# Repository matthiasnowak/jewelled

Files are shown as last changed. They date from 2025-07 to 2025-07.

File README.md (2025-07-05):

# JewelLED / LuxAura Earring

Jewelled Hardware

These stylish earrings have 18 small LEDs on them, which can light up in any pattern. A microphone allows for the potential to sync the patterns up to music. The whole earring is powered off a regular coin cell battery, and can even be used with lithium rechargeable coin cells! It runs around 10-12h at moderate animation load and brightness of a LIR2032 rechargeable Lithium battery

A seperate charging and programming board allows to interface the earrings with your PC, gives you simple access to the programming pin of the earrings and can be used to charge them up if used with lithium rechargeable coin cells.

## Hardware Overview:

### LuxAura 01:

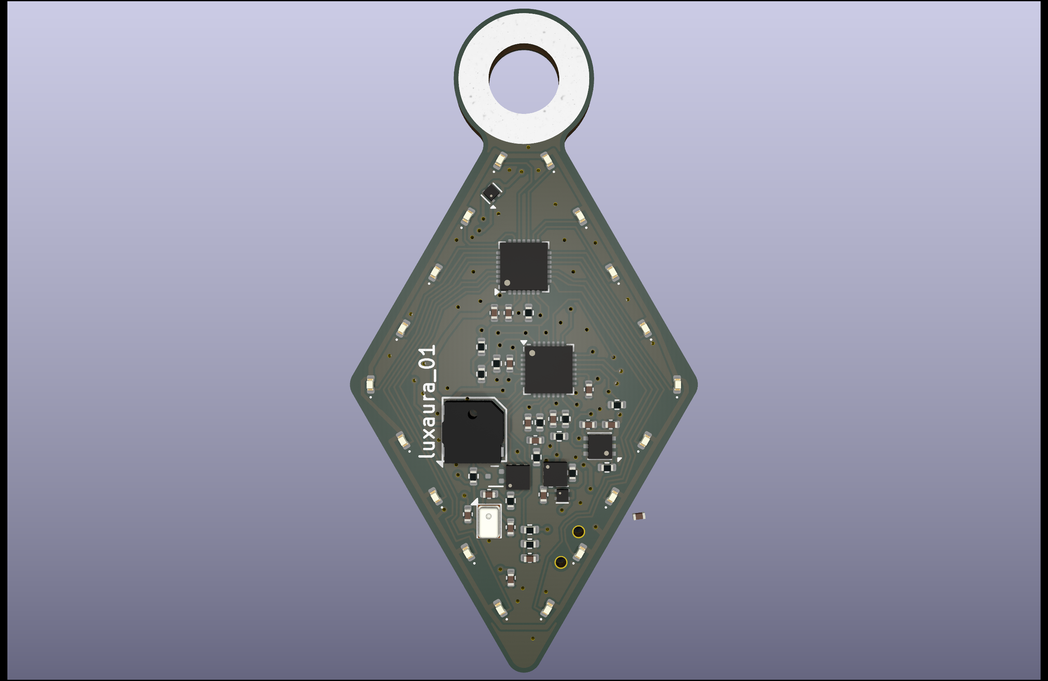
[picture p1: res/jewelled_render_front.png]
LuxAura 01 PCB Front


- WCH CH32V203G6U6 microcontroller
- 18 LEDs 0603, single color
- CR2032 battery holder
- optional LIR2032 charging and protection circuit
- Operating at 2.7V, allowing for low battery voltage operation
- 2 buttons and a power switch
- buzzer for audio user feedback
- microphone, which can be used for music detection

### LuxCharge:

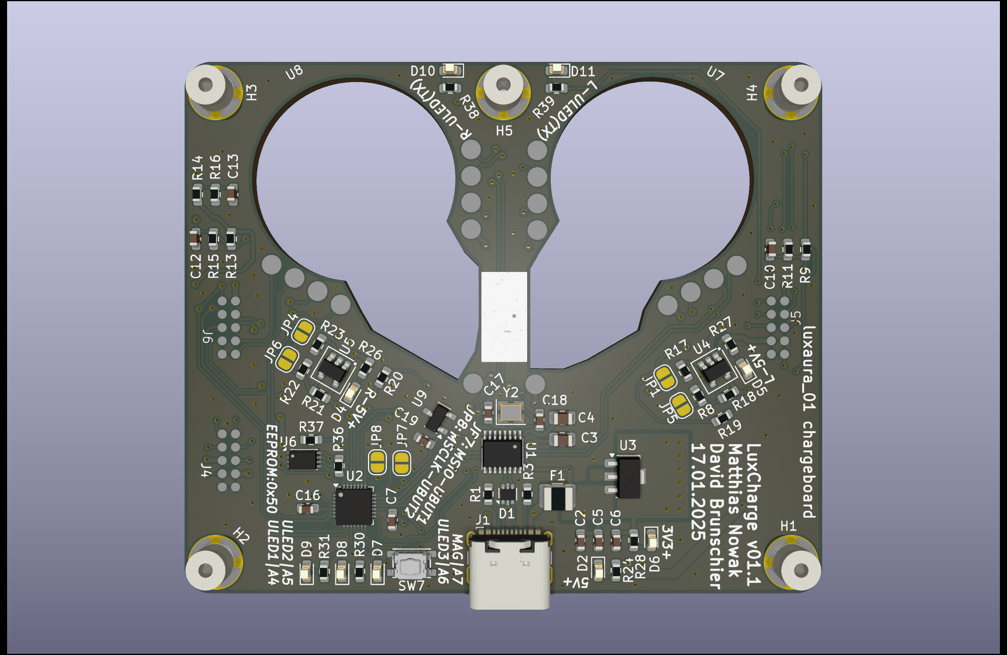
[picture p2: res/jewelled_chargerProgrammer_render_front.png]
LuxAura LuxCharge PCB Front


- TBD

## Software

Software is currently WIP. The charging board can activate/deactivate 5V charging voltage to the earrings and can rudimentely detect their presence.
The earring software can show basic animations and cycle between them. Test code for microphone sampling is running, but currently beat detection doesnt work.

## Ressources and other notes

- Images, schematics and PCB plots can be found in the "res" folder.
- Development is published here, issues are used for internal issue and project tracking. Feel free to contribute
- The PCBs can be ordered through Turnkey PCBA providers like JLCPCB.

## License

The attached LICENSE.md file contains information about the license.

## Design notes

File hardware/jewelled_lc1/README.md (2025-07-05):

# LuxAura 01 Earring Hardware

## Hardware Overview

- WIP

## Notes

- WIP
- Please note the correct jumper settings to allow either CR2032 or LIR2032 use (bridging the charging circuit)

## Images

LuxAura 01 PCB Render Front
LuxAura 01 PCB Render Back
LuxAura 01 PCB
LuxAura 01 Schematic

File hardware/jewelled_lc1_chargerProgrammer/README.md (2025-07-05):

# LuxAura LuxCharger Hardware

## Hardware Overview

- WIP

## Notes

- WIP
- Please note the correct jumper settings to allow communications or setting pullup/down resistors

## Images

LuxAura LuxCharge PCB Render Front
LuxAura LuxCharge PCB Render Back
LuxAura LuxCharge PCB
LuxAura LuxCharge Schematic

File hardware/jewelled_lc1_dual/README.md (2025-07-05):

# LuxAura 01 Dual Earring Hardware

## Notes

This is a panel meant for production of the Earrings, allowing for 2 Earrings per panel.

## Images

LuxAura 01 Dual PCB Render Front
LuxAura 01 Dual PCB Render Back
LuxAura 01 Dual PCB
LuxAura 01 Dual Schematic

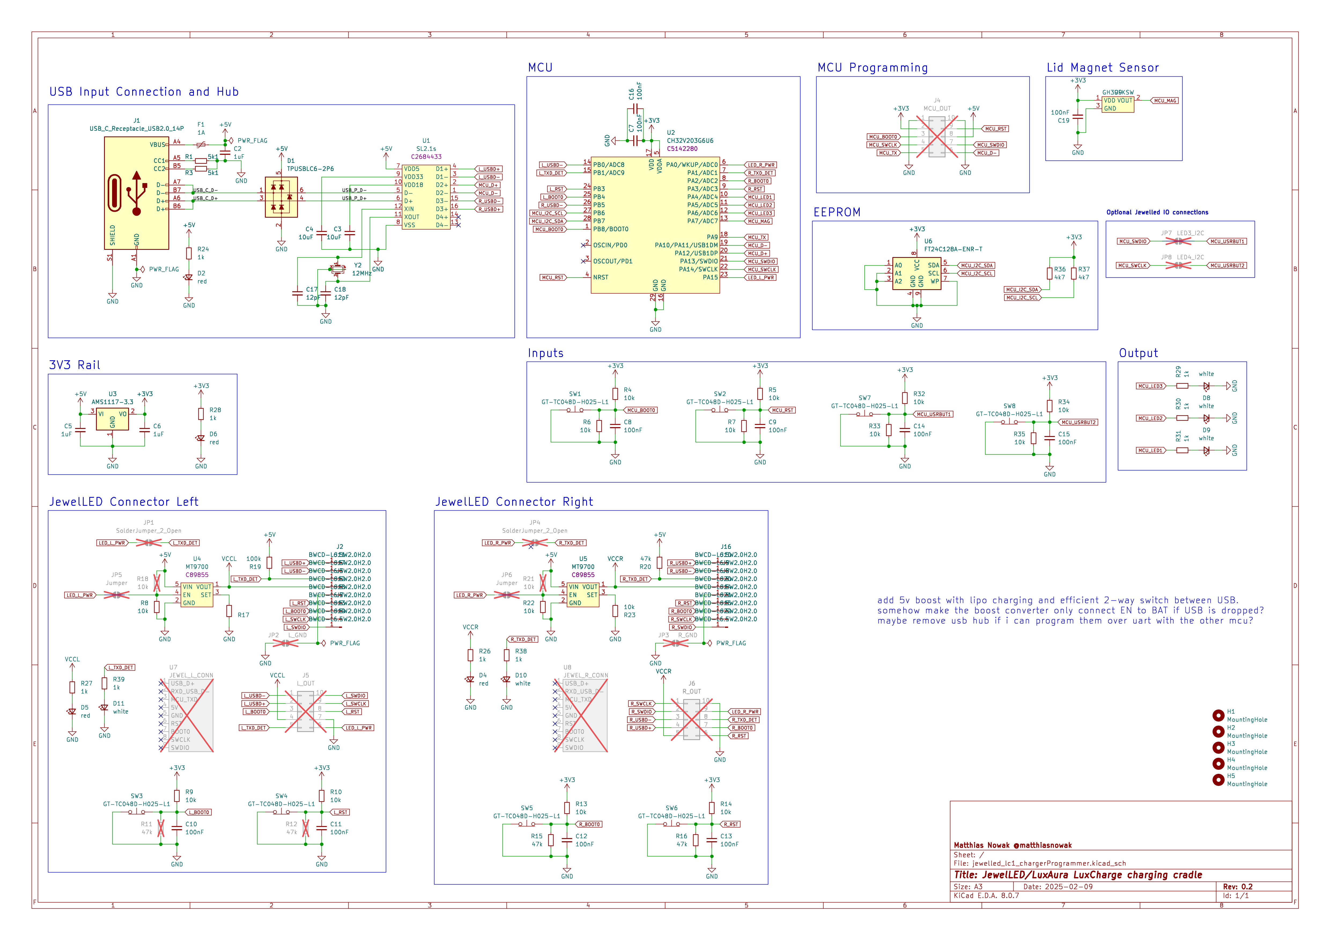
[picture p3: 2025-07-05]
res/jewelled_chargerProgrammer_schematic.png

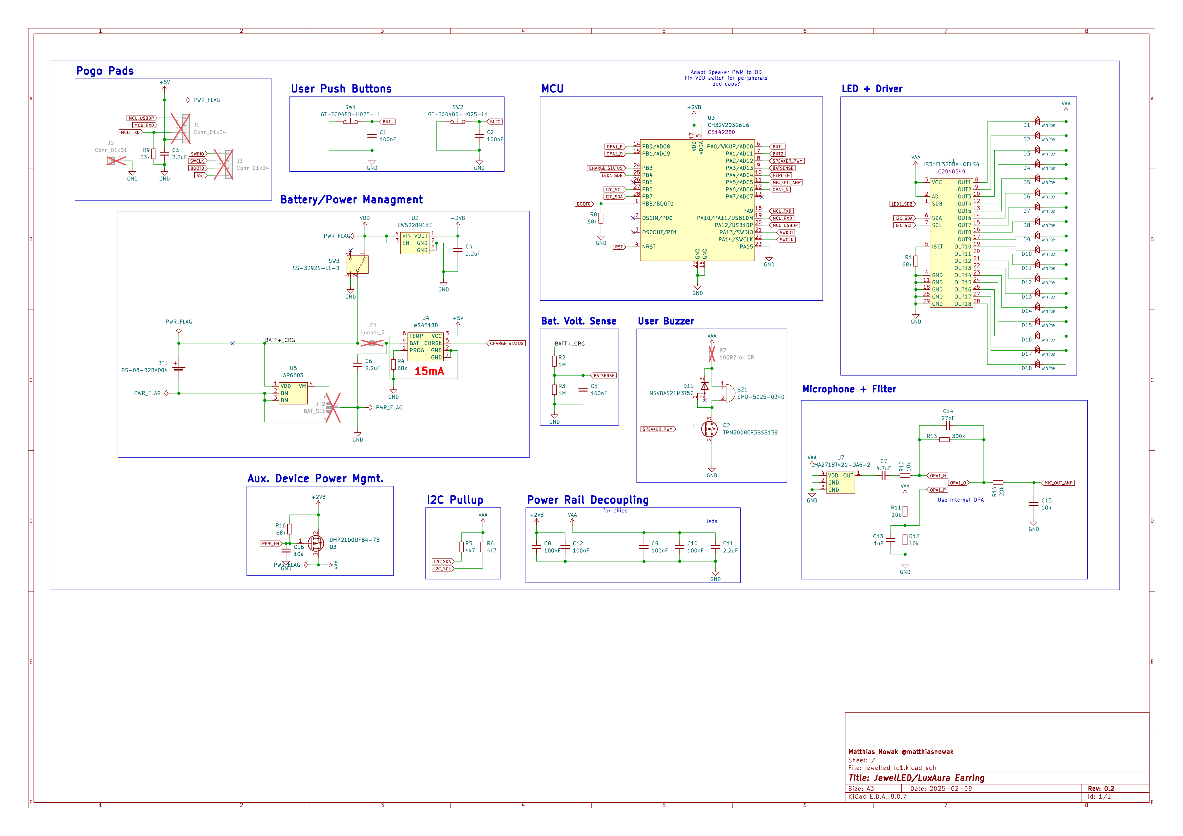
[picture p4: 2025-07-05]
res/jewelled_schematic.png

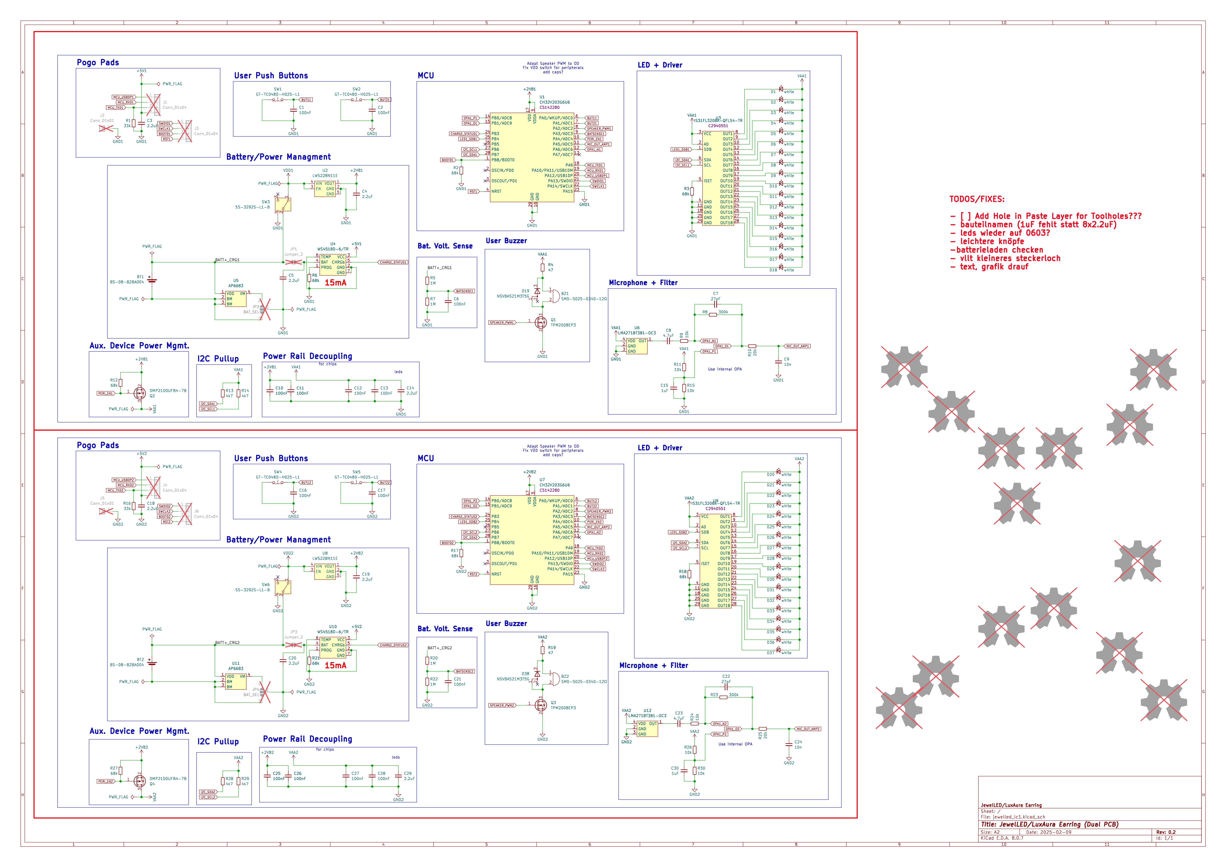
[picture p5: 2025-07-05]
res/jewelled_dual_schematic.png

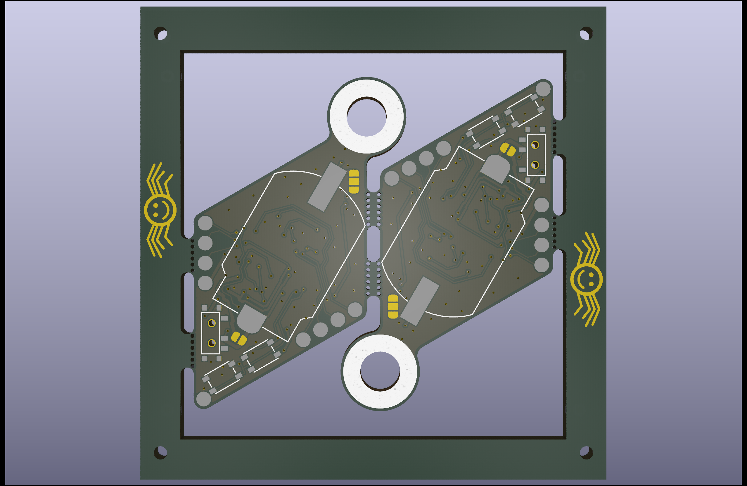
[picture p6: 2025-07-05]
res/jewelled_dual_render_back.png

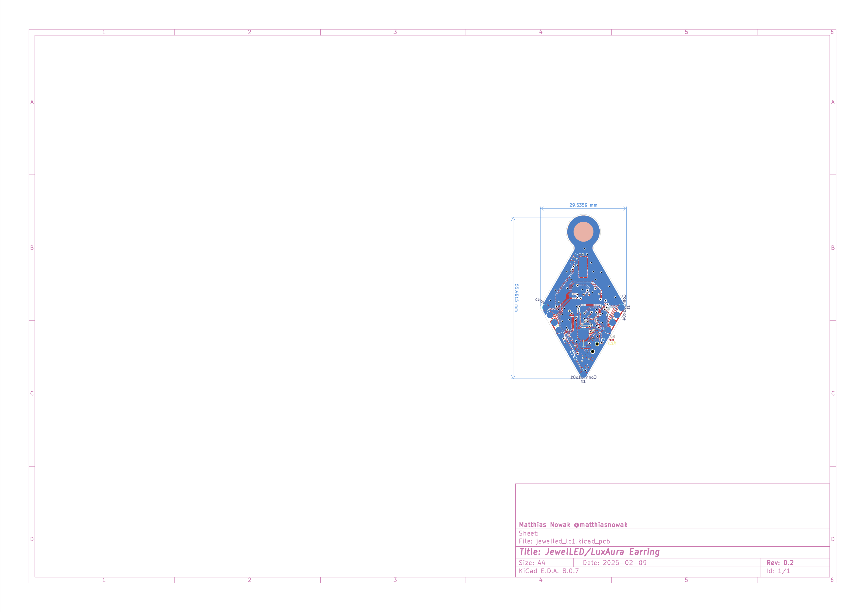
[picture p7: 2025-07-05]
res/jewelled_pcb_combined.png

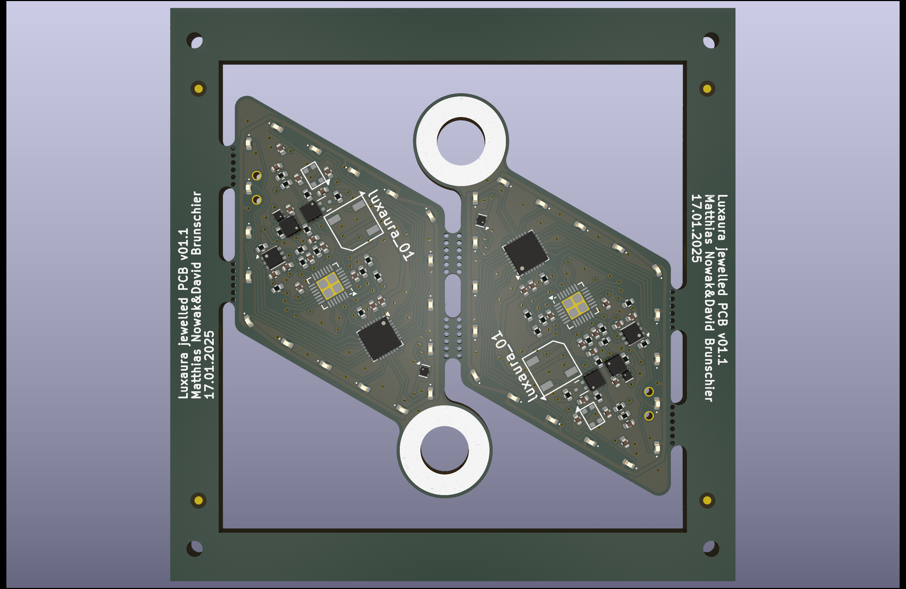
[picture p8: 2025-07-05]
res/jewelled_dual_render_front.png

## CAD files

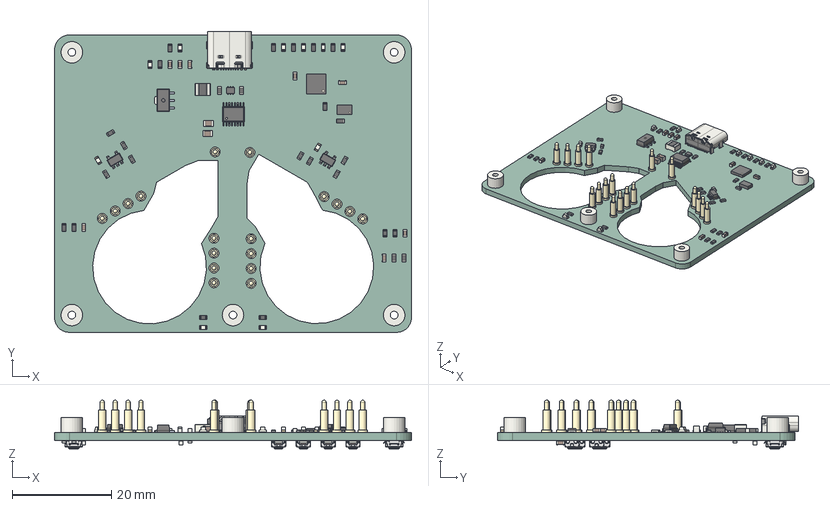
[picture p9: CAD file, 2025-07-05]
hardware/jewelled_lc1_chargerProgrammer/jewelled_lc1_chargerProgrammer.step
72.0 x 60.7 x 9.83 mm
SOT_23_5 x 2
R_0603_1608Metric x 33
C_0603_1608Metric x 14
LED_0603_1608Metric x 10
Fuse_1210_3225Metric
C_0805_2012Metric x 2
Mounting_Wuerth_WA_SMSI_M2_H3mm_9774030243 x 5
QFN-28-1EP_4x4mm_Pitch0.4mm
pogopin_fp v1 x 2
CQ assembly
SOT_666
SSOP_16_39x49mm_P0635mm
DFN-8-1EP_3x2mm_P0.5mm_EP1.7x1.6mm
USB_C_Receptacle_16P_TopMnt_Horizontal_GCT_USB4105-xx-A
jewelled_lc1_chargerProgrammer_PCB

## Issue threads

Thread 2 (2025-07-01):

Problems: Decide on pullup/downs for detection of the jewelleds in the charging cradle

matthiasnowak, 2025-07-01:
detection of jewelleds in the charging cradle still seems bit weird, especially in scenarios where the cradle is unpowered but the jewelled is still on. Probably is just a thing of calculating the correct pullup/down on the io and reset lines

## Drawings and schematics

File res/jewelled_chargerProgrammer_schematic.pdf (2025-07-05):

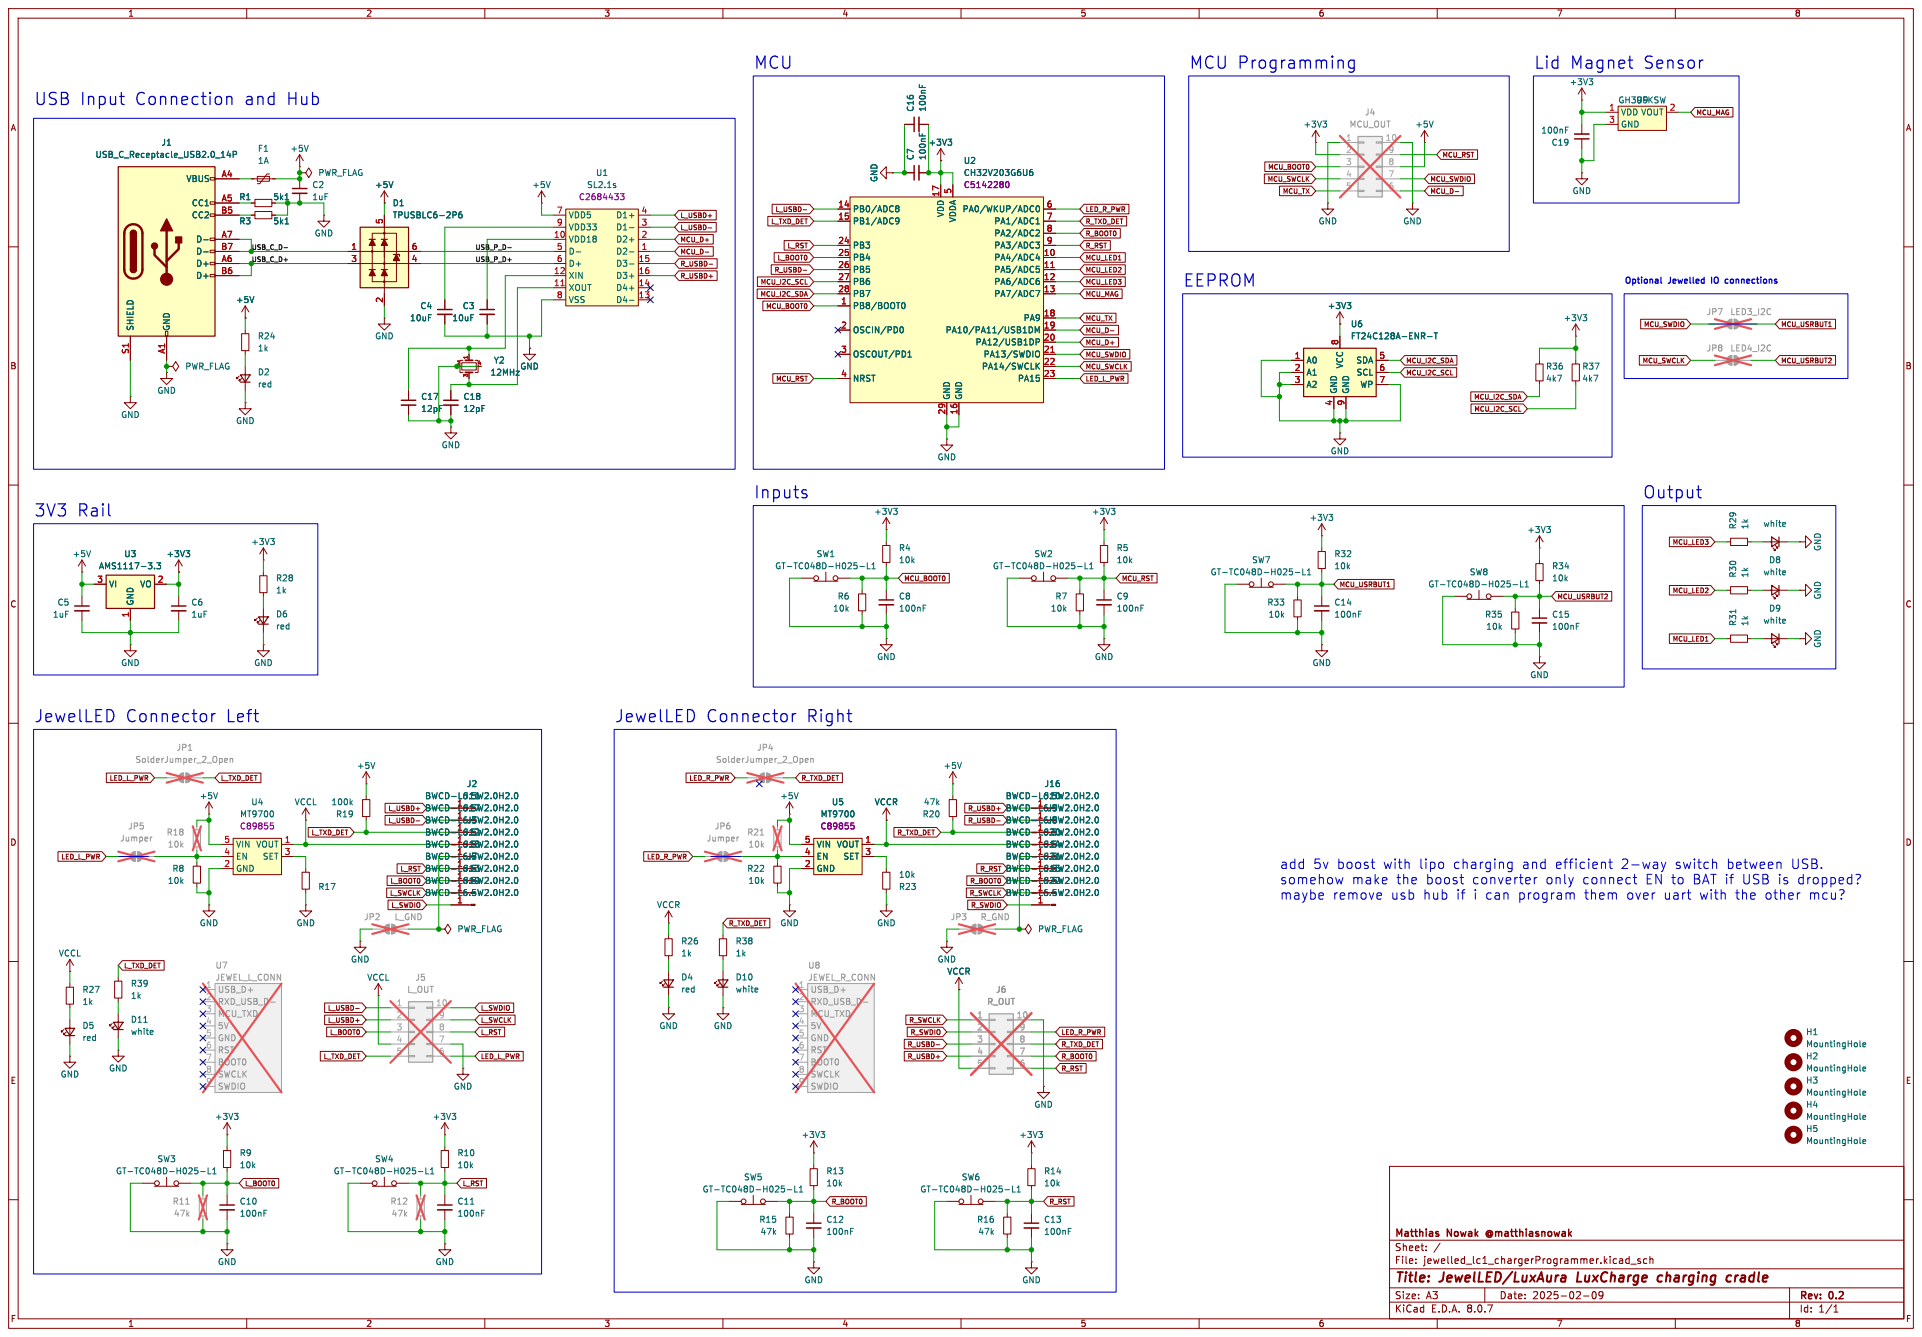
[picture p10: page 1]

USB Input Connection and Hub

Optional Jewelled IO connections Output

4 SDA 5 SCL 6 WP 7 VCC

somehow make the boost converter only connect EN to BAT if USB is dropped?
maybe remove usb hub if i can program them over uart with the other mcu?

H2 MountingHole H5 MountingHole H3 MountingHole H4 MountingHole H1 MountingHole

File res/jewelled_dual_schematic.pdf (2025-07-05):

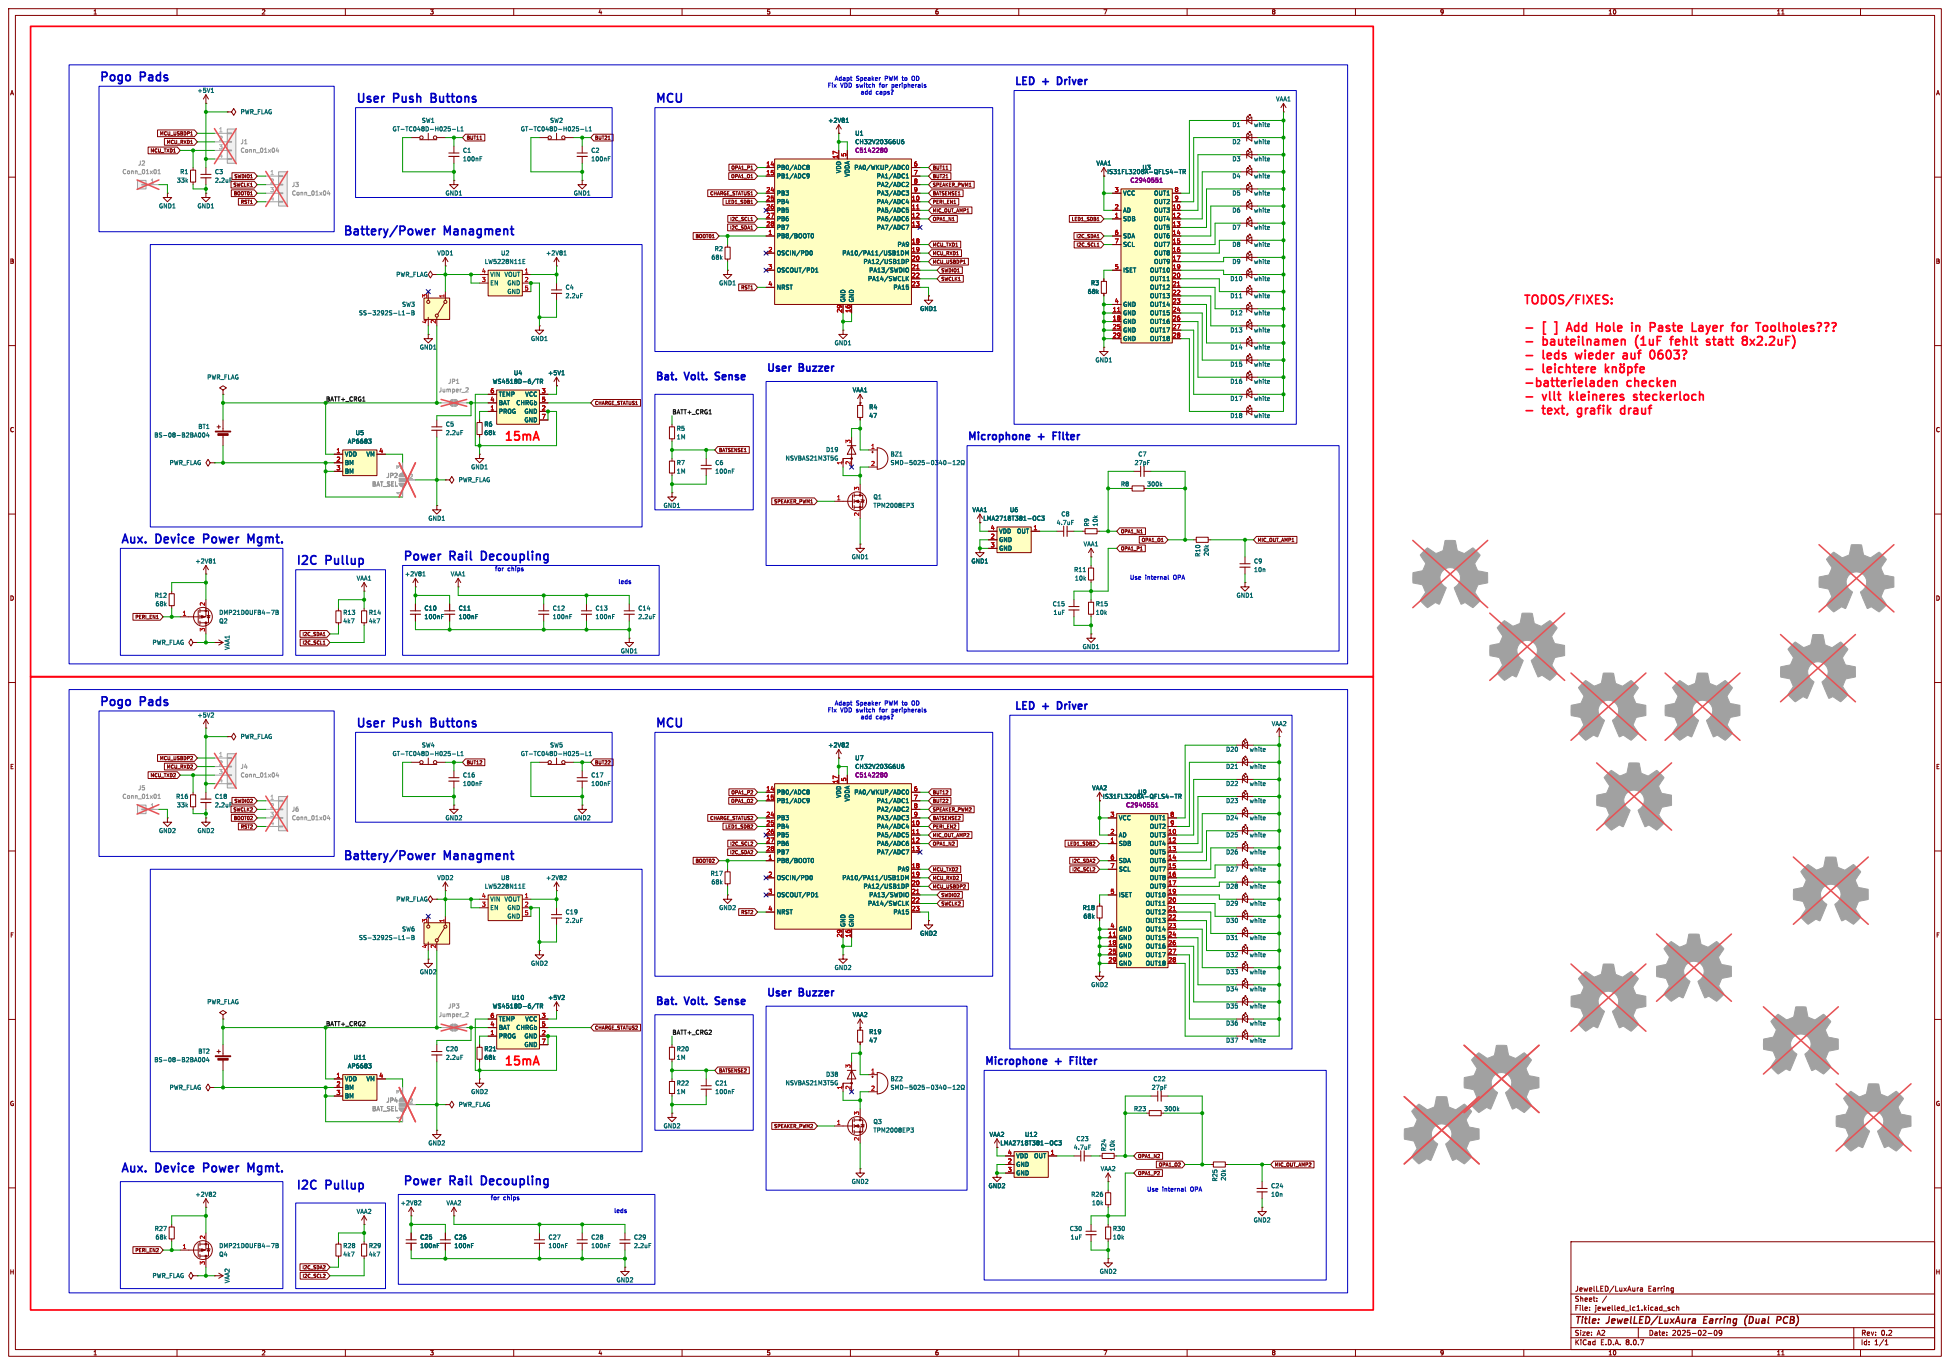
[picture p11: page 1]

Adapt Speaker PWM to OD
Fix VDD switch for peripherals add caps?

- [ ] Add Hole in Paste Layer for Toolholes???
- leds wieder auf 0603?
- leichtere þÿknöpfe
- vllt kleineres steckerloch
- text, grafik drauf

3 U5 AP6683 VDD 1 BM 2 BM 3 VM 4 C11

Aux. Device Power Mgmt.

LMA2718T381-OC3 PWR_FLAG

LMA2718T381-OC3 OUT 1 GND 2 GND 3 VDD 4

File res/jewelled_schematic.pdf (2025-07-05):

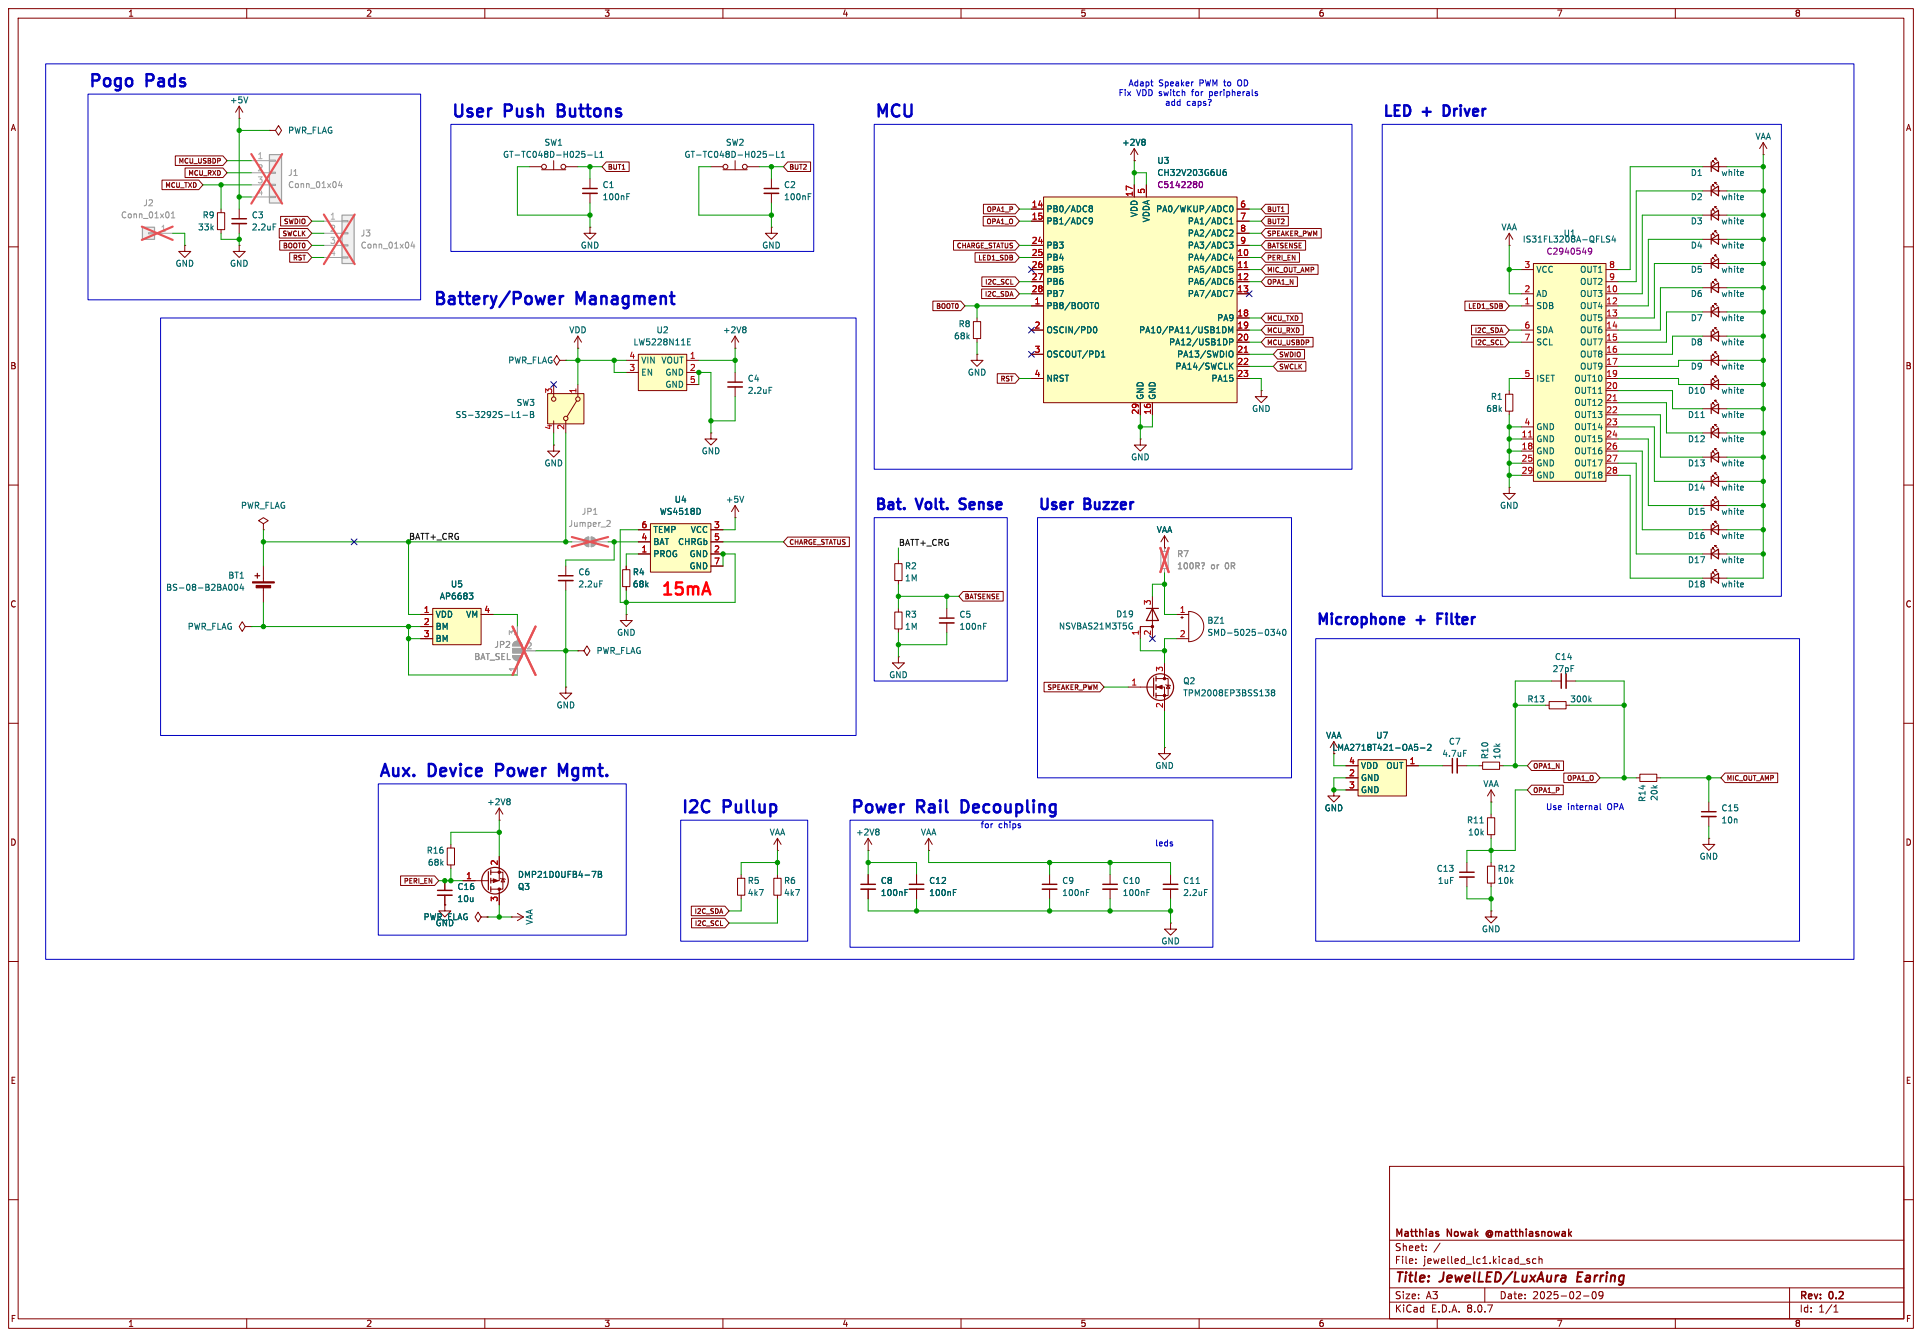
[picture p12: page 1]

Adapt Speaker PWM to OD
Fix VDD switch for peripherals add caps?

3 R4 U5 68k AP6683 VDD 1 BM 2 BM 3 VM 4 U4 WS4518D

LMA2718T421-OA5-2 OUT 1 GND 2 GND 3 VDD 4 VAA GND

Aux. Device Power Mgmt.

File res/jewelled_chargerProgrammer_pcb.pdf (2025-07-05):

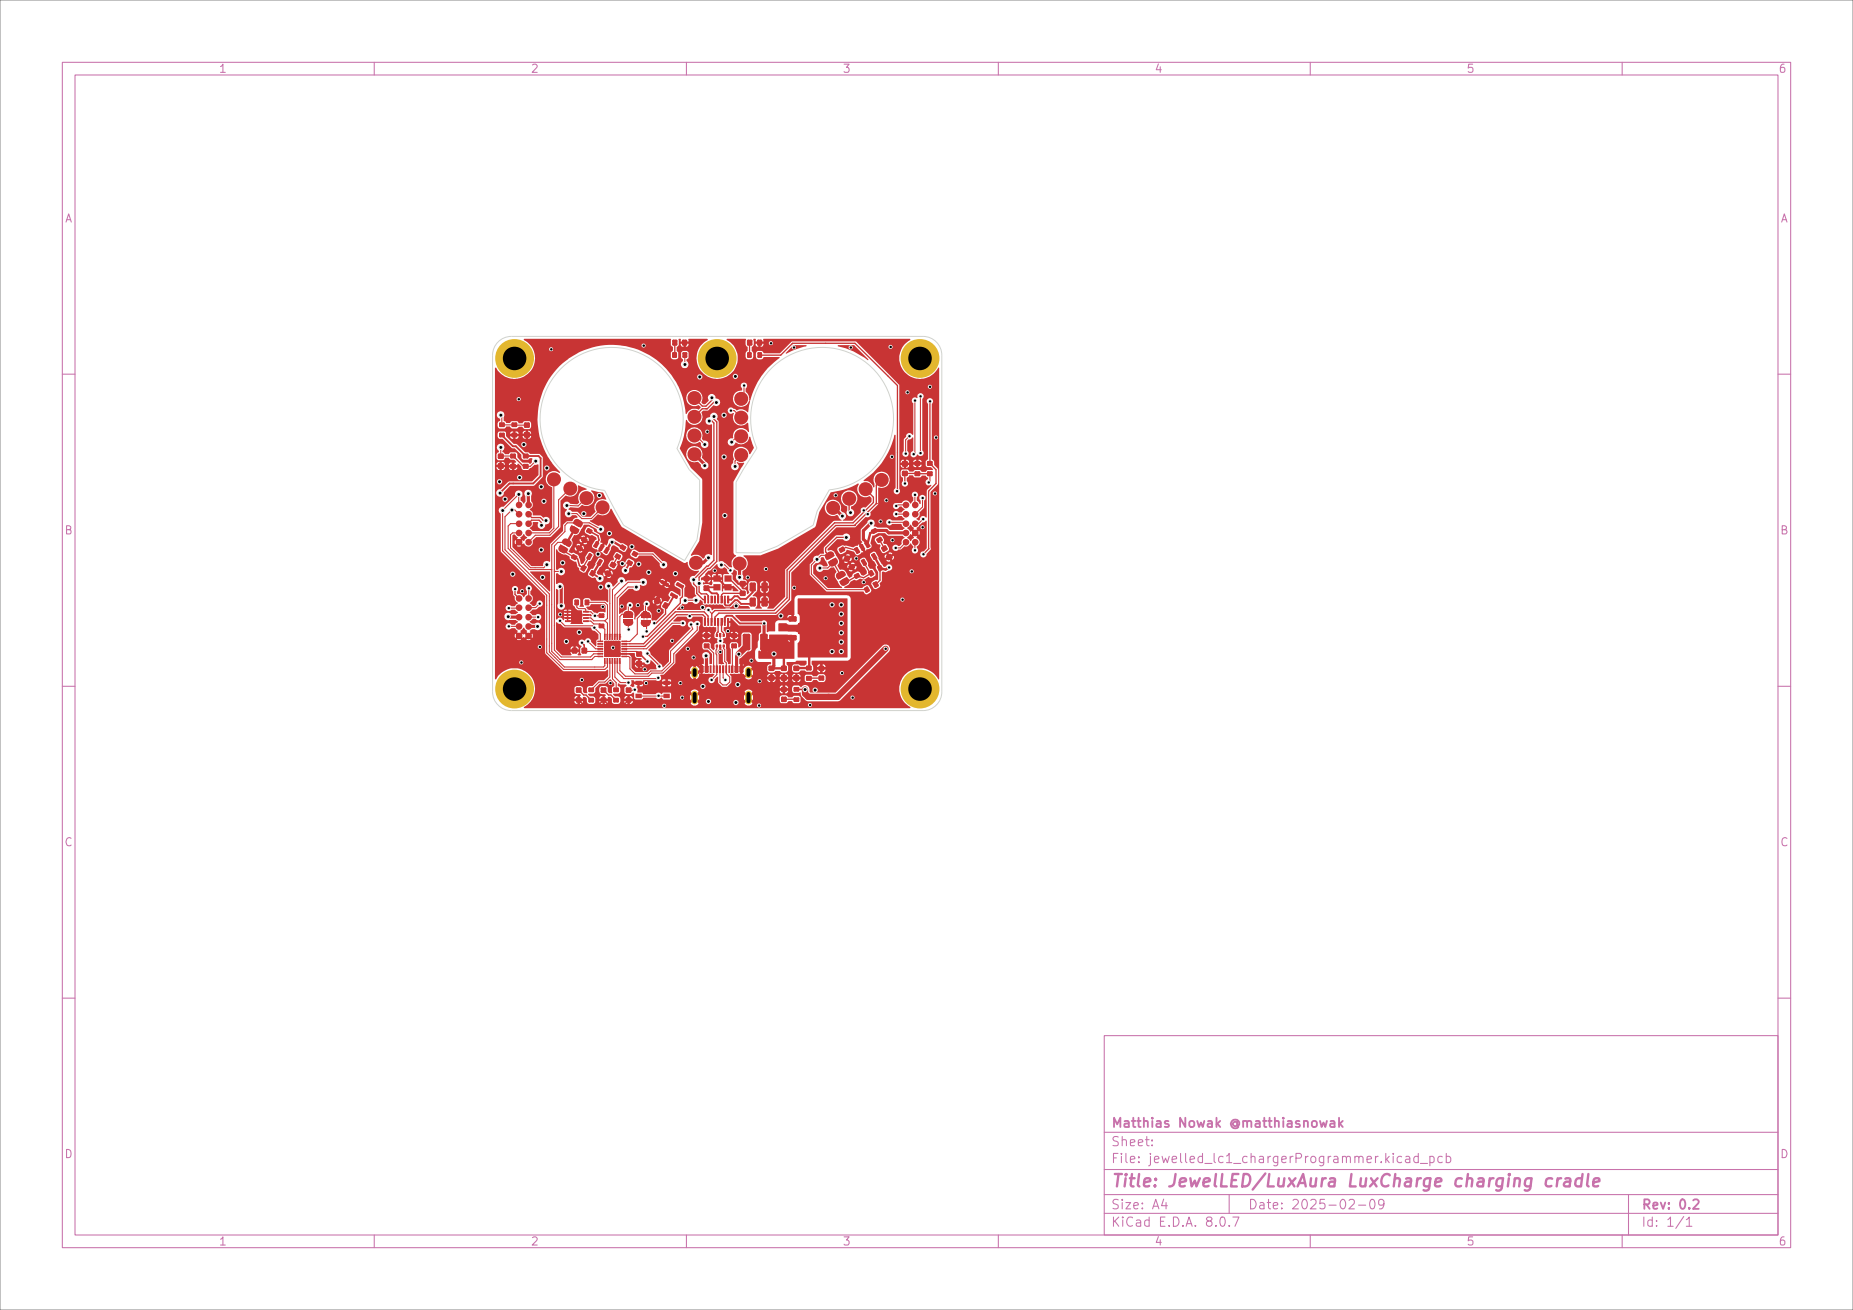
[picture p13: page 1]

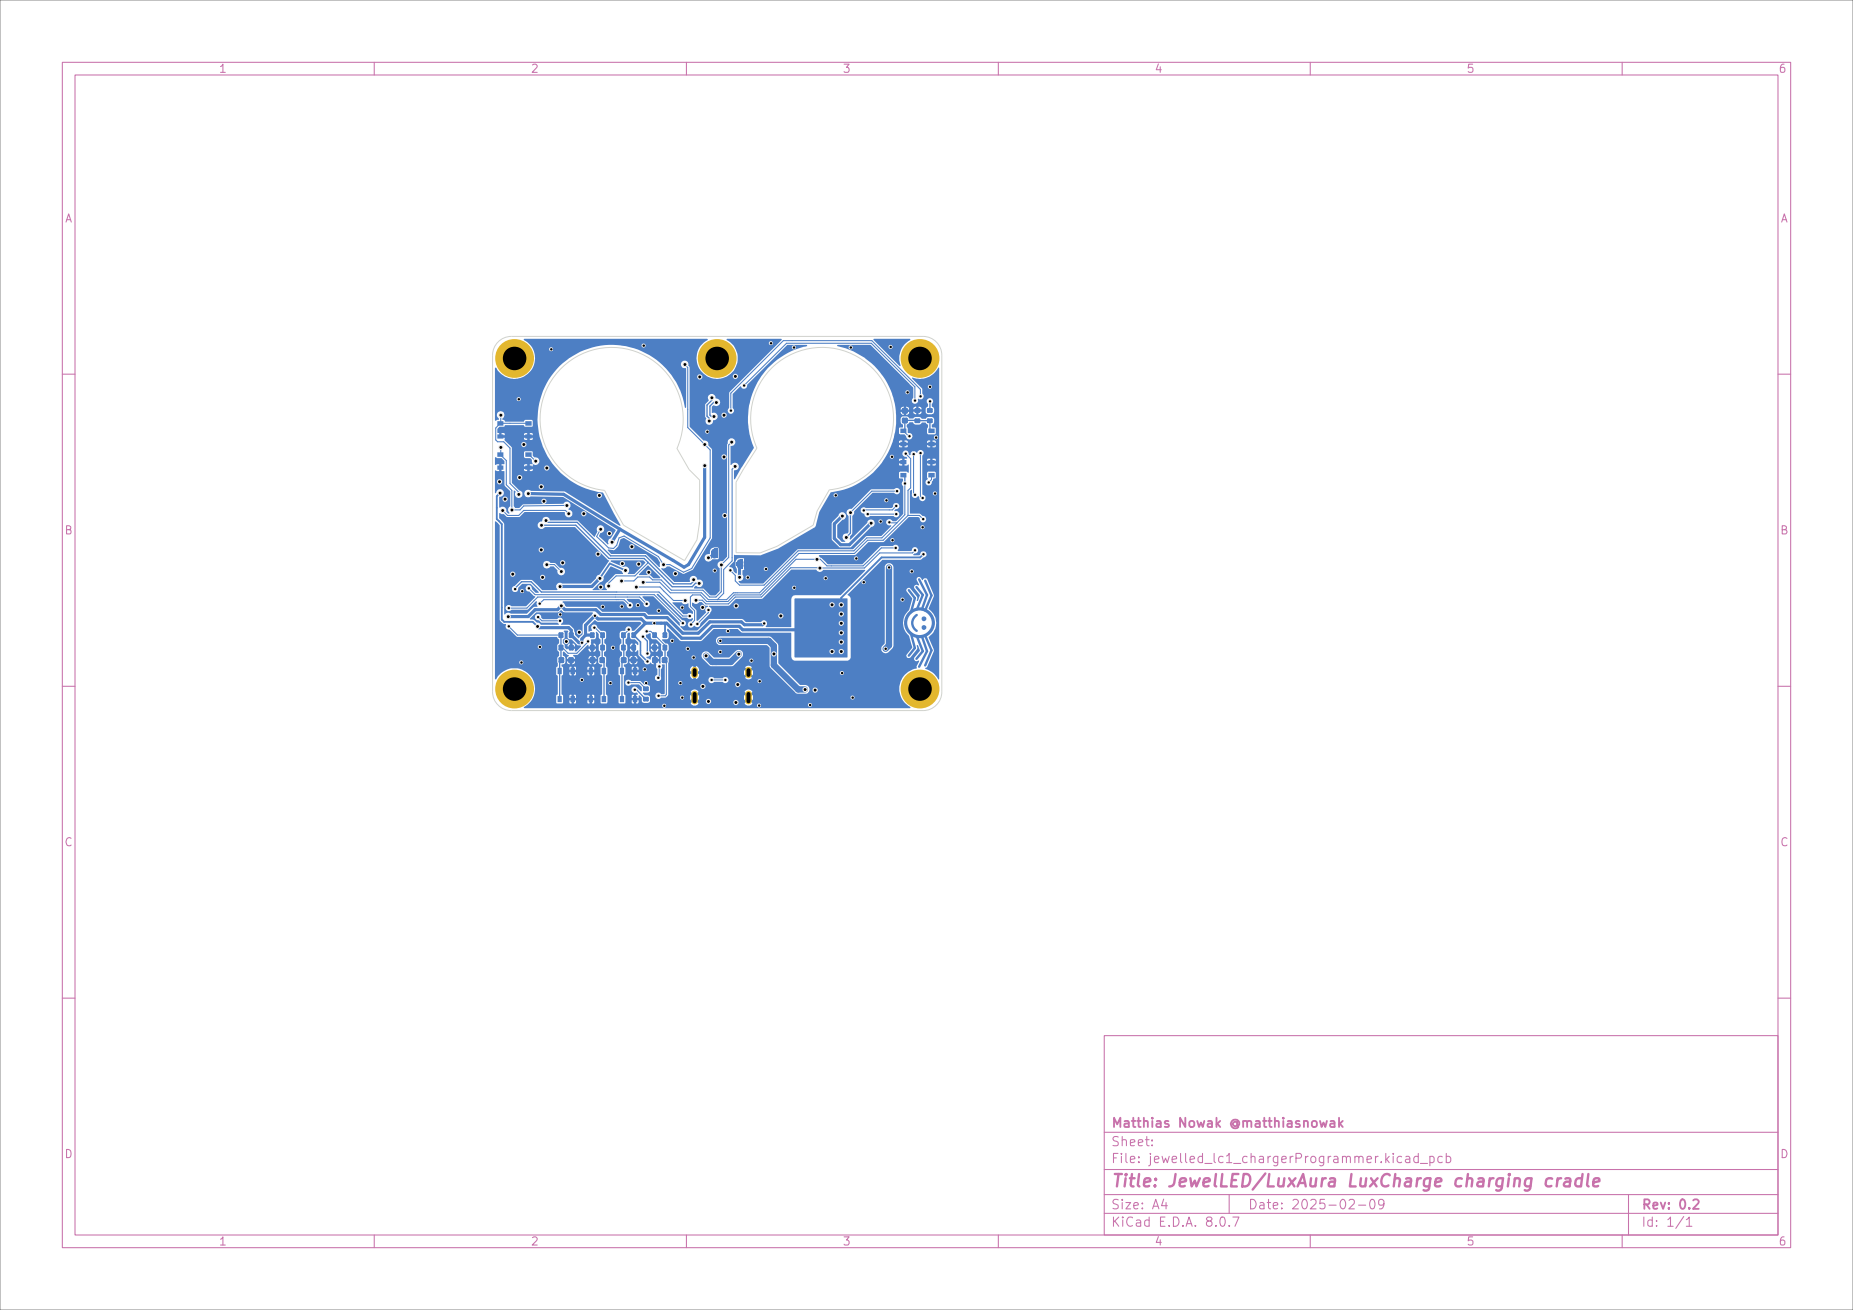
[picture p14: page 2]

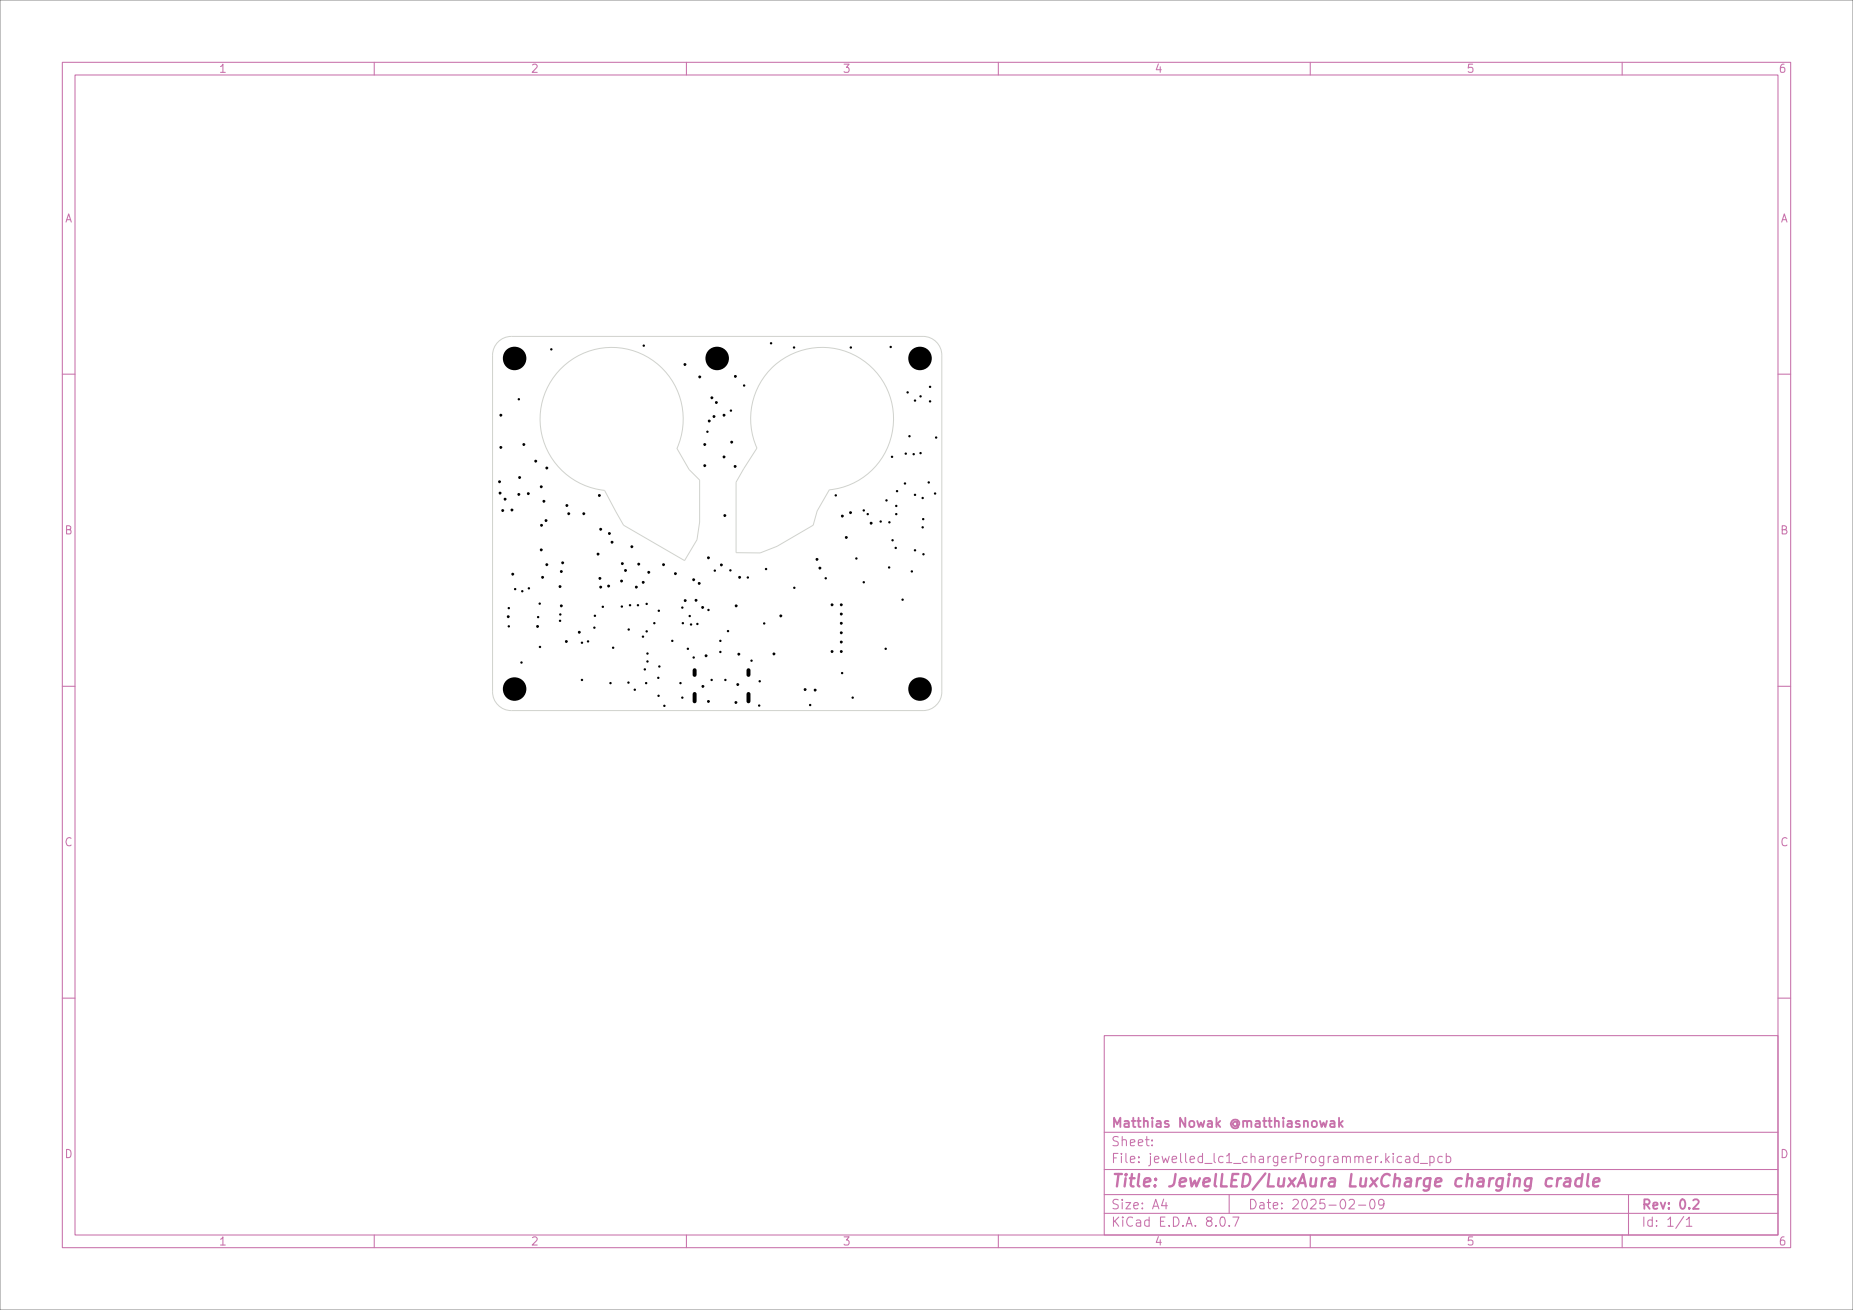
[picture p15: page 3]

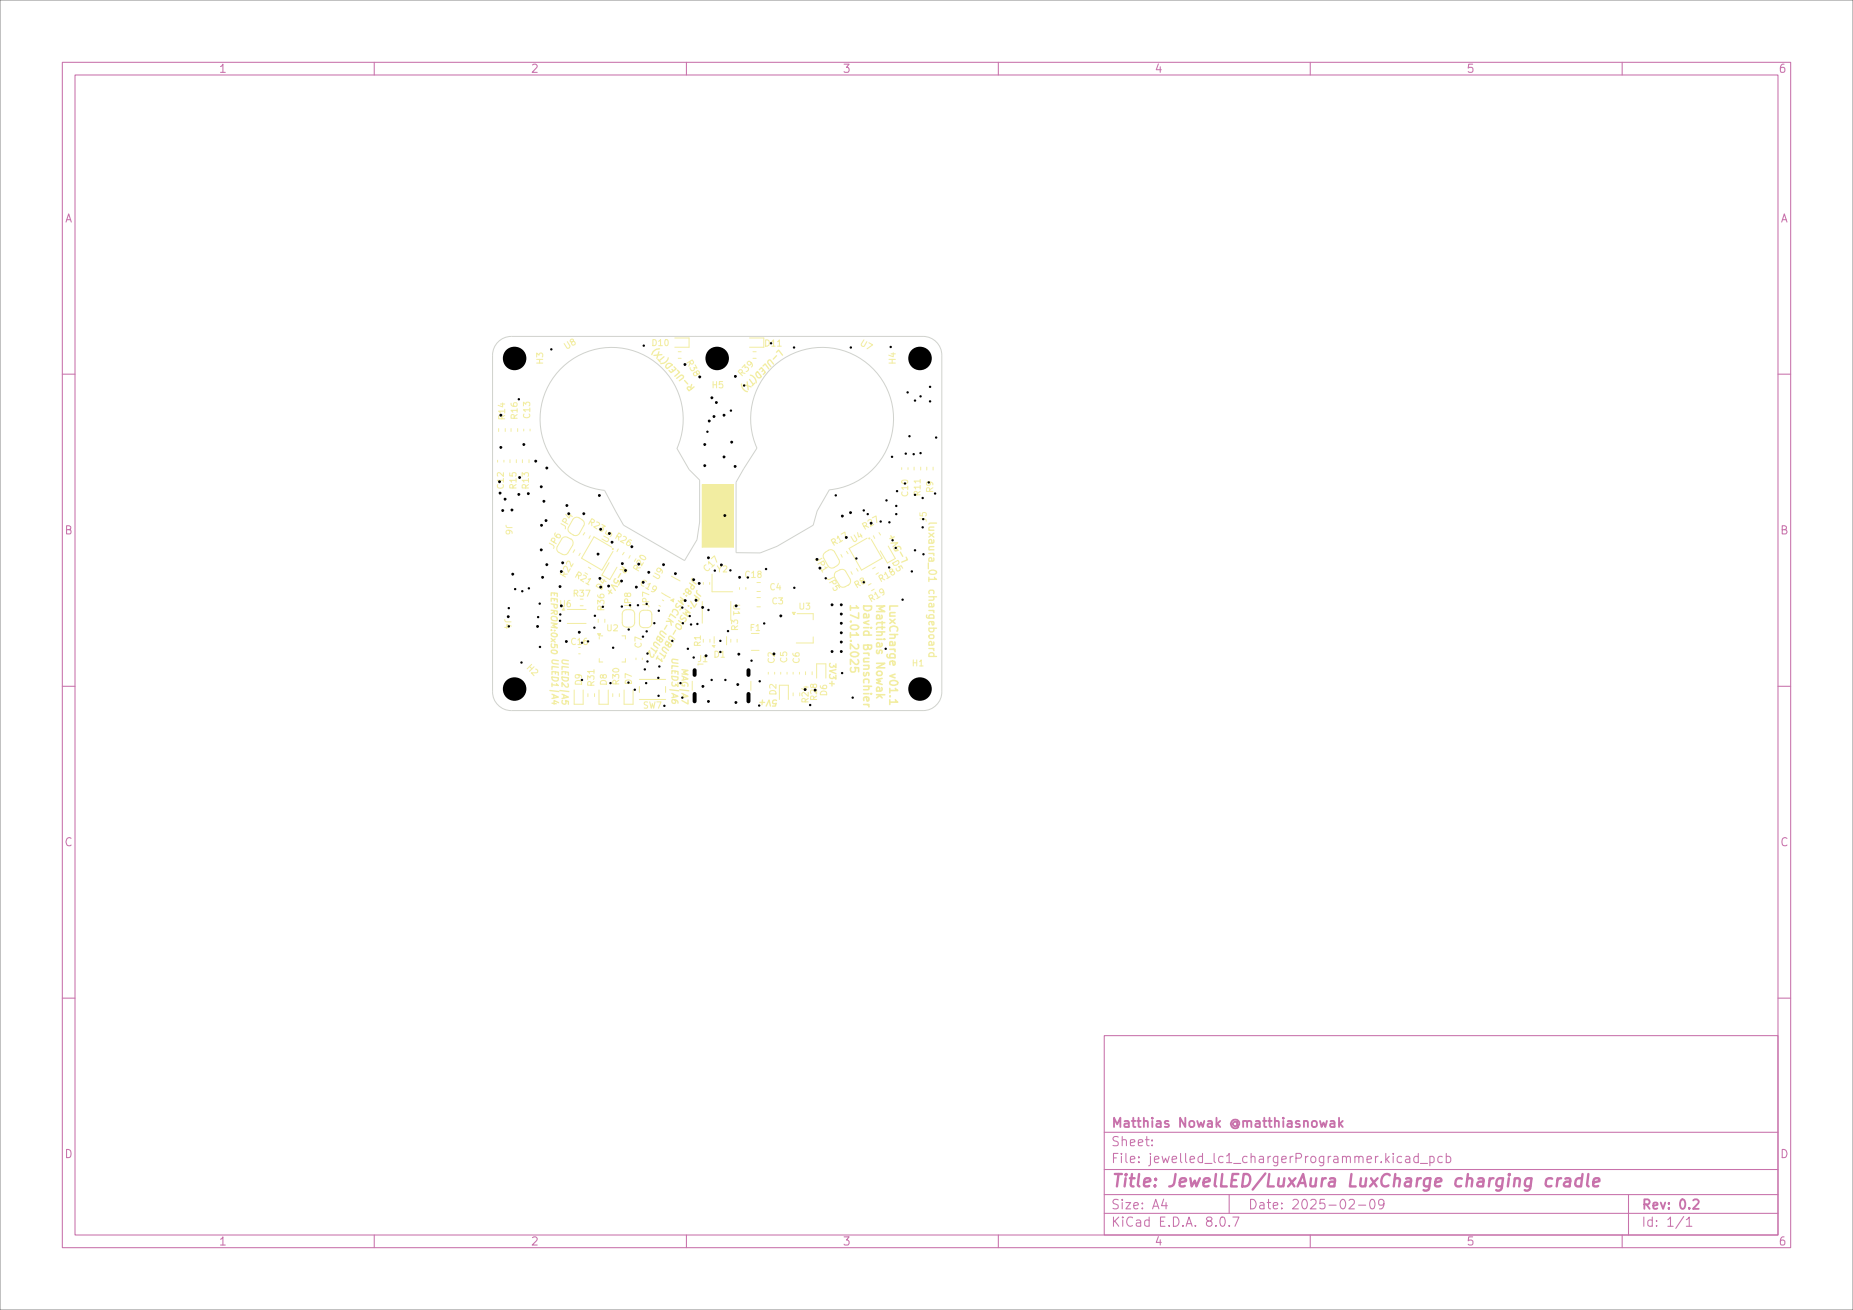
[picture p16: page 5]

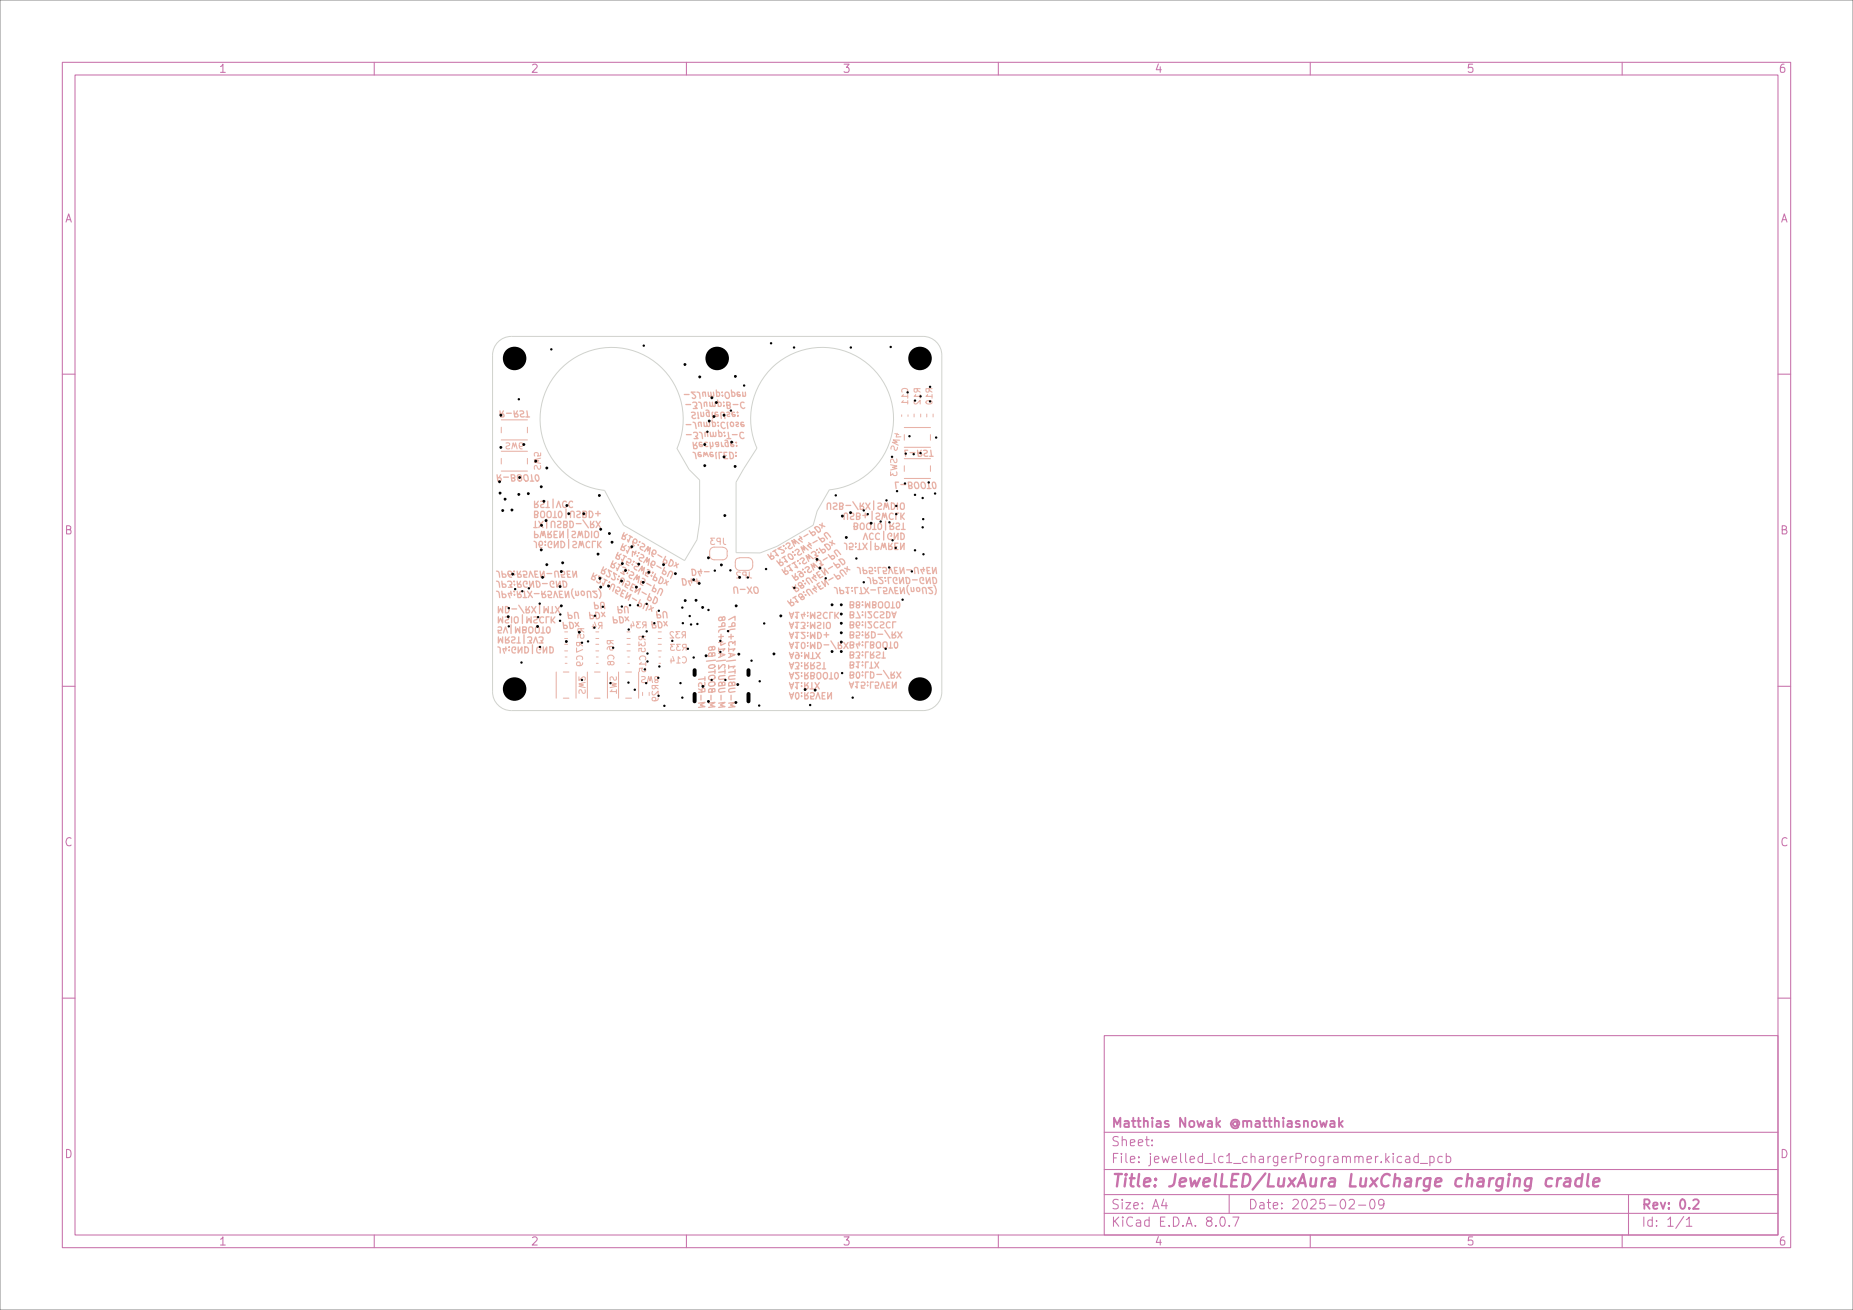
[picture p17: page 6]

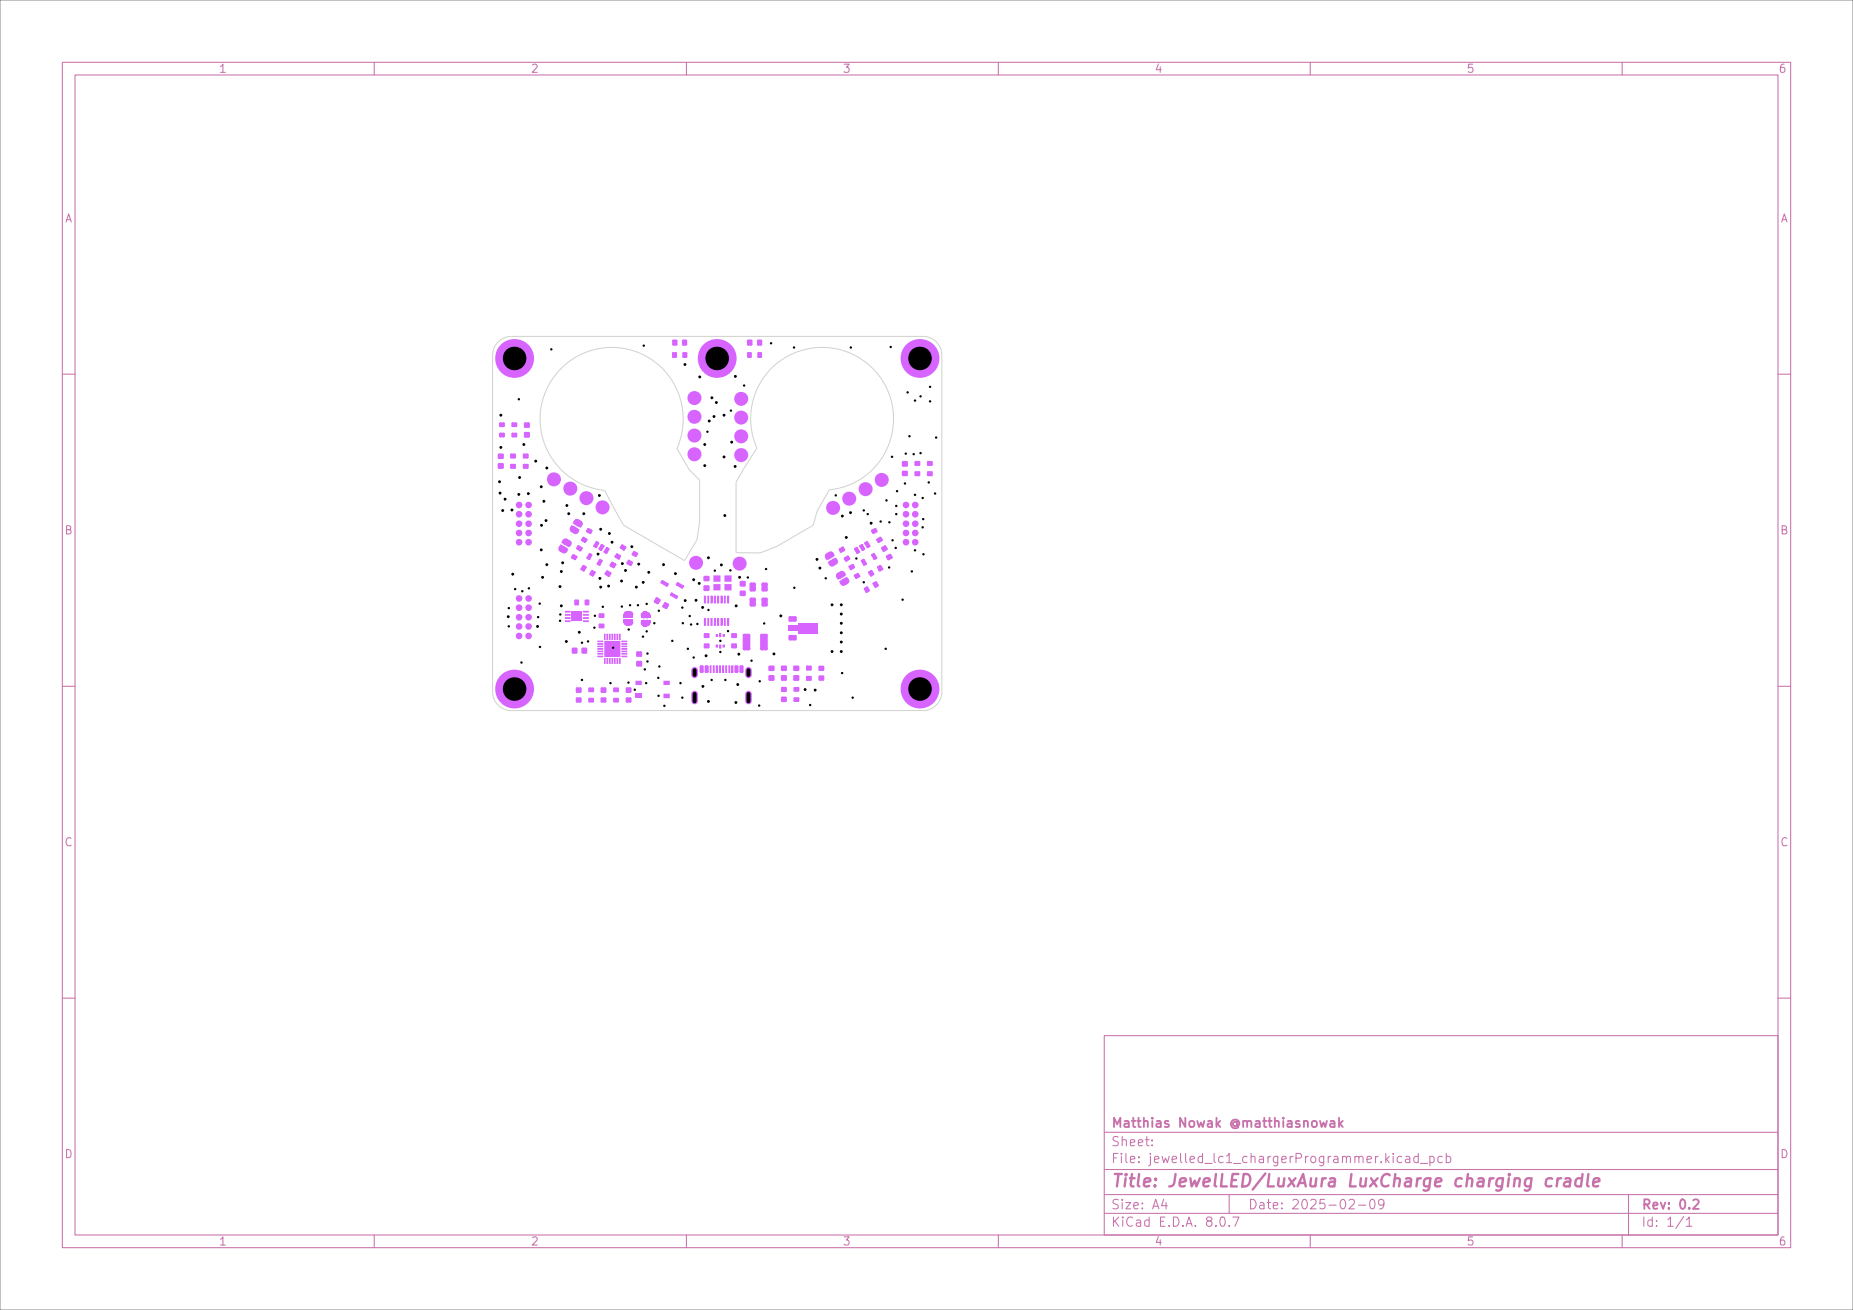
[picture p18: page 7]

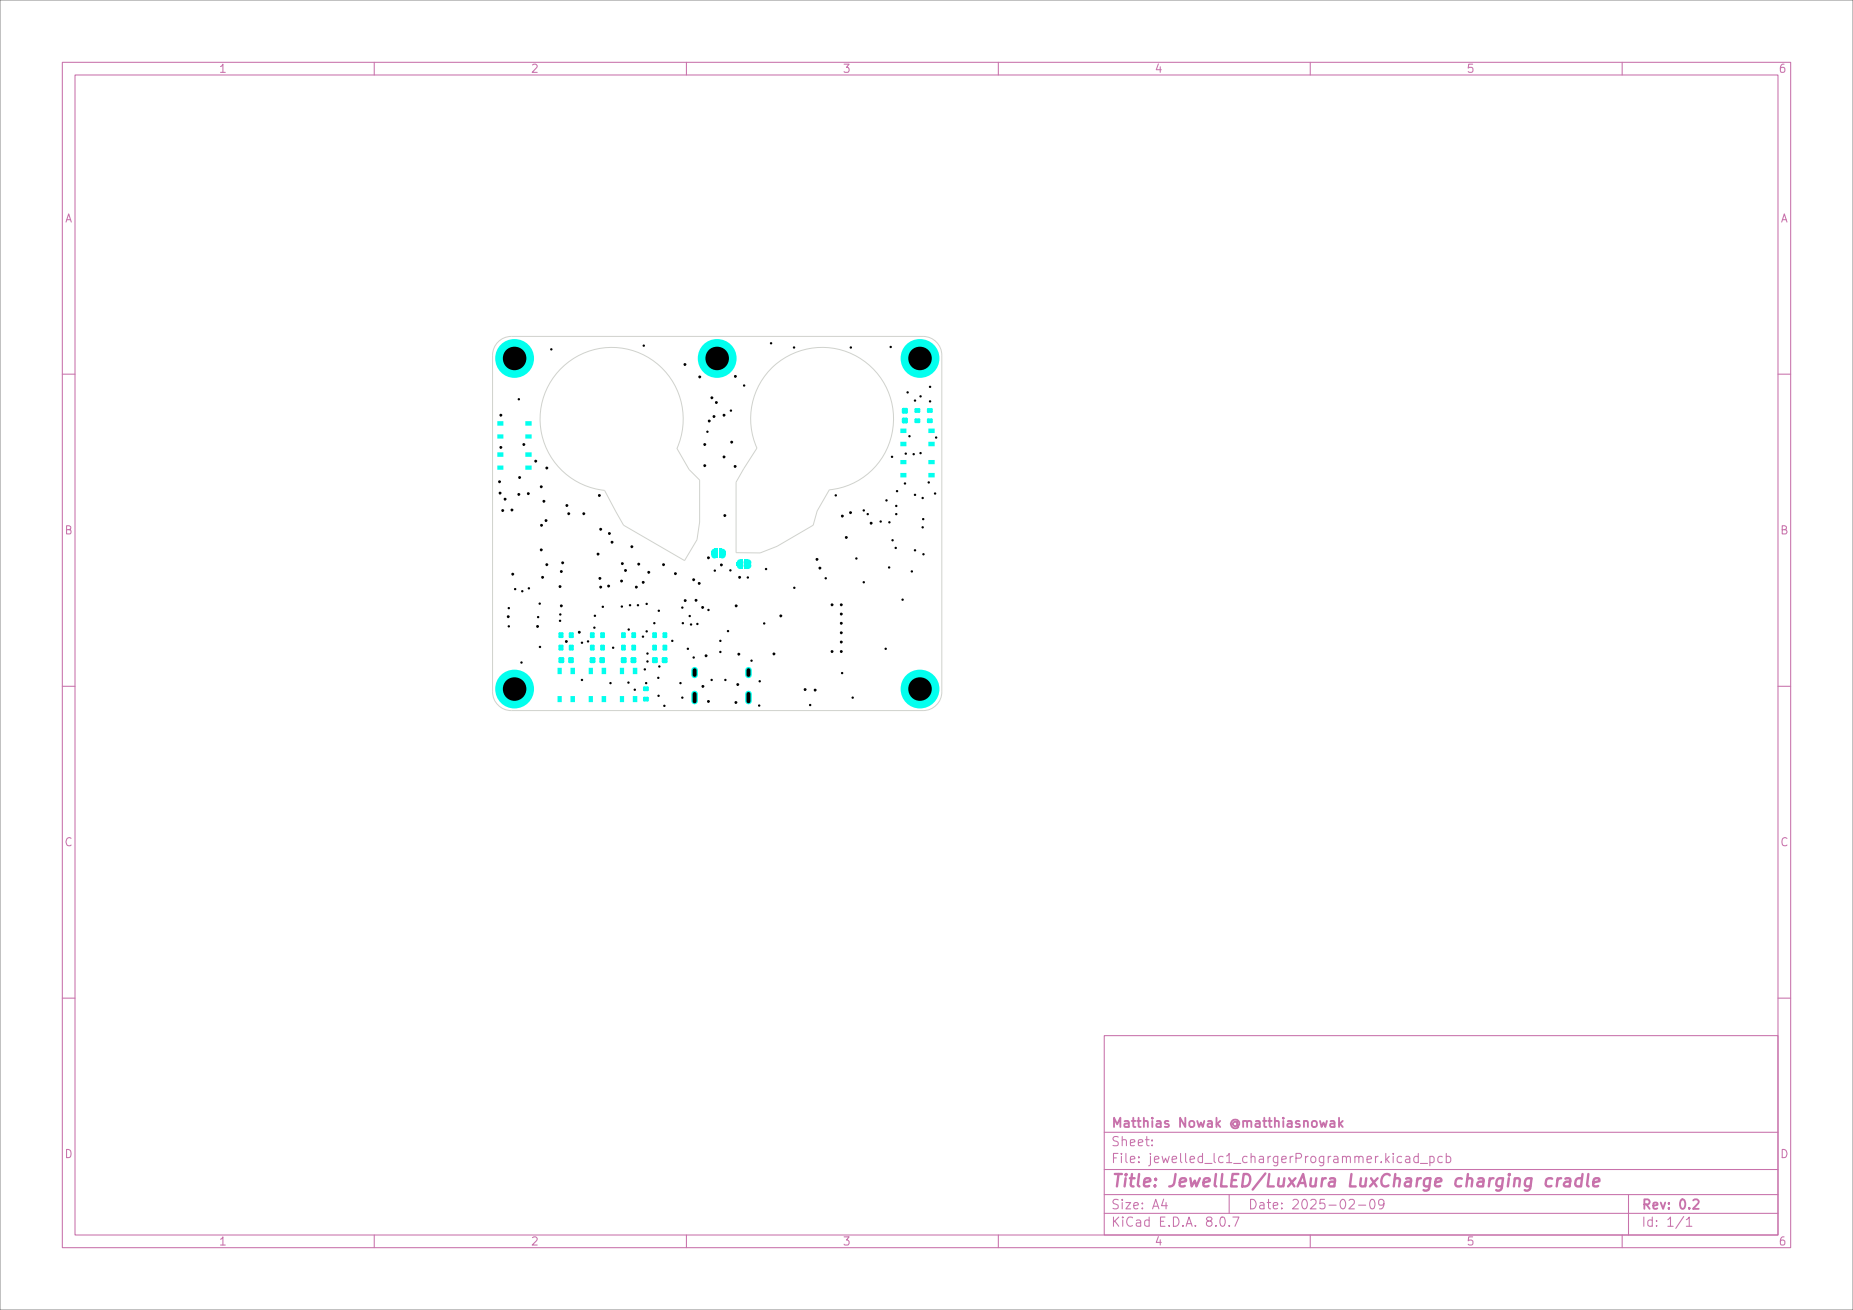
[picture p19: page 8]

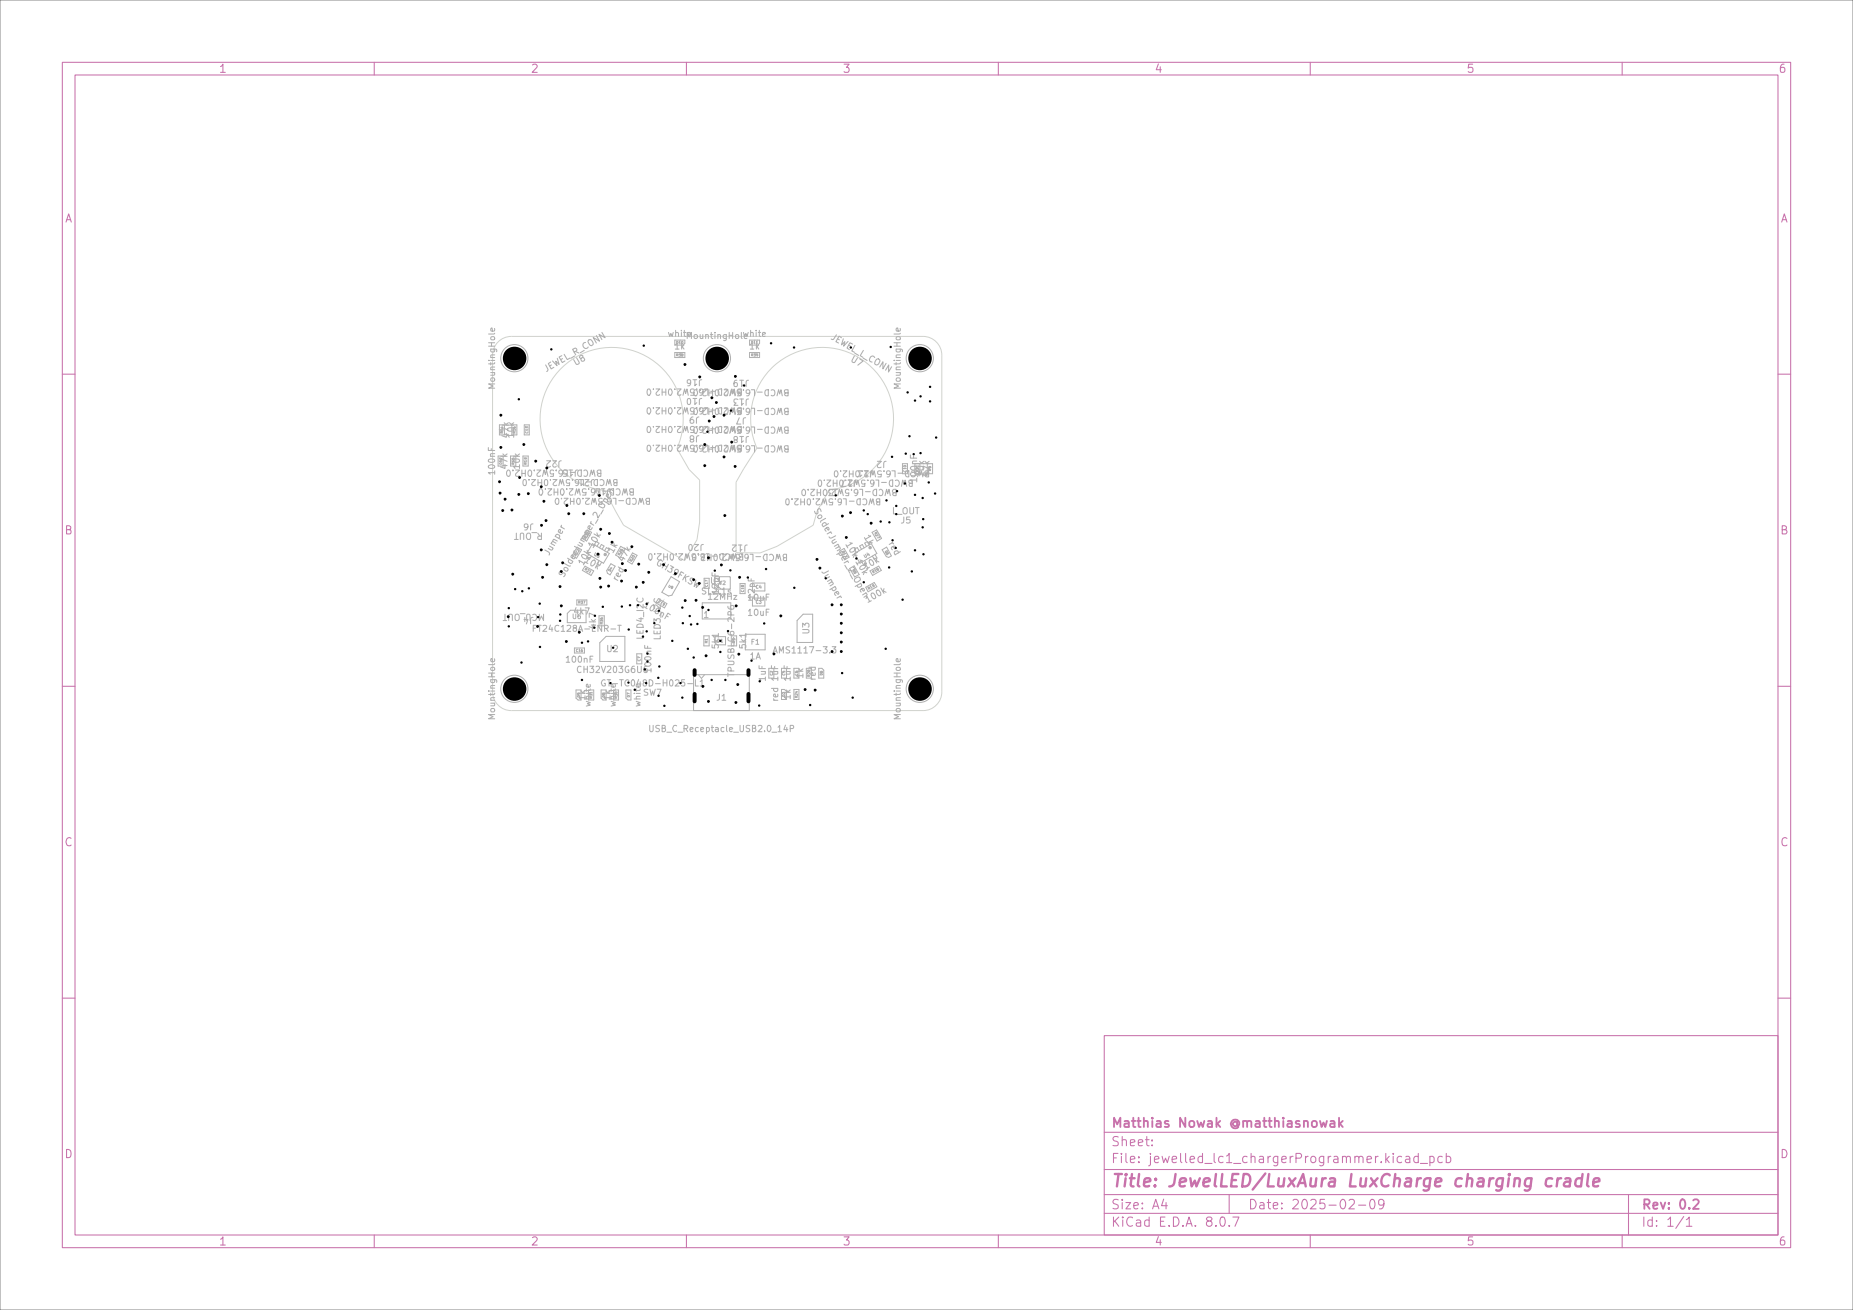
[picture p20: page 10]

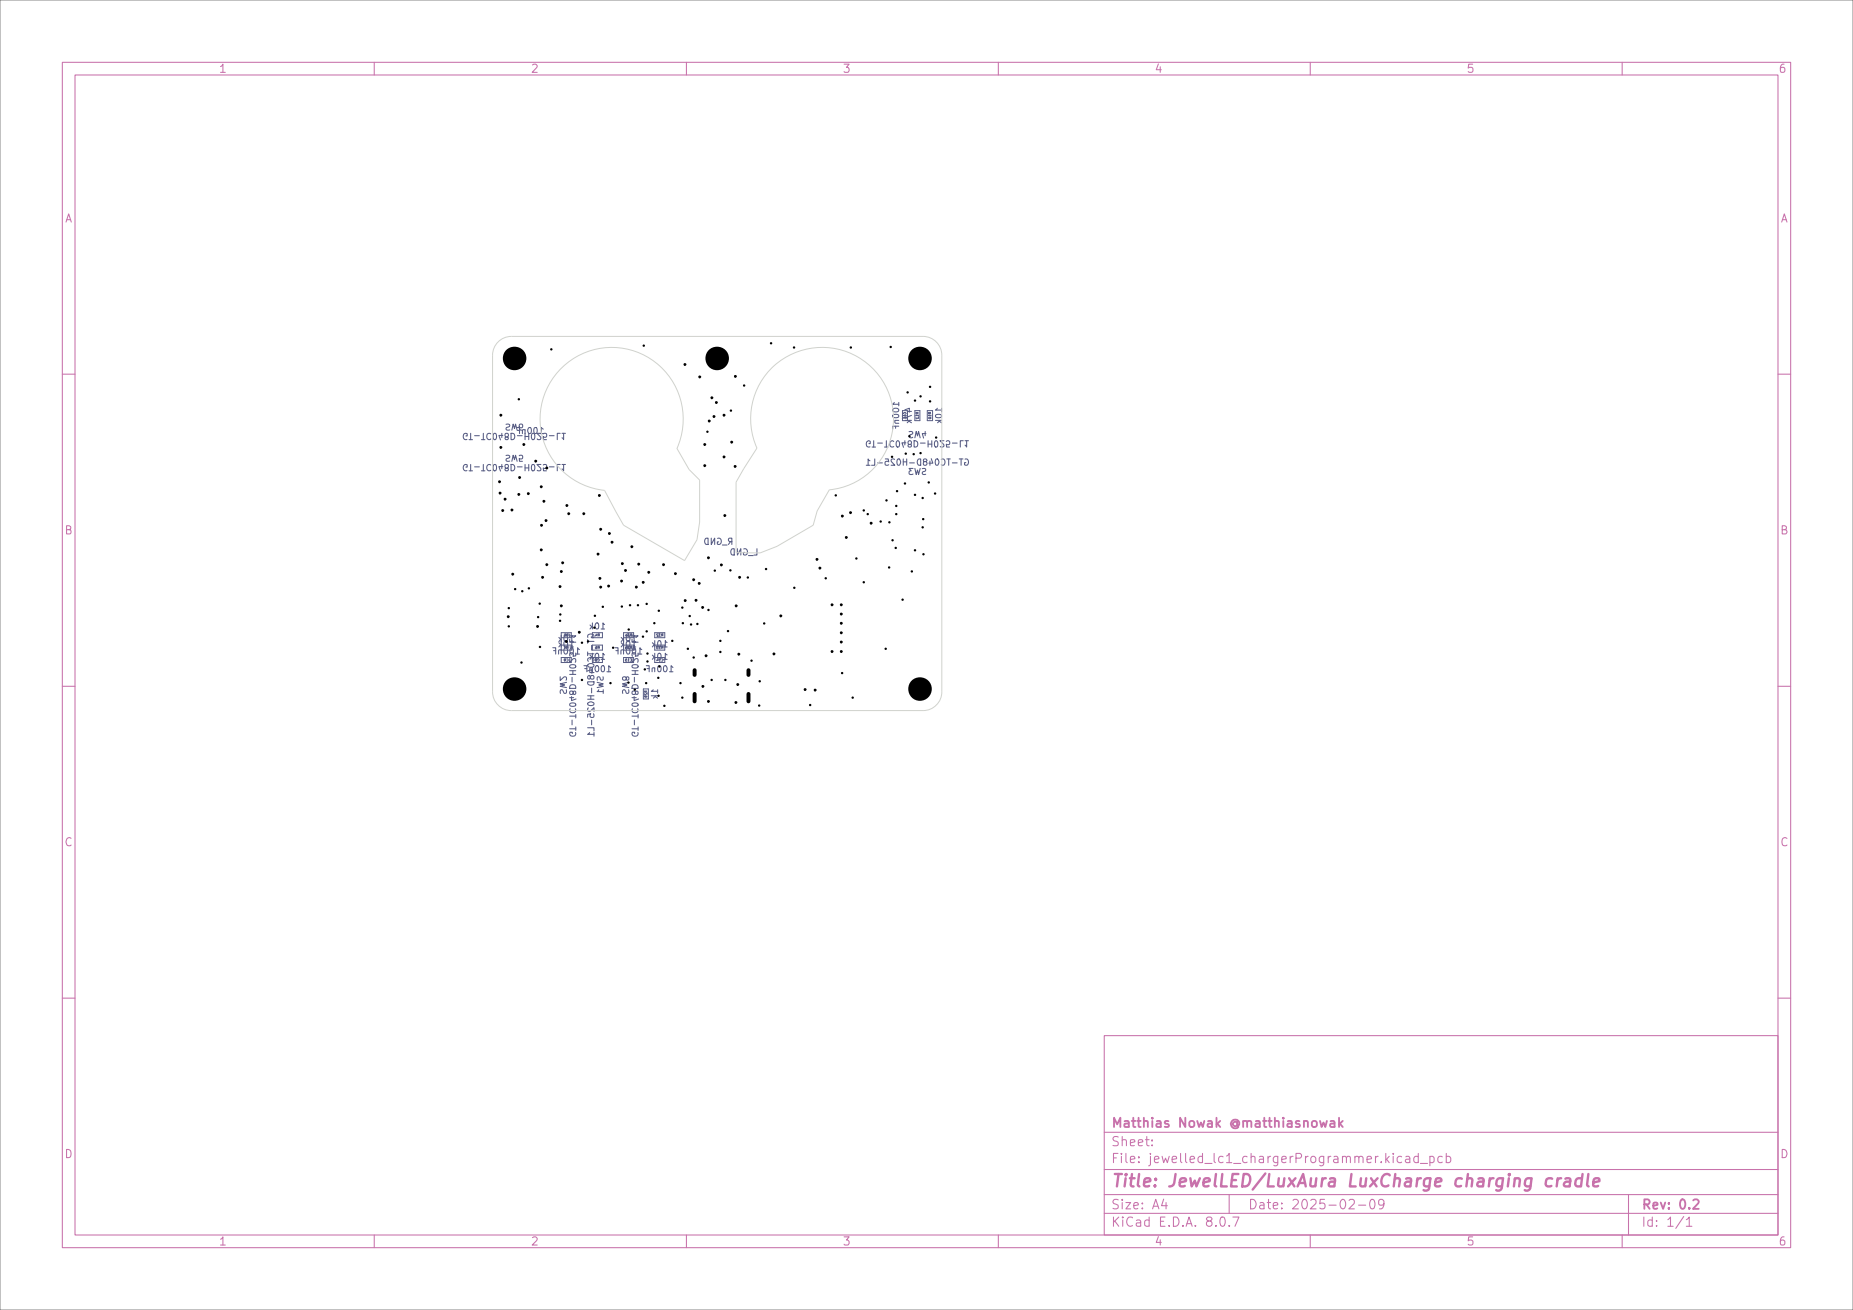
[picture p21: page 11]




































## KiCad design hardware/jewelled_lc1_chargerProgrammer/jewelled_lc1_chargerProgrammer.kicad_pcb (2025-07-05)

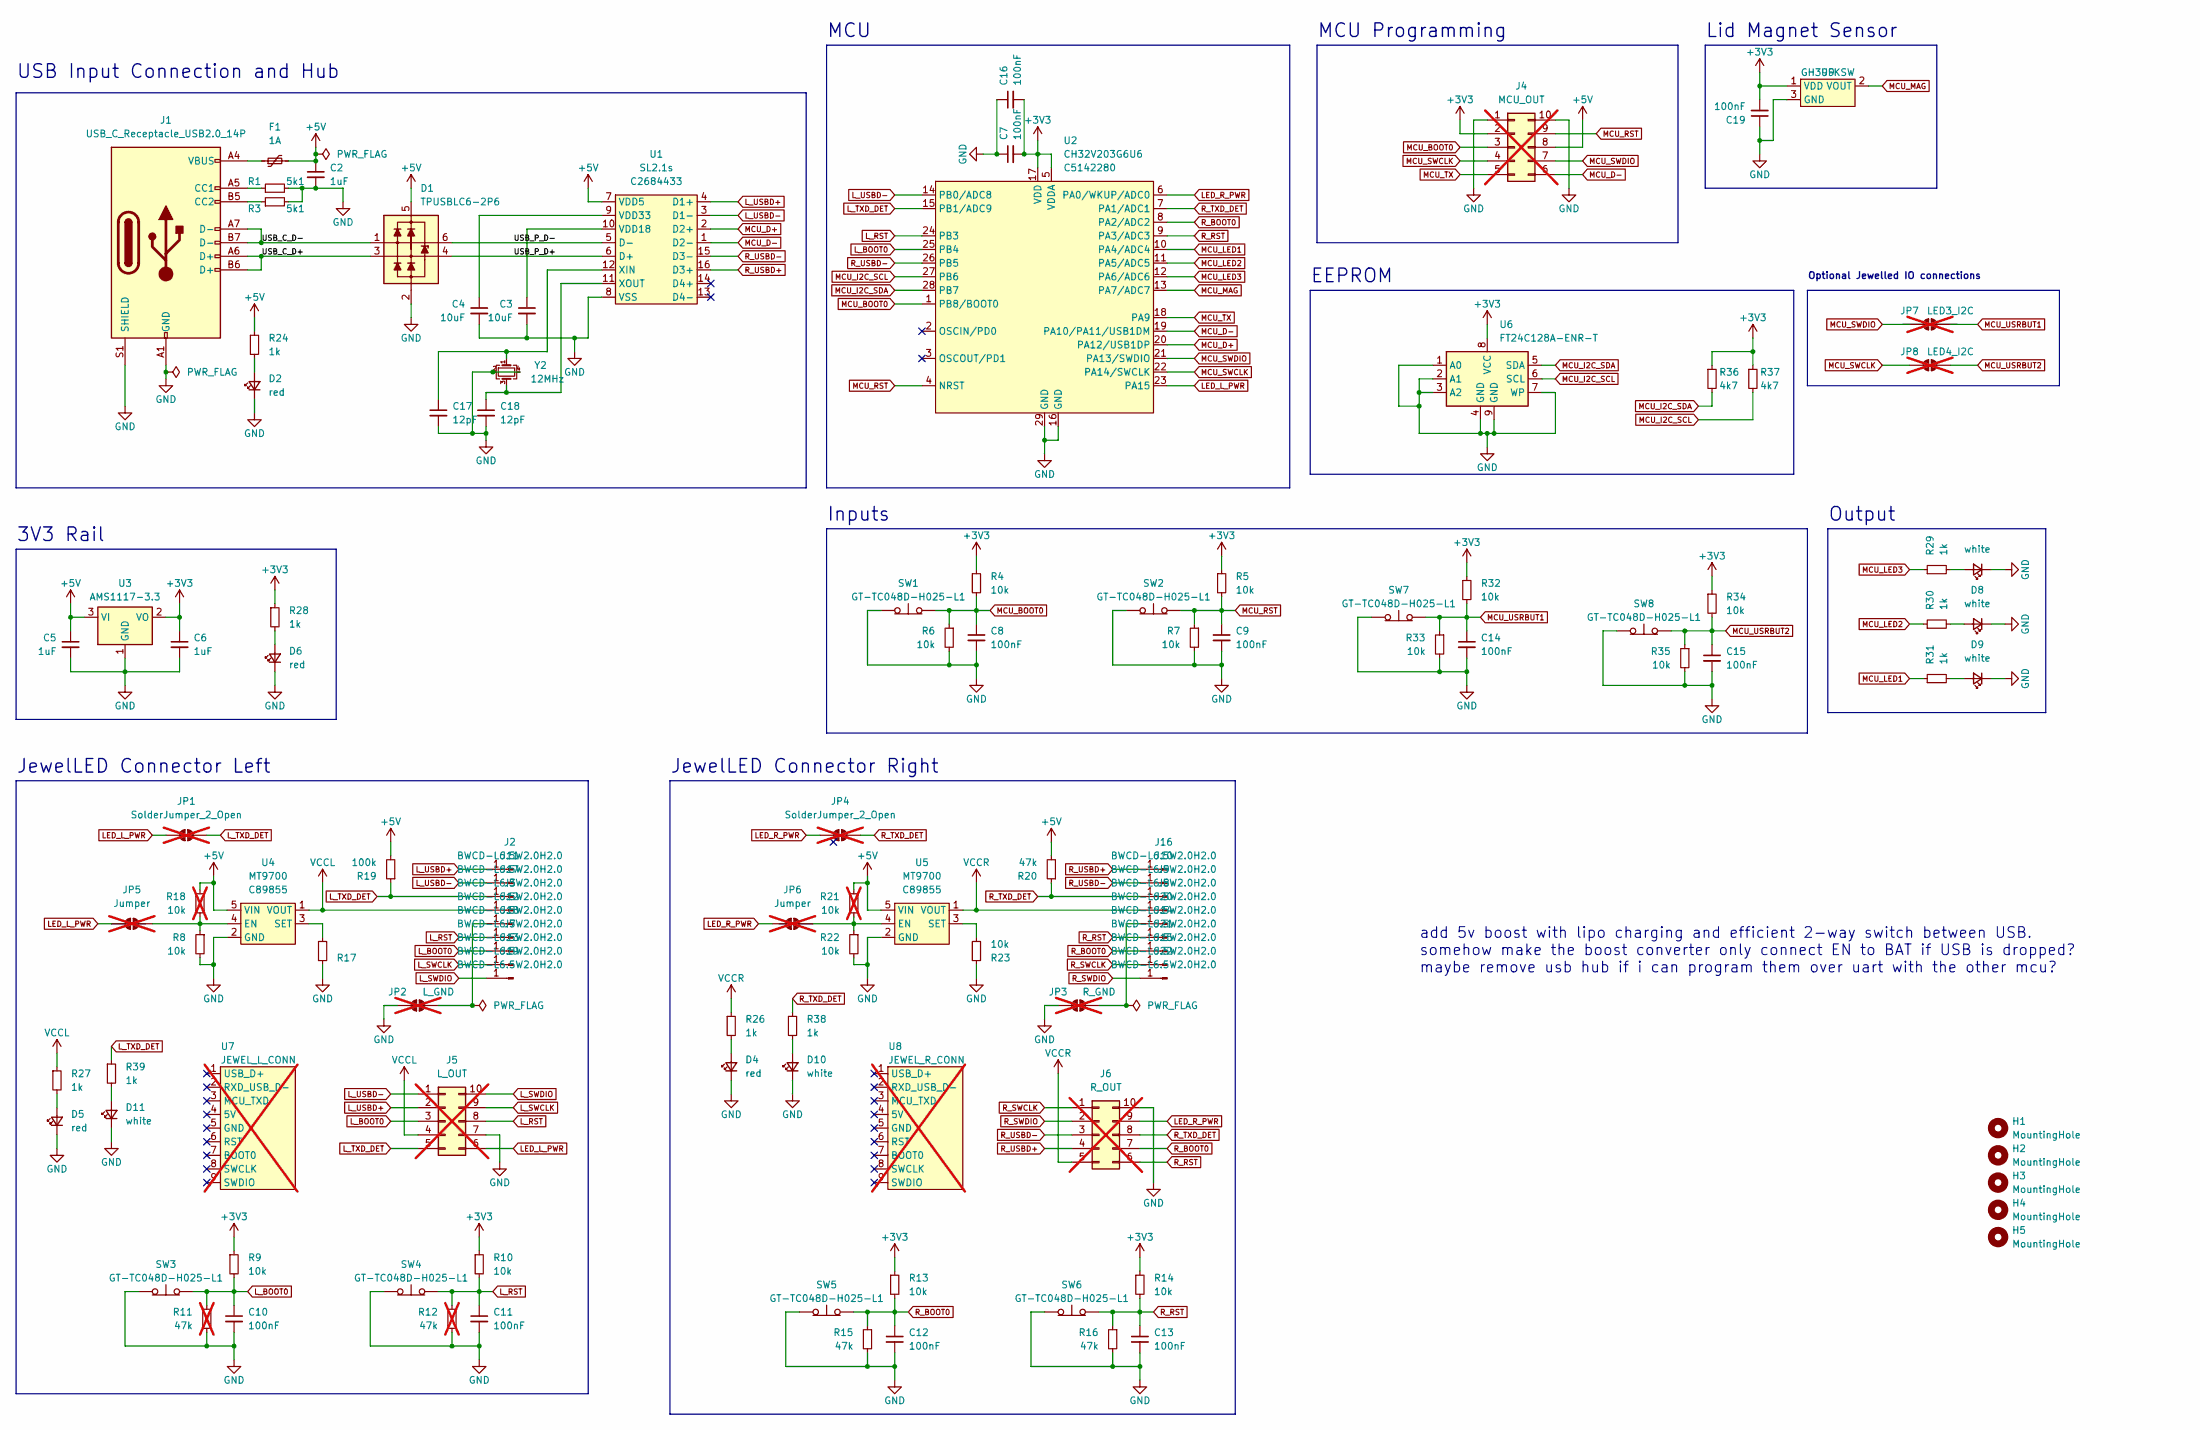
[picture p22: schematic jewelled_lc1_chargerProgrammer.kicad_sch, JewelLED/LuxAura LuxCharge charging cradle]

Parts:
C2, C5, C6: 1uF; C_0603_1608Metric; MPN C15849; LCSC C15849
C3, C4: 10uF; C_0805_2012Metric; MPN C19702; LCSC C19702
C7, C8, C9, C10, C11, C12, C13, C14, C15, C16, C19: 100nF; C_0603_1608Metric; MPN C14663; LCSC C14663
C17, C18: 12pF; C_0603_1608Metric; MPN C38523; LCSC C38523
D1: TPUSBLC6-2P6; SOT-666; MPN C2682291; LCSC C2682291
D2, D4, D5, D6: red; LED_0603_1608Metric; MPN C2286; LCSC C2286
D7, D8, D9, D10, D11: white; LED_0603_1608Metric; MPN C2290; LCSC C2290
F1: 1A; Fuse_1210_3225Metric; MPN C692151; LCSC C692151
H1, H2, H3, H4, H5: MountingHole; Mounting_Sinhoo-M2_H2mm_SMTSO2020MTJ; MPN C2916384; LCSC C2916384
J1: USB_C_Receptacle_USB2.0_14P; USB_C_Receptacle_GT-USB-7010B; MPN C2988369; LCSC C2988369
J2, J3, J7, J8, J9, J10, J11, J12, J13, J14, J15, J16, J17, J18, J19, J20, J21, J22: BWCD-L6.5W2.0H2.0; jewelled_2mm_pogopad; MPN C2826552; LCSC C2826552
J4: MCU_OUT; pogoheader_2x05_1.5mm; MPN x; not fitted
J5: L_OUT; pogoheader_2x05_1.5mm; MPN x; not fitted
J6: R_OUT; pogoheader_2x05_1.5mm; MPN x; not fitted
JP1, JP4: SolderJumper_2_Open; SolderJumper-2_P1.3mm_Open_RoundedPad1.0x1.5mm; MPN x; not fitted
JP2: L_GND; SolderJumper-2_P1.3mm_Open_RoundedPad1.0x1.5mm; MPN x; not fitted
JP3: R_GND; SolderJumper-2_P1.3mm_Open_RoundedPad1.0x1.5mm; MPN x; not fitted
JP5, JP6: Jumper; SolderJumper-2_P1.3mm_Open_RoundedPad1.0x1.5mm; MPN x; not fitted
JP7: LED3_I2C; SolderJumper-2_P1.3mm_Open_RoundedPad1.0x1.5mm; MPN x; not fitted
JP8: LED4_I2C; SolderJumper-2_P1.3mm_Open_RoundedPad1.0x1.5mm; MPN x; not fitted
R1, R3: 5k1; R_0603_1608Metric; MPN C23186; LCSC C23186
R4, R5, R6, R7, R8, R9, R10, R13, R14, R17, R22, R23, R32, R33, R34, R35: 10k; R_0603_1608Metric; MPN C25804; LCSC C25804
R11, R12: 47k; R_0603_1608Metric; MPN C25819; LCSC C25819; not fitted
R15, R16, R20: 47k; R_0603_1608Metric; MPN C25819; LCSC C25819
R18, R21: 10k; R_0603_1608Metric; MPN C25804; LCSC C25804; not fitted
R19: 100k; R_0603_1608Metric; MPN C25803; LCSC C25803
R24, R26, R27, R28, R29, R30, R31, R38, R39: 1k; R_0603_1608Metric; MPN C21190; LCSC C21190
R36, R37: 4k7; R_0603_1608Metric; MPN C23162; LCSC C23162
SW1, SW2, SW3, SW4, SW5, SW6, SW7, SW8: GT-TC048D-H025-L1; MPN C843674; LCSC C843674
U1: SL2.1s; SSOP16_SL2.1S; MPN C2684433; LCSC C2684433
U2: CH32V203G6U6; QFN-28-1EP_4x4mm_P0.4mm_EP2.6x2.6mm; MPN C5142280; LCSC C5142280
U3: AMS1117-3.3; SOT-89-3; MPN C18723569; LCSC C18723569
U4, U5: MT9700; SOT-23-5; MPN C89855; LCSC C89855
U6: FT24C128A-ENR-T; DFN-8-1EP_3x2mm_P0.5mm_EP1.7x1.6mm; MPN C232872; LCSC C232872
U7: JEWEL_L_CONN; jewelled_lc1_v1_conn; MPN C2826552; LCSC C2826552; not fitted
U8: JEWEL_R_CONN; jewelled_lc1_v1_conn; MPN C2826552; LCSC C2826552; not fitted
U9: GH39FKSW; SOT-23-3; MPN C266230; LCSC C266230
Y2: 12MHz; Crystal_SMD_2520-4Pin_2.5x2.0mm; MPN C5122639; LCSC C5122639

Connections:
+3V3: C6.1, C7.2, C16.2, C19.2, J4.2, R4.1, R5.1, R9.1, R10.1, R13.1, R14.1, R28.1, R32.1, R34.1, R36.1, R37.1, U2.5 (VDDA), U2.17 (VDD), U3.2 (VO), U6.8 (VCC), U9.1 (VDD)
+5V: C2.1, C5.1, D1.5 (VP), F1.2, J4.8, R18.1, R19.2, R20.2, R21.1, R24.1, U1.7 (VDD5), U3.3 (VI), U4.5 (VIN), U5.5 (VIN)
/USB_C_D+: D1.3 (L2), J1.A6 (D+), J1.B6 (D+)
/USB_C_D-: D1.1 (L1), J1.A7 (D-), J1.B7 (D-)
/USB_P_D+: D1.4 (L2), U1.6 (D+)
/USB_P_D-: D1.6 (L1), U1.5 (D-)
GND: C2.2, C3.2, C4.2, C5.2, C6.2, C7.1, C8.2, C9.2, C10.2, C11.2, C12.2, C13.2, C14.2, C15.2, C16.1, C17.2, C18.2, C19.1, D1.2 (VN), D2.1 (K), D4.1 (K), D5.1 (K), D6.1 (K), D7.1 (K), D8.1 (K), D9.1 (K), D10.1 (K), D11.1 (K), J1.A1 (GND), J1.A12 (GND), J1.B1 (GND), J1.B12 (GND), J1.S1 (SHIELD), J4.1, J4.10, J5.7, J6.10, JP2.2 (B), JP3.2 (B), R1.2, R3.2, R6.2, R7.2, R8.2, R11.2, R12.2, R15.2, R16.2, R17.1, R22.2, R23.1, R33.2, R35.2, SW1.1 (A), SW2.1 (A), SW3.1 (A), SW4.1 (A), SW5.1 (A), SW6.1 (A), SW7.1 (A), SW8.1 (A), U1.8 (VSS), U2.16 (GND), U2.29 (GND), U3.1 (GND), U4.2 (GND), U5.2 (GND), U6.1 (A0), U6.2 (A1), U6.3 (A2), U6.4 (GND), U6.7 (WP), U6.9 (GND), U9.3 (GND), Y2.2, Y2.4
LED_L_PWR: J5.6, JP1.1 (A), JP5.1 (A), U2.23 (PA15)
LED_R_PWR: J6.9, JP4.1 (A), JP6.1 (A), U2.6 (PA0/WKUP/ADC0)
L_BOOT0: C10.1, J5.3, J7.1, R9.2, R11.1, SW3.2 (B), U2.25 (PB4)
L_RST: C11.1, J5.8, J18.1, R10.2, R12.1, SW4.2 (B), U2.24 (PB3)
L_SWCLK: J5.9, J13.1
L_SWDIO: J5.10, J19.1
L_TXD_DET: J5.5, J17.1, JP1.2 (B), R19.1, R39.1, U2.15 (PB1/ADC9)
L_USBD+: J2.1, J5.2, U1.4 (D1+)
L_USBD-: J5.1, J11.1, U1.3 (D1-), U2.14 (PB0/ADC8)
MCU_BOOT0: C8.1, J4.3, R4.2, R6.1, SW1.2 (B), U2.1 (PB8/BOOT0)
MCU_D+: U1.2 (D2+), U2.20 (PA12/USB1DP)
MCU_D-: J4.6, U1.1 (D2-), U2.19 (PA10/PA11/USB1DM)
MCU_I2C_SCL: R37.2, U2.27 (PB6), U6.6 (SCL)
MCU_I2C_SDA: R36.2, U2.28 (PB7), U6.5 (SDA)
MCU_LED1: R31.1, U2.10 (PA4/ADC4)
MCU_LED2: R30.1, U2.11 (PA5/ADC5)
MCU_LED3: R29.1, U2.12 (PA6/ADC6)
MCU_MAG: U2.13 (PA7/ADC7), U9.2 (VOUT)
MCU_RST: C9.1, J4.9, R5.2, R7.1, SW2.2 (B), U2.4 (NRST)
MCU_SWCLK: J4.4, JP8.2 (B), U2.22 (PA14/SWCLK)
MCU_SWDIO: J4.7, JP7.2 (B), U2.21 (PA13/SWDIO)
MCU_TX: J4.5, U2.18 (PA9)
MCU_USRBUT1: C14.1, JP7.1 (A), R32.2, R33.1, SW7.2 (B)
MCU_USRBUT2: C15.1, JP8.1 (A), R34.2, R35.1, SW8.2 (B)
unnamed: D2.2 (A), R24.2
unnamed: D4.2 (A), R26.2
unnamed: D5.2 (A), R27.2
unnamed: D6.2 (A), R28.2
unnamed: D7.2 (A), R29.2
unnamed: D8.2 (A), R30.2
unnamed: D9.2 (A), R31.2
unnamed: D10.2 (A), R38.2
unnamed: D11.2 (A), R39.2
unnamed: F1.1, J1.A4 (VBUS), J1.A9 (VBUS), J1.B4 (VBUS), J1.B9 (VBUS)
unnamed: J1.A5 (CC1), R1.1
unnamed: J1.B5 (CC2), R3.1
unnamed: J12.1, JP2.1 (A)
unnamed: J20.1, JP3.1 (A)
unnamed: JP5.2 (B), R8.1, R18.2, U4.4 (EN)
unnamed: JP6.2 (B), R21.2, R22.1, U5.4 (EN)
unnamed: C3.1, U1.10 (VDD18)
unnamed: C4.1, U1.9 (VDD33)
unnamed: C17.1, U1.12 (XIN), Y2.1
unnamed: C18.1, U1.11 (XOUT), Y2.3
unnamed: R17.2, U4.3 (SET)
unnamed: R23.2, U5.3 (SET)
R_BOOT0: C12.1, J6.7, J21.1, R13.2, R15.1, SW5.2 (B), U2.8 (PA2/ADC2)
R_RST: C13.1, J6.6, J14.1, R14.2, R16.1, SW6.2 (B), U2.9 (PA3/ADC3)
R_SWCLK: J6.1, J15.1
R_SWDIO: J6.2, J22.1
R_TXD_DET: J6.8, J9.1, JP4.2 (B), R20.1, R38.1, U2.7 (PA1/ADC1)
R_USBD+: J6.4, J16.1, U1.16 (D3+)
R_USBD-: J6.3, J10.1, U1.15 (D3-), U2.26 (PB5)
VCCL: J3.1, J5.4, R27.1, U4.1 (VOUT)
VCCR: J6.5, J8.1, R26.1, U5.1 (VOUT)

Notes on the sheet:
3V3 Rail
JewelLED Connector Left
JewelLED Connector Right
EEPROM
Optional Jewelled IO connections
Inputs
USB Input Connection and Hub
MCU
MCU Programming
add 5v boost with lipo charging and efficient 2-way switch between USB. somehow make the boost converter only connect EN to BAT if USB is dropped? maybe remove usb hub if i can program them over uart with the other mcu?
Lid Magnet Sensor
Output

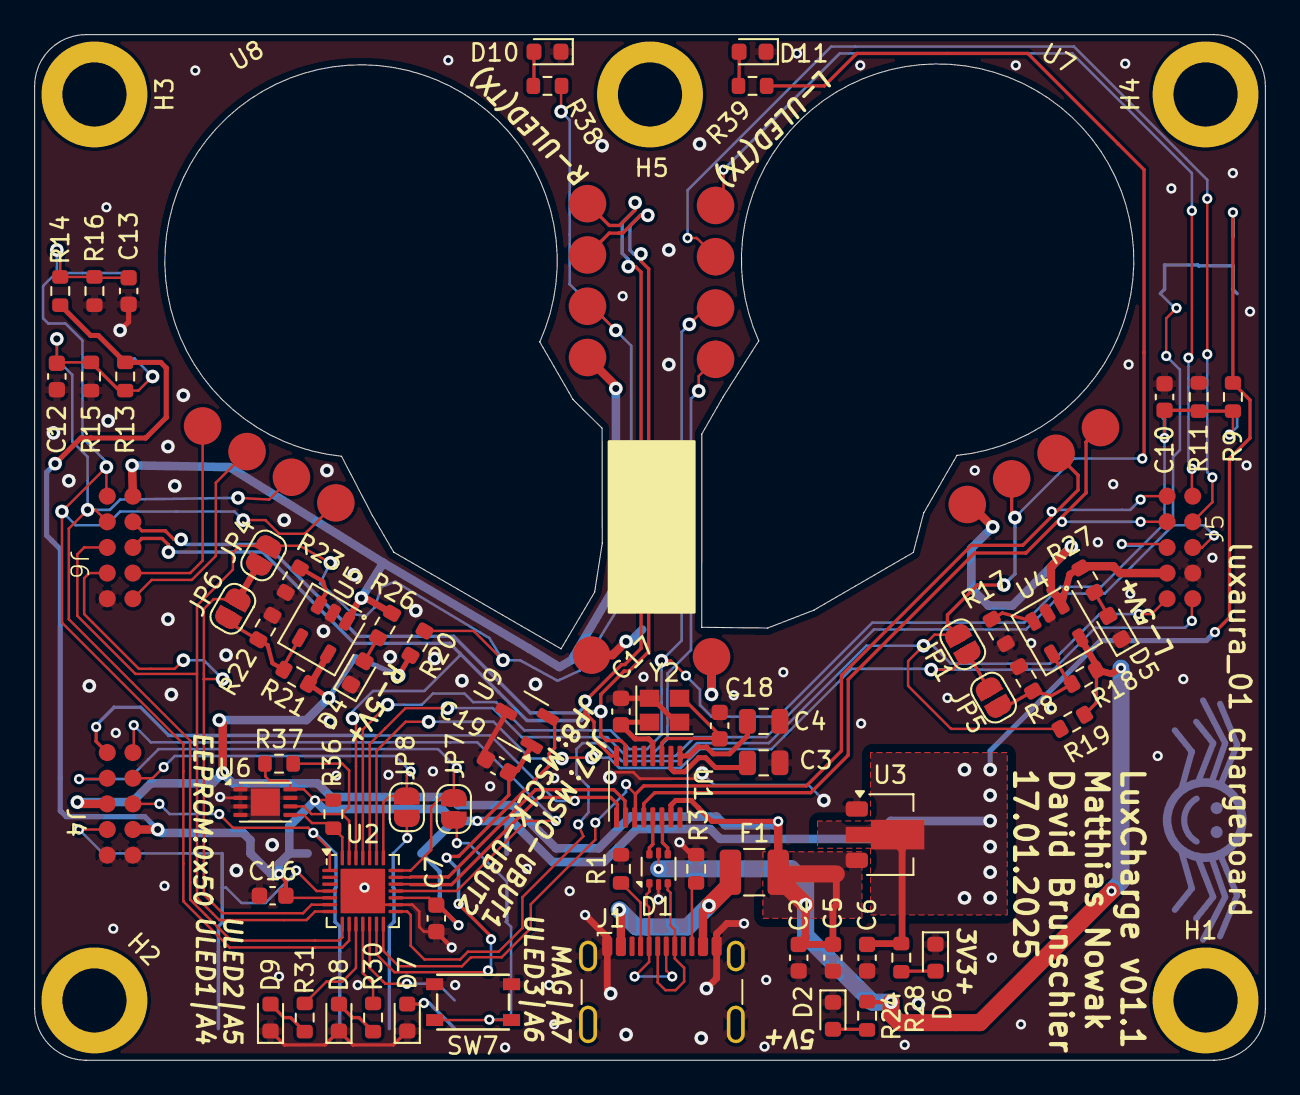
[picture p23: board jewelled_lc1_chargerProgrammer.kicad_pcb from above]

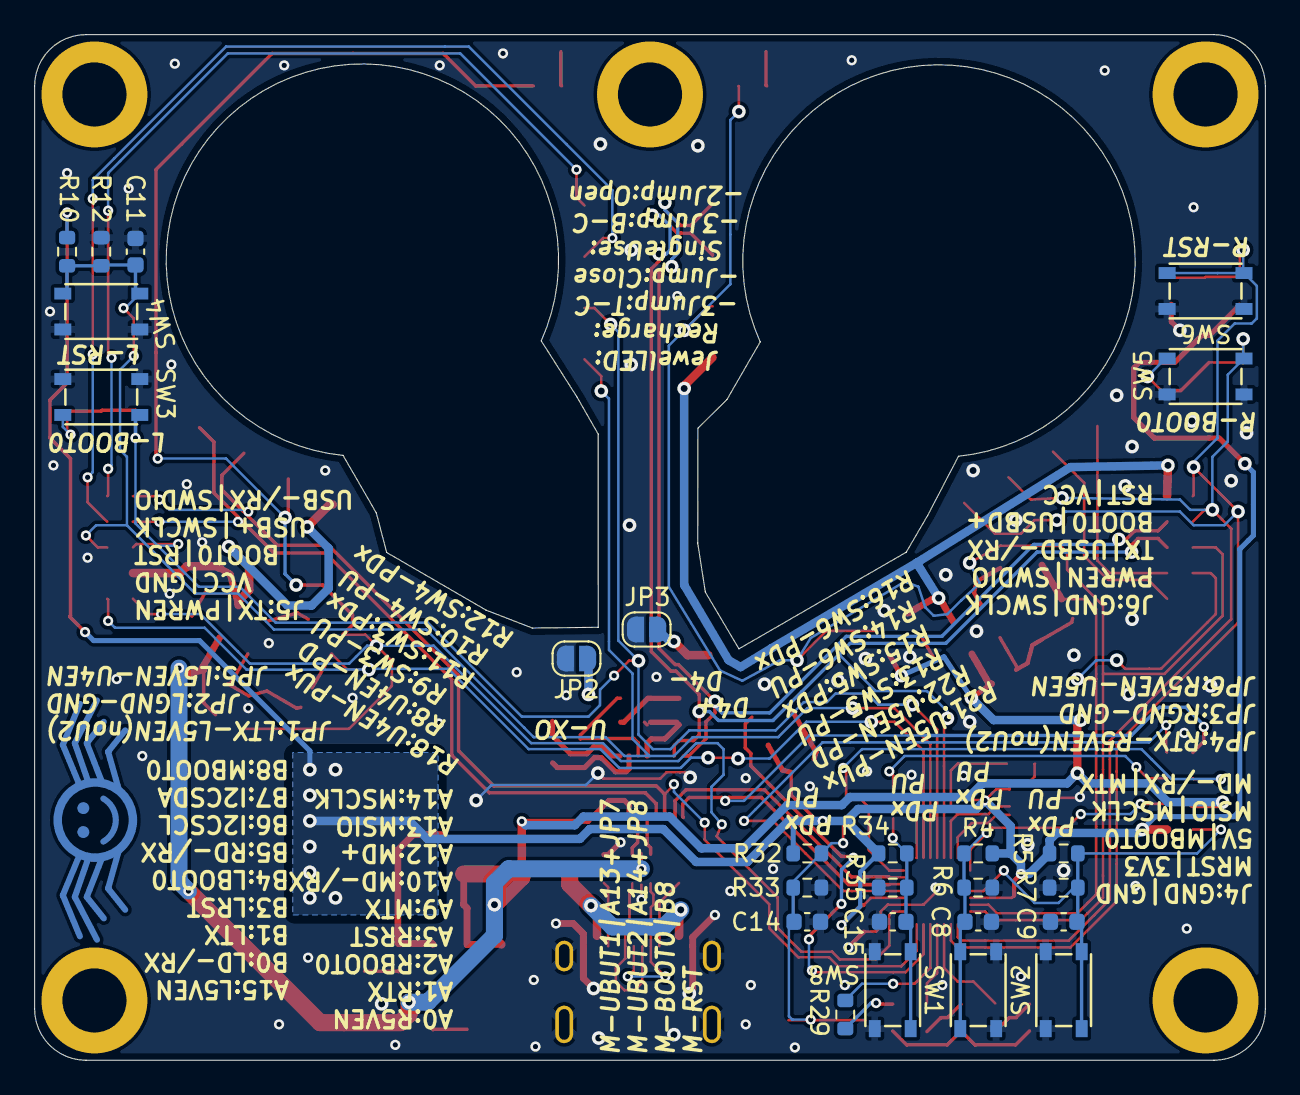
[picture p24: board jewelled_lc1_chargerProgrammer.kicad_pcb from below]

Board: 2 copper layers, 72.0 x 60.0 mm, 119 parts (25 on the bottom side), 62 nets.

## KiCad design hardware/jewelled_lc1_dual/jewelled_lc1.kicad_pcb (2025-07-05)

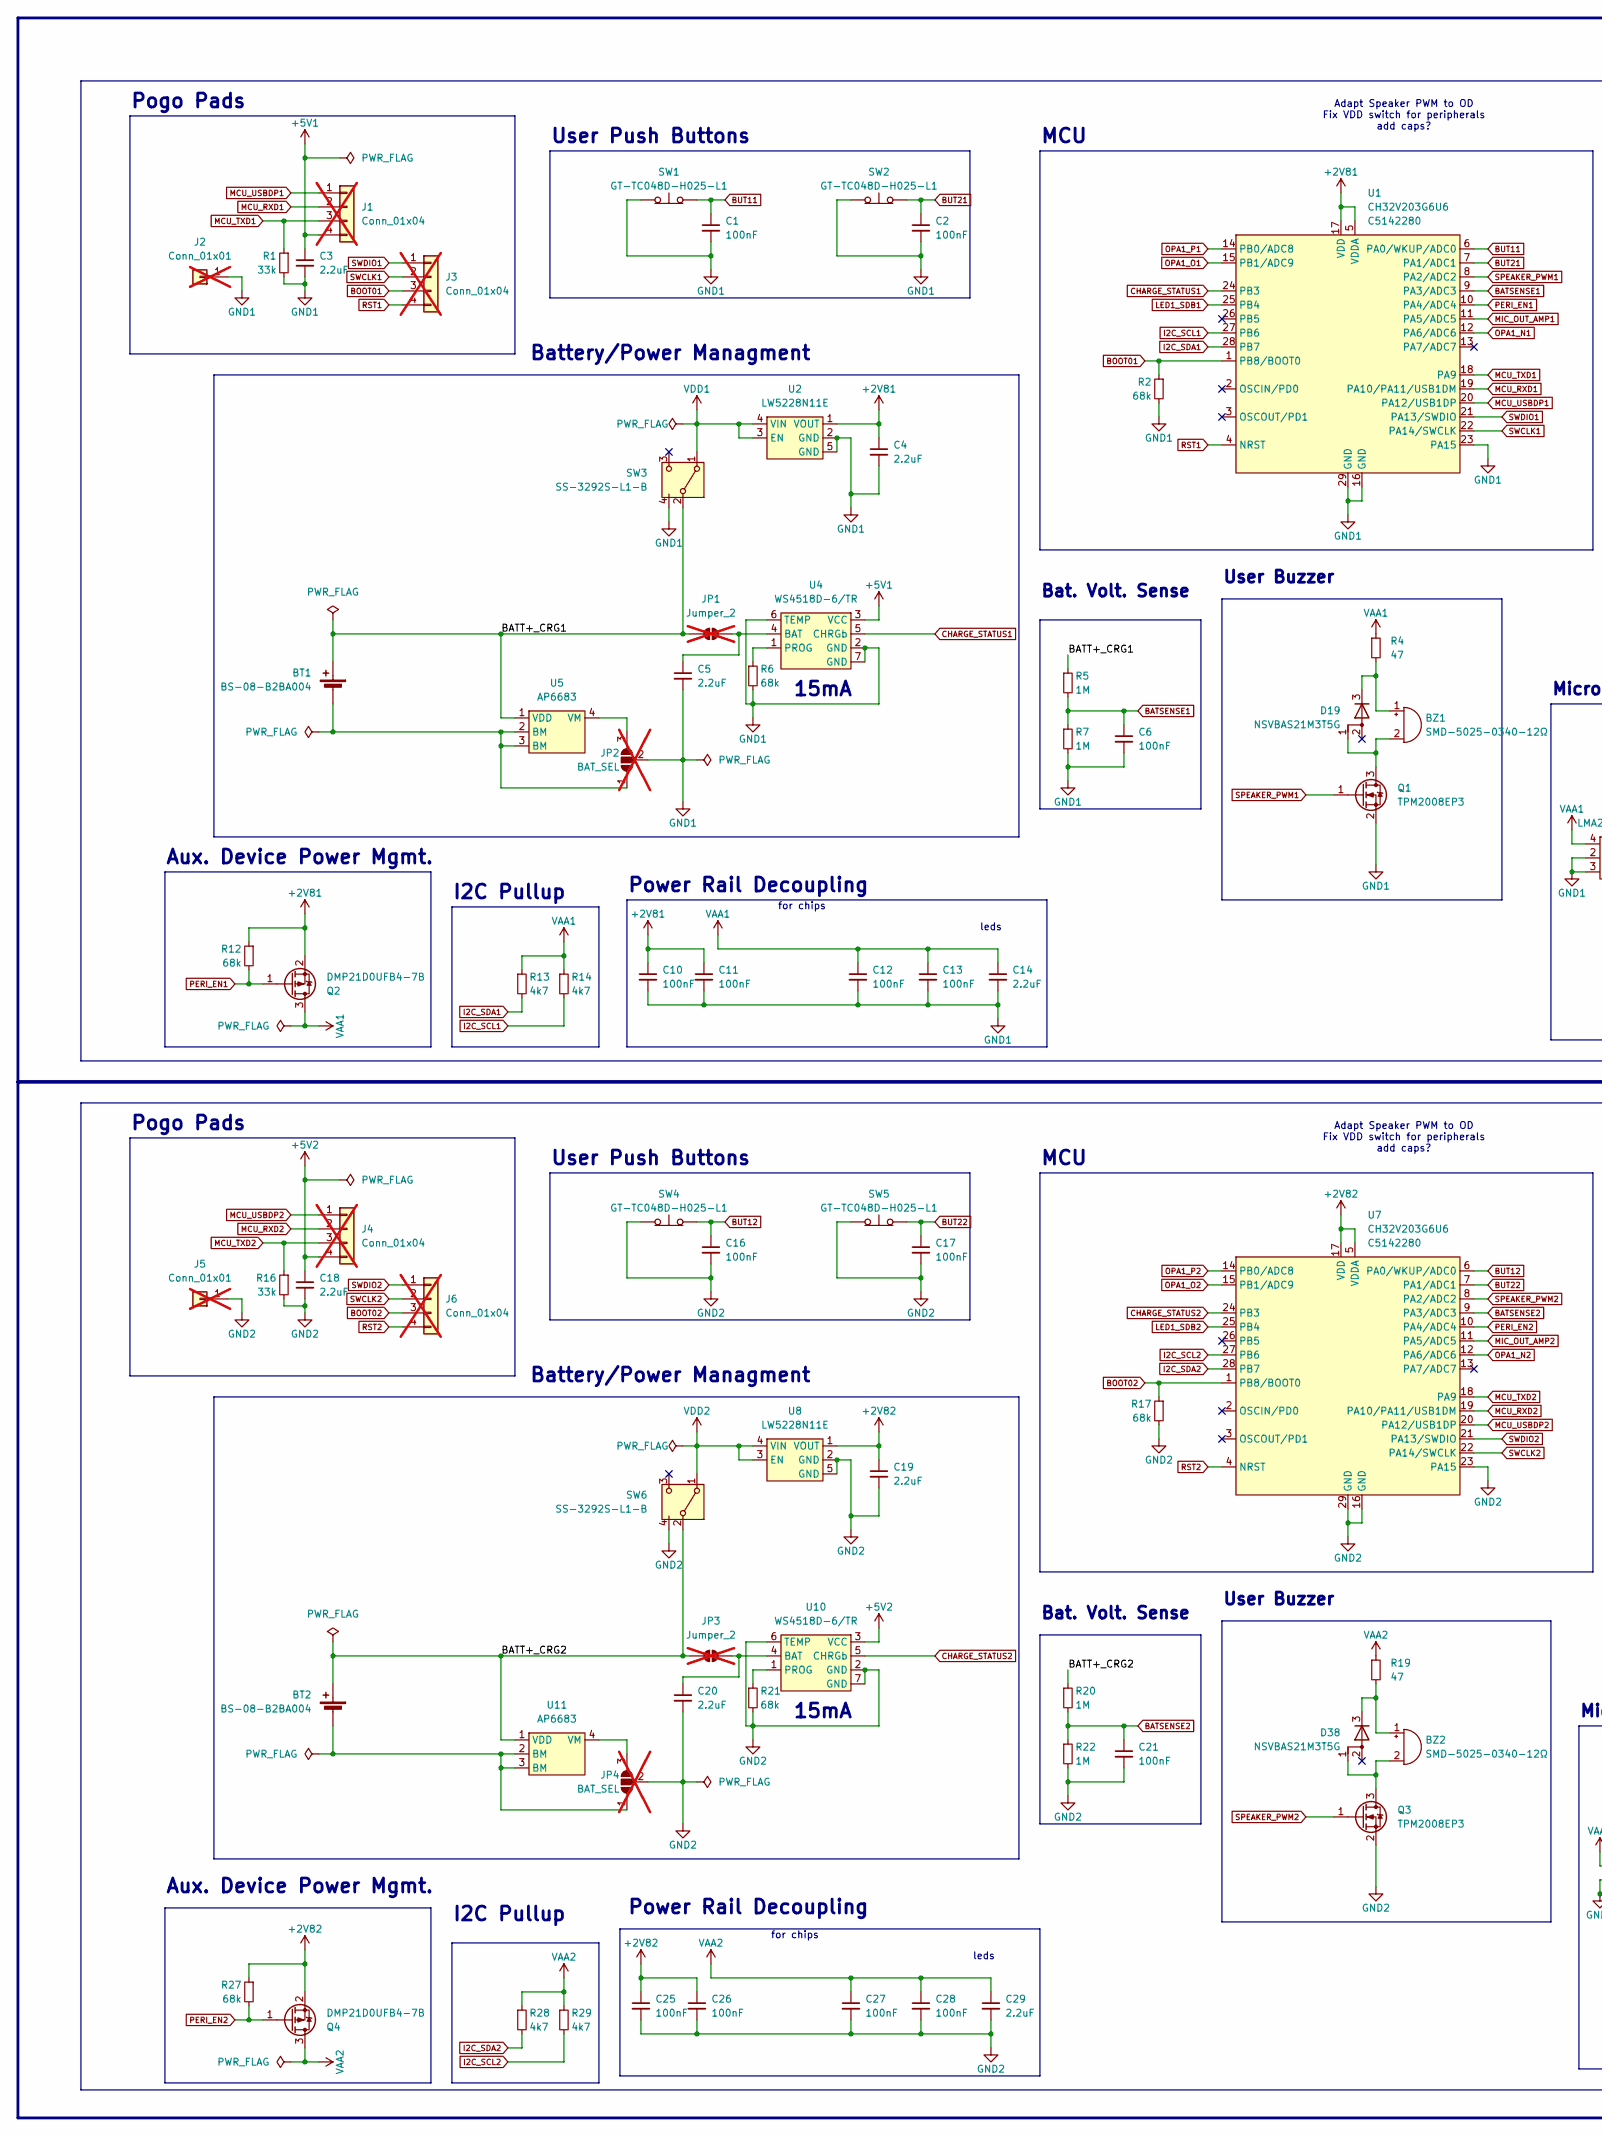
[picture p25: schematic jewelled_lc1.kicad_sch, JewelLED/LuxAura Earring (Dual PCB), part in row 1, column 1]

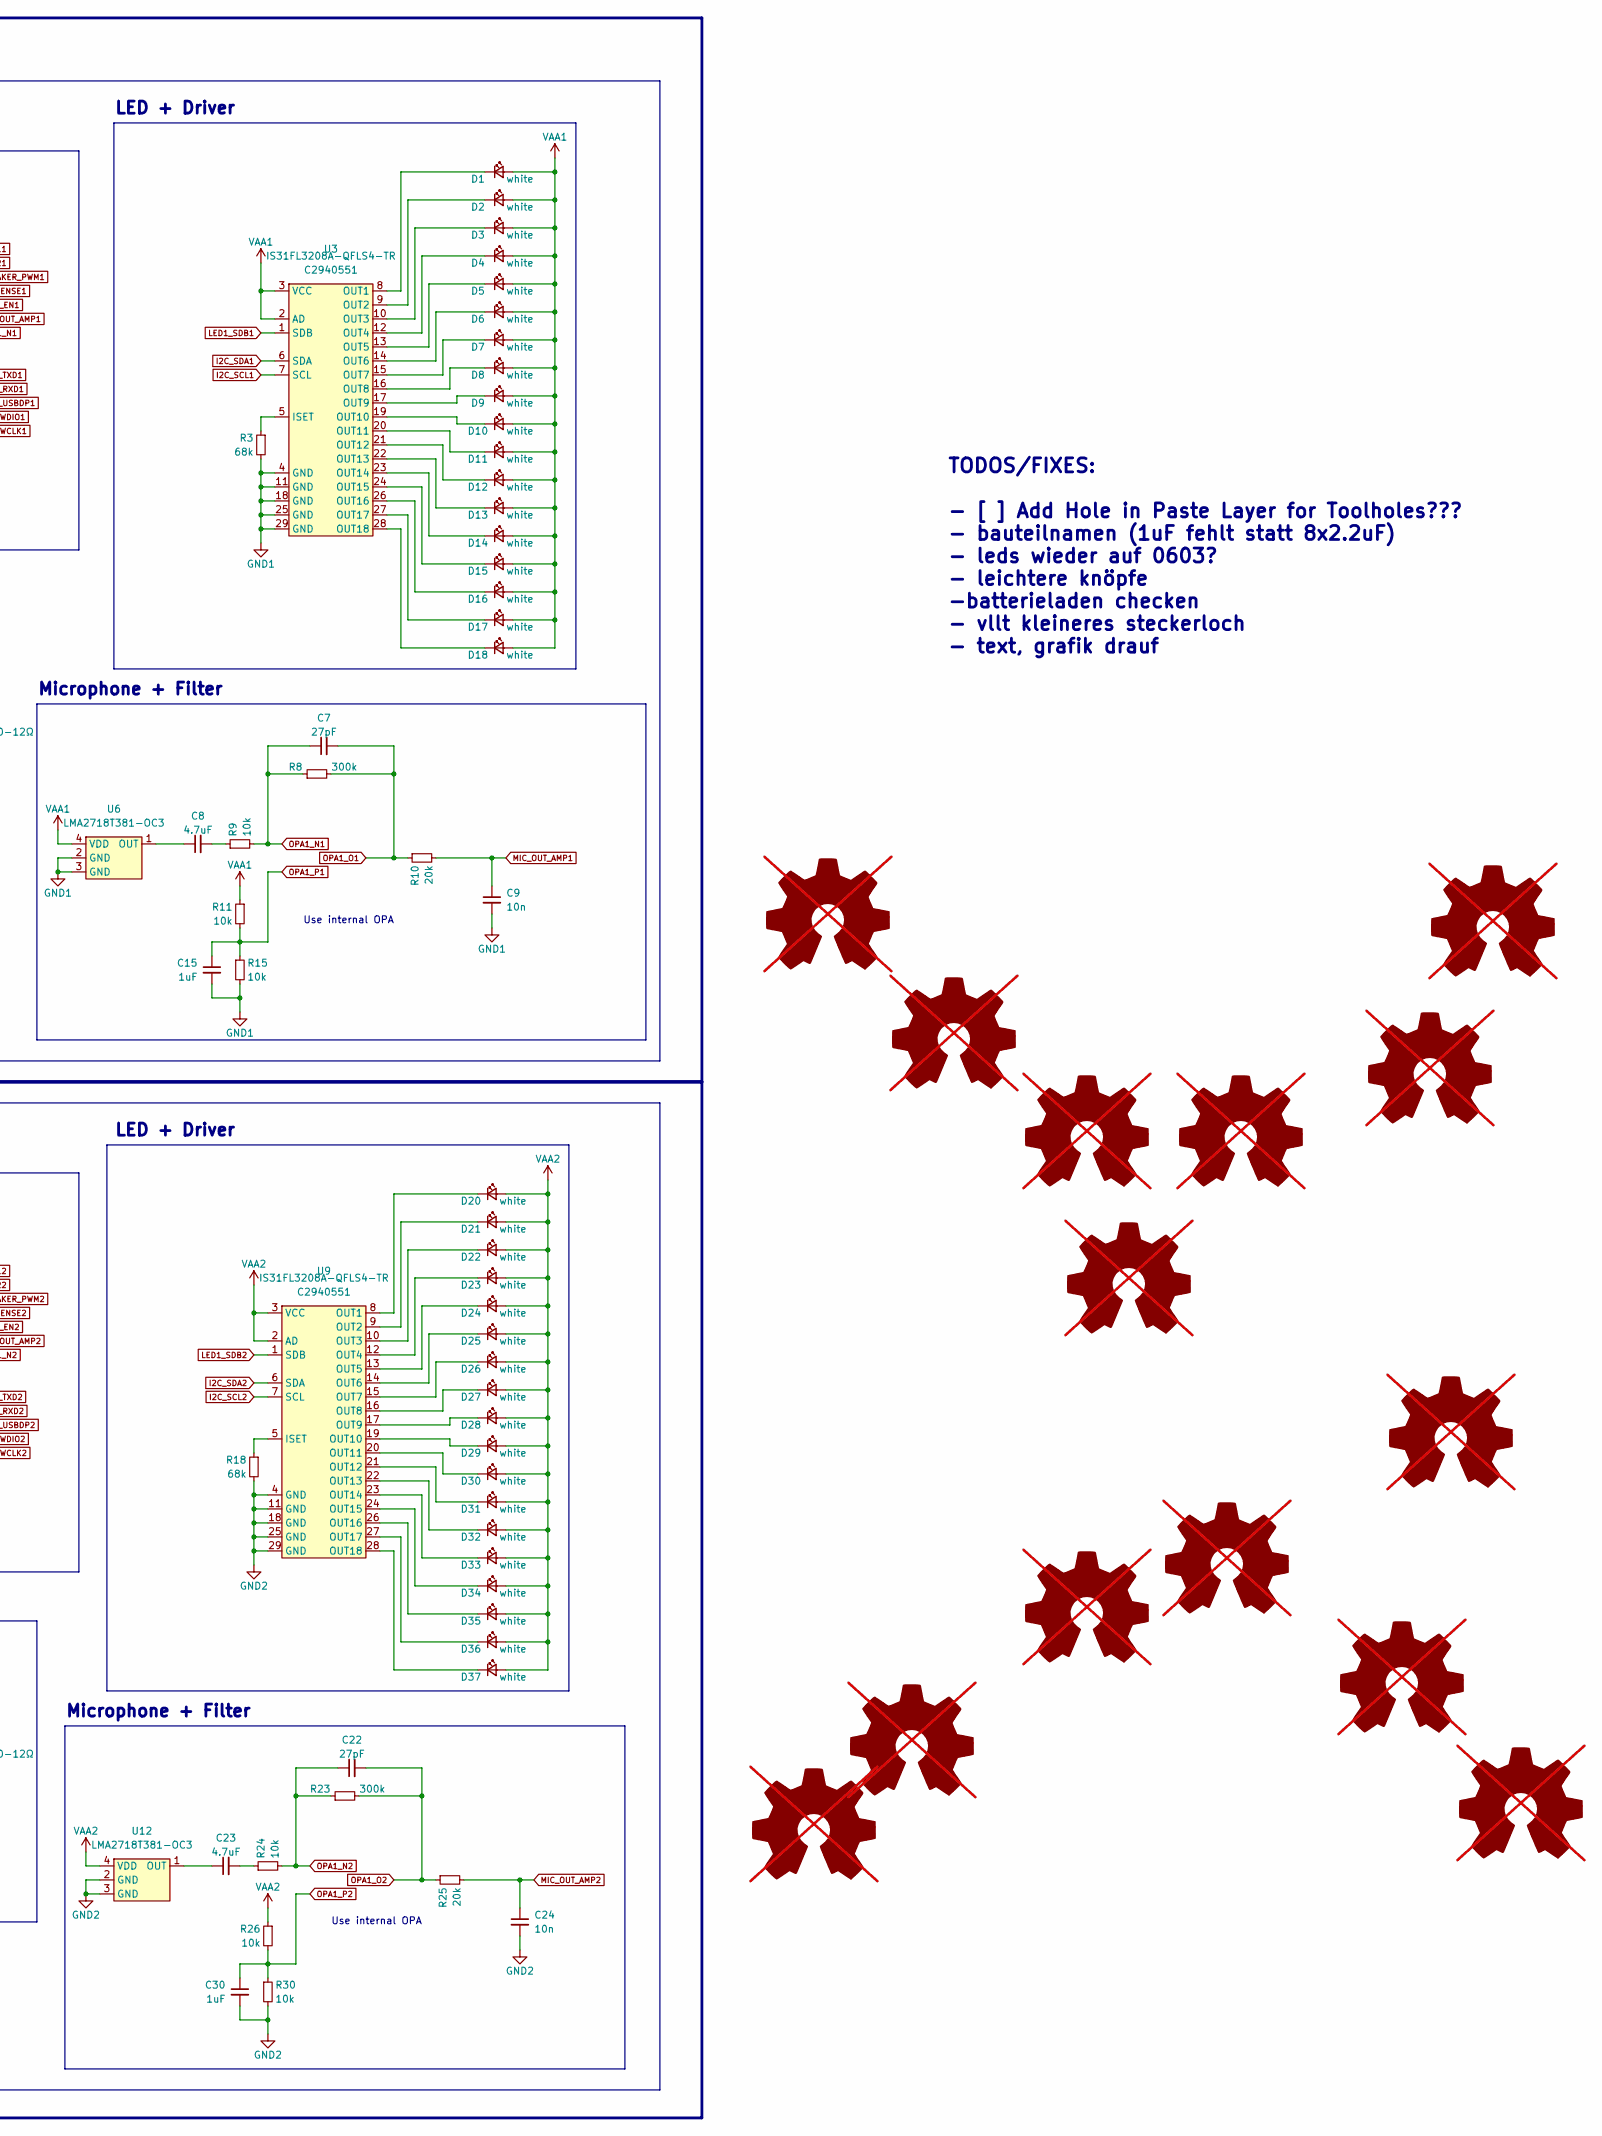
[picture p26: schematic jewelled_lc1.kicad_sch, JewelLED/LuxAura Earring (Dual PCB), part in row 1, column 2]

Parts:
BT1, BT2: BS-08-B2BA004; MPN C964780; LCSC C964780
BZ1, BZ2: SMD-5025-0340-12Ω; SMD-5025-0340; MPN C2693575; LCSC C2693575
C1, C2, C6, C10, C11, C12, C13, C16, C17, C21, C25, C26, C27, C28: 100nF; C_0402_1005Metric; MPN C1525; LCSC C1525
C3, C4, C5, C14, C18, C19, C20, C29: 2.2uF; C_0402_1005Metric; MPN C12530; LCSC C12530
C7, C22: 27pF; C_0402_1005Metric; MPN C1557; LCSC C1557
C8, C23: 4.7uF; C_0402_1005Metric; MPN C23733; LCSC C23733
C9, C24: 10n; C_0402_1005Metric; MPN C15195; LCSC C15195
C15, C30: 1uF; C_0402_1005Metric; MPN C52923; LCSC C52923
D1, D2, D3, D4, D5, D6, D7, D8, D9, D10, D11, D12, D13, D14, D15, D16, D17, D18, D20, D21, D22, D23, D24, D25, D26, D27, D28, D29, D30, D31, D32, D33, D34, D35, D36, D37: white; LED_0402_1005Metric; MPN C157742; LCSC C157742
D19, D38: NSVBAS21M3T5G; SOT-723; MPN C896450; LCSC C896450
J1, J3, J4, J6: Conn_01x04; pogo_conn_01x03_P2.0mm_angled; not fitted
J2, J5: Conn_01x01; pogo_conn_01x01_P2.0mm; not fitted
JP1, JP3: Jumper_2; SolderJumper-2_P1.3mm_Open_RoundedPad1.0x1.5mm_NoSilk; not fitted
JP2, JP4: BAT_SEL; SolderJumper-3_P1.3mm_Open_RoundedPad1.0x1.5mm_NoSilk; not fitted
Q1, Q3: TPM2008EP3; DFN-3_1.0x0.6mm_P0.35mm; MPN C2682293; LCSC C2682293
Q2, Q4: DMP21D0UFB4-7B; DFN-3_1.0x0.6mm_P0.35mm; MPN C155329; LCSC C155329
R1, R16: 33k; R_0402_1005Metric; MPN C25779; LCSC C25779
R2, R3, R6, R12, R17, R18, R21, R27: 68k; R_0402_1005Metric; MPN C36871; LCSC C36871
R4, R19: 47; R_0402_1005Metric; MPN C25118; LCSC C25118
R5, R7, R20, R22: 1M; R_0402_1005Metric; MPN C26083; LCSC C26083
R8, R23: 300k; R_0402_1005Metric; MPN C25774; LCSC C25774
R9, R11, R15, R24, R26, R30: 10k; R_0402_1005Metric; MPN C25744; LCSC C25744
R10, R25: 20k; R_0402_1005Metric; MPN C25765; LCSC C25765
R13, R14, R28, R29: 4k7; R_0402_1005Metric; MPN C25900; LCSC C25900
SW1, SW2, SW4, SW5: GT-TC048D-H025-L1; MPN C843674; LCSC C843674
SW3, SW6: SS-3292S-L1-B; MPN C397350; LCSC C397350
SYM1, SYM2, SYM13, SYM14: jlcpcb_toolhole; not fitted
SYM3, SYM4, SYM11, SYM12: jlcpcb_fiducial; Fiducial_1mm_Mask2mm; not fitted
SYM5, SYM6, SYM9, SYM10: mousebite_outer; not fitted
SYM7, SYM8: mousebite_inner; not fitted
U1, U7: CH32V203G6U6; QFN-28-1EP_4x4mm_P0.4mm_EP2.6x2.6mm; MPN C5142280; LCSC C5142280
U2, U8: LW5228N11E; UDFN-4-1EP_1x1mm_P0.65mm_EP0.48x0.48mm; MPN C20630428; LCSC C20630428
U3, U9: IS31FL3208A-QFLS4-TR; QFN-28-1EP_4x4mm_P0.4mm_EP2.4x2.4mm; MPN C2940551; LCSC C2940551
U4, U10: WS4518D-6/TR; DFN-6-1EP_2x2mm_P0.65mm_EP1x1.6mm; MPN C910991; LCSC C910991
U5, U11: AP6683; UDFN-4-1EP_1x1mm_P0.65mm_EP0.48x0.48mm; MPN C2849565; LCSC C2849565
U6: LMA2718T381-OC3; ZTS6117H; MPN C2999748; LCSC C2999748
U12: LMA2718T381-OC3; ZTS6117H; MPN C19267420; LCSC C2999748

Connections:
+2V81: C4.1, C10.1, C11.1, Q2.2 (S), R12.1, U1.5 (VDDA), U1.17 (VDD), U2.1 (VOUT)
+2V82: C19.1, C25.1, C26.1, Q4.2 (S), R27.1, U7.5 (VDDA), U7.17 (VDD), U8.1 (VOUT)
+5V1: C3.1, J1.4, U4.3 (VCC)
+5V2: C18.1, J4.4, U10.3 (VCC)
/BATT+_CRG1: BT1.1 (+), JP1.1 (A), R5.1, SW3.2 (B), U5.1 (VDD)
/BATT+_CRG2: BT2.1 (+), JP3.1 (A), R20.1, SW6.2 (B), U11.1 (VDD)
BATSENSE1: C6.1, R5.2, R7.1, U1.9 (PA3/ADC3)
BATSENSE2: C21.1, R20.2, R22.1, U7.9 (PA3/ADC3)
BOOT01: J3.3, R2.1, U1.1 (PB8/BOOT0)
BOOT02: J6.3, R17.1, U7.1 (PB8/BOOT0)
BUT11: C1.1, SW1.2 (B), U1.6 (PA0/WKUP/ADC0)
BUT12: C16.1, SW4.2 (B), U7.6 (PA0/WKUP/ADC0)
BUT21: C2.1, SW2.2 (B), U1.7 (PA1/ADC1)
BUT22: C17.1, SW5.2 (B), U7.7 (PA1/ADC1)
CHARGE_STATUS1: U1.24 (PB3), U4.5 (CHRGb)
CHARGE_STATUS2: U7.24 (PB3), U10.5 (CHRGb)
GND1: C1.2, C2.2, C3.2, C4.2, C5.2, C6.2, C9.2, C10.2, C11.2, C12.2, C13.2, C14.2, C15.2, J2.1, JP2.2 (C), Q1.2 (S), R1.2, R2.2, R3.2, R6.2, R7.2, R15.2, SW1.1 (A), SW2.1 (A), SW3.4 (B), U1.16 (GND), U1.23 (PA15), U1.29 (GND), U2.2 (GND), U2.5 (GND), U3.4 (GND), U3.11 (GND), U3.18 (GND), U3.25 (GND), U3.29 (GND), U4.2 (GND), U4.6 (TEMP), U4.7 (GND), U6.2 (GND), U6.3 (GND)
GND2: C16.2, C17.2, C18.2, C19.2, C20.2, C21.2, C24.2, C25.2, C26.2, C27.2, C28.2, C29.2, C30.2, J5.1, JP4.2 (C), Q3.2 (S), R16.2, R17.2, R18.2, R21.2, R22.2, R30.2, SW4.1 (A), SW5.1 (A), SW6.4 (B), U7.16 (GND), U7.23 (PA15), U7.29 (GND), U8.2 (GND), U8.5 (GND), U9.4 (GND), U9.11 (GND), U9.18 (GND), U9.25 (GND), U9.29 (GND), U10.2 (GND), U10.6 (TEMP), U10.7 (GND), U12.2 (GND), U12.3 (GND)
I2C_SCL1: R14.2, U1.27 (PB6), U3.7 (SCL)
I2C_SCL2: R29.2, U7.27 (PB6), U9.7 (SCL)
I2C_SDA1: R13.2, U1.28 (PB7), U3.6 (SDA)
I2C_SDA2: R28.2, U7.28 (PB7), U9.6 (SDA)
LED1_SDB1: U1.25 (PB4), U3.1 (SDB)
LED1_SDB2: U7.25 (PB4), U9.1 (SDB)
MCU_RXD1: J1.2, U1.19 (PA10/PA11/USB1DM)
MCU_RXD2: J4.2, U7.19 (PA10/PA11/USB1DM)
MCU_TXD1: J1.3, R1.1, U1.18 (PA9)
MCU_TXD2: J4.3, R16.1, U7.18 (PA9)
MCU_USBDP1: J1.1, U1.20 (PA12/USB1DP)
MCU_USBDP2: J4.1, U7.20 (PA12/USB1DP)
MIC_OUT_AMP1: C9.1, R10.2, U1.11 (PA5/ADC5)
MIC_OUT_AMP2: C24.1, R25.2, U7.11 (PA5/ADC5)
unnamed: BT1.2 (-), JP2.1 (A), U5.2 (BM), U5.3 (BM)
unnamed: BT2.2 (-), JP4.1 (A), U11.2 (BM), U11.3 (BM)
unnamed: BZ1.1 (+), D19.3 (K), R4.2
unnamed: BZ1.2 (-), D19.1 (A), Q1.3 (D)
unnamed: BZ2.1 (+), D38.3 (K), R19.2
unnamed: BZ2.2 (-), D38.1 (A), Q3.3 (D)
unnamed: C8.2, R9.1
unnamed: C23.2, R24.1
unnamed: D1.1 (K), U3.8 (OUT1)
unnamed: D2.1 (K), U3.9 (OUT2)
unnamed: D3.1 (K), U3.10 (OUT3)
unnamed: D4.1 (K), U3.12 (OUT4)
unnamed: D5.1 (K), U3.13 (OUT5)
unnamed: D6.1 (K), U3.14 (OUT6)
unnamed: D7.1 (K), U3.15 (OUT7)
unnamed: D8.1 (K), U3.16 (OUT8)
unnamed: D9.1 (K), U3.17 (OUT9)
unnamed: D10.1 (K), U3.19 (OUT10)
unnamed: D11.1 (K), U3.20 (OUT11)
unnamed: D12.1 (K), U3.21 (OUT12)
unnamed: D13.1 (K), U3.22 (OUT13)
unnamed: D14.1 (K), U3.23 (OUT14)
unnamed: D15.1 (K), U3.24 (OUT15)
unnamed: D16.1 (K), U3.26 (OUT16)
unnamed: D17.1 (K), U3.27 (OUT17)
unnamed: D18.1 (K), U3.28 (OUT18)
unnamed: D20.1 (K), U9.8 (OUT1)
unnamed: D21.1 (K), U9.9 (OUT2)
unnamed: D22.1 (K), U9.10 (OUT3)
unnamed: D23.1 (K), U9.12 (OUT4)
unnamed: D24.1 (K), U9.13 (OUT5)
unnamed: D25.1 (K), U9.14 (OUT6)
unnamed: D26.1 (K), U9.15 (OUT7)
unnamed: D27.1 (K), U9.16 (OUT8)
unnamed: D28.1 (K), U9.17 (OUT9)
unnamed: D29.1 (K), U9.19 (OUT10)
unnamed: D30.1 (K), U9.20 (OUT11)
unnamed: D31.1 (K), U9.21 (OUT12)
unnamed: D32.1 (K), U9.22 (OUT13)
unnamed: D33.1 (K), U9.23 (OUT14)
unnamed: D34.1 (K), U9.24 (OUT15)
unnamed: D35.1 (K), U9.26 (OUT16)
unnamed: D36.1 (K), U9.27 (OUT17)
unnamed: D37.1 (K), U9.28 (OUT18)
unnamed: C5.1, JP1.2 (B), U4.4 (BAT)
unnamed: JP2.3 (B), U5.4 (VM)
unnamed: C20.1, JP3.2 (B), U10.4 (BAT)
unnamed: JP4.3 (B), U11.4 (VM)
unnamed: R3.1, U3.5 (ISET)
unnamed: R6.1, U4.1 (PROG)
unnamed: C8.1, U6.1 (OUT)
unnamed: R18.1, U9.5 (ISET)
unnamed: R21.1, U10.1 (PROG)
unnamed: C23.1, U12.1 (OUT)
OPA1_N1: C7.1, R8.1, R9.2, U1.12 (PA6/ADC6)
OPA1_N2: C22.1, R23.1, R24.2, U7.12 (PA6/ADC6)
OPA1_O1: C7.2, R8.2, R10.1, U1.15 (PB1/ADC9)
OPA1_O2: C22.2, R23.2, R25.1, U7.15 (PB1/ADC9)
OPA1_P1: C15.1, R11.2, R15.1, U1.14 (PB0/ADC8)
OPA1_P2: C30.1, R26.2, R30.1, U7.14 (PB0/ADC8)
PERI_EN1: Q2.1 (G), R12.2, U1.10 (PA4/ADC4)
PERI_EN2: Q4.1 (G), R27.2, U7.10 (PA4/ADC4)
RST1: J3.4, U1.4 (NRST)
RST2: J6.4, U7.4 (NRST)
SPEAKER_PWM1: Q1.1 (G), U1.8 (PA2/ADC2)
SPEAKER_PWM2: Q3.1 (G), U7.8 (PA2/ADC2)
SWCLK1: J3.2, U1.22 (PA14/SWCLK)
SWCLK2: J6.2, U7.22 (PA14/SWCLK)
SWDIO1: J3.1, U1.21 (PA13/SWDIO)
SWDIO2: J6.1, U7.21 (PA13/SWDIO)
VAA1: C12.1, C13.1, C14.1, D1.2 (A), D2.2 (A), D3.2 (A), D4.2 (A), D5.2 (A), D6.2 (A), D7.2 (A), D8.2 (A), D9.2 (A), D10.2 (A), D11.2 (A), D12.2 (A), D13.2 (A), D14.2 (A), D15.2 (A), D16.2 (A), D17.2 (A), D18.2 (A), Q2.3 (D), R4.1, R11.1, R13.1, R14.1, U3.2 (AD), U3.3 (VCC), U6.4 (VDD)
VAA2: C27.1, C28.1, C29.1, D20.2 (A), D21.2 (A), D22.2 (A), D23.2 (A), D24.2 (A), D25.2 (A), D26.2 (A), D27.2 (A), D28.2 (A), D29.2 (A), D30.2 (A), D31.2 (A), D32.2 (A), D33.2 (A), D34.2 (A), D35.2 (A), D36.2 (A), D37.2 (A), Q4.3 (D), R19.1, R26.1, R28.1, R29.1, U9.2 (AD), U9.3 (VCC), U12.4 (VDD)
VDD1: SW3.1 (A), U2.3 (EN), U2.4 (VIN)
VDD2: SW6.1 (A), U8.3 (EN), U8.4 (VIN)

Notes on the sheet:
TODOS/FIXES: - [ ] Add Hole in Paste Layer for Toolholes??? - bauteilnamen (1uF fehlt statt 8x2.2uF) - leds wieder auf 0603? - leichtere knöpfe -batterieladen checken - vllt kleineres steckerloch - text, grafik drauf
Microphone + Filter
Adapt Speaker PWM to OD Fix VDD switch for peripherals add caps?
leds
User Buzzer
Bat. Volt. Sense
Use internal OPA
Battery/Power Managment
LED + Driver
MCU
Aux. Device Power Mgmt.
I2C Pullup
User Push Buttons
15mA
for chips
Pogo Pads
Power Rail Decoupling

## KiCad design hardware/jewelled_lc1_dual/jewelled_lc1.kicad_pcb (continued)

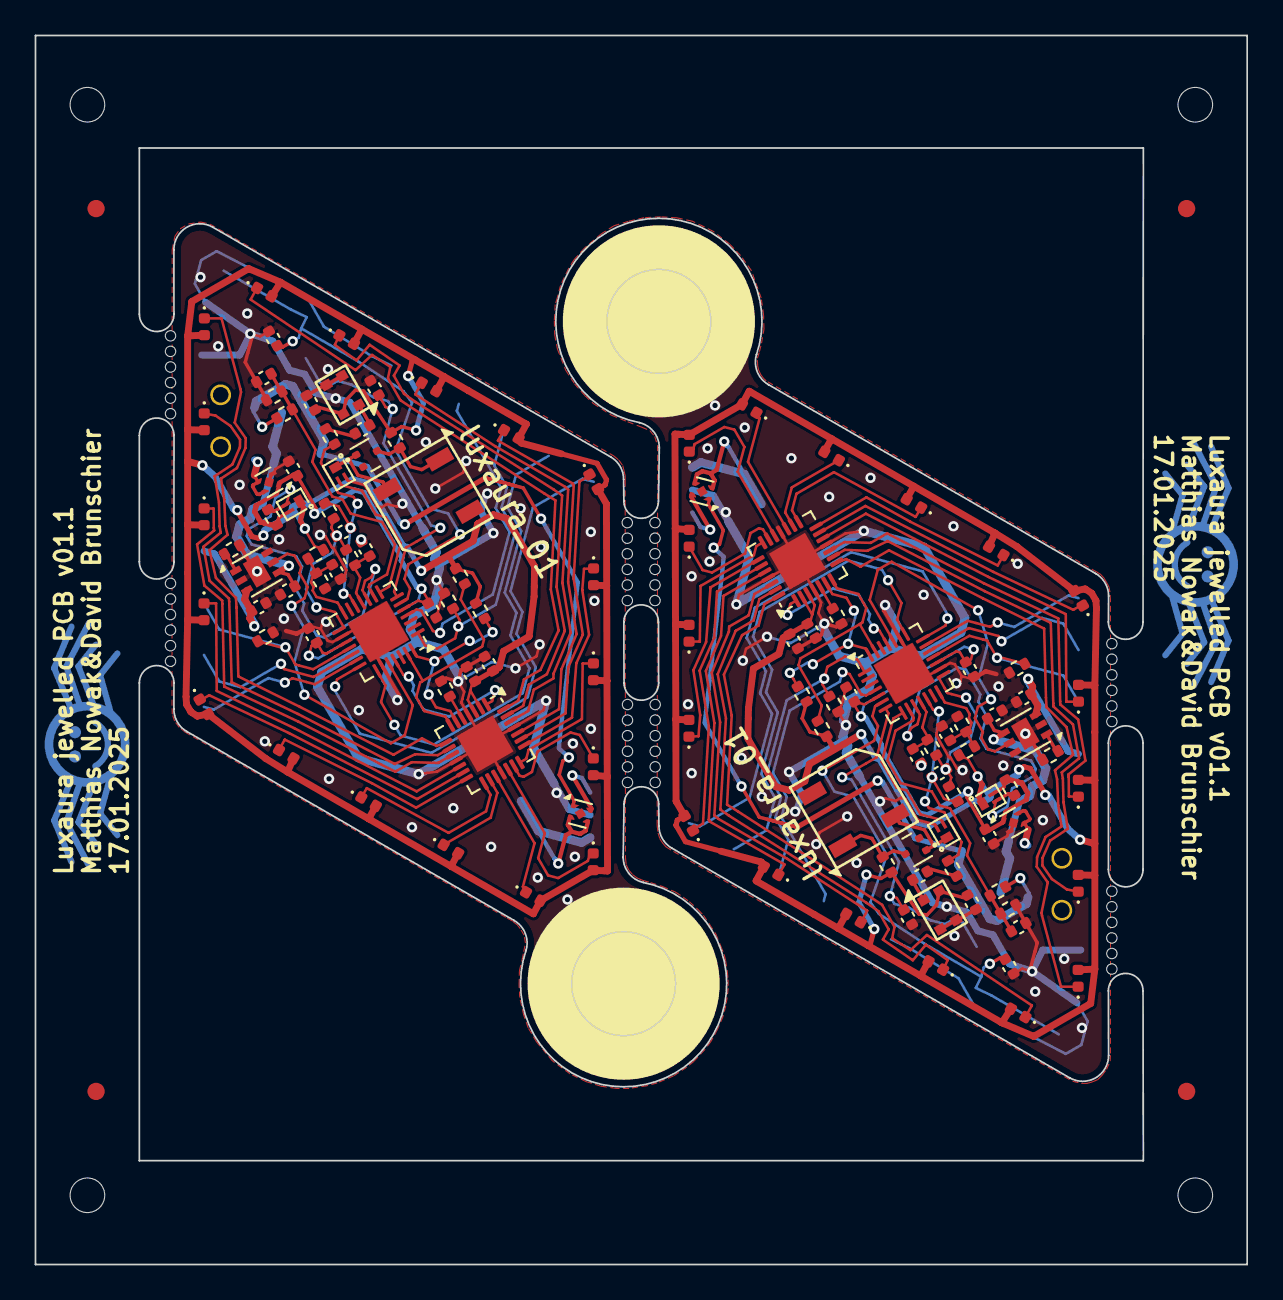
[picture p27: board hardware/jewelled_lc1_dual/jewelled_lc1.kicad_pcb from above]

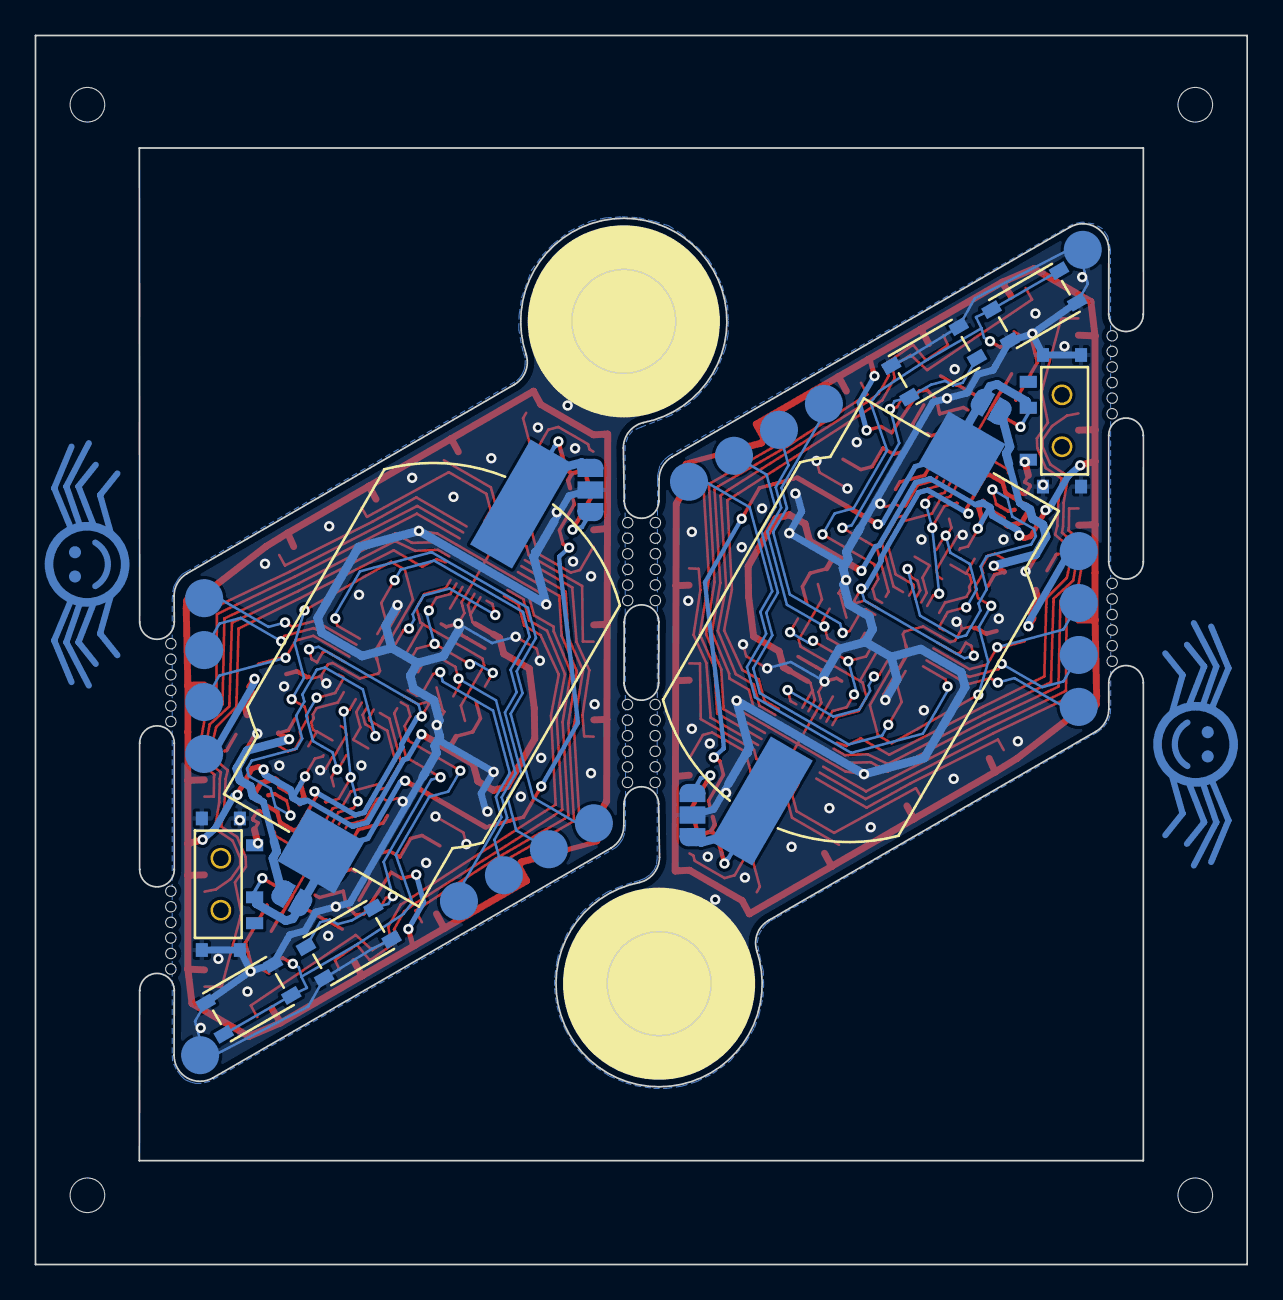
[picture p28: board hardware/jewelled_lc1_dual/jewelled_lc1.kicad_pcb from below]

Board: 2 copper layers, 70.0 x 71.0 mm, 148 parts (18 on the bottom side), 106 nets.

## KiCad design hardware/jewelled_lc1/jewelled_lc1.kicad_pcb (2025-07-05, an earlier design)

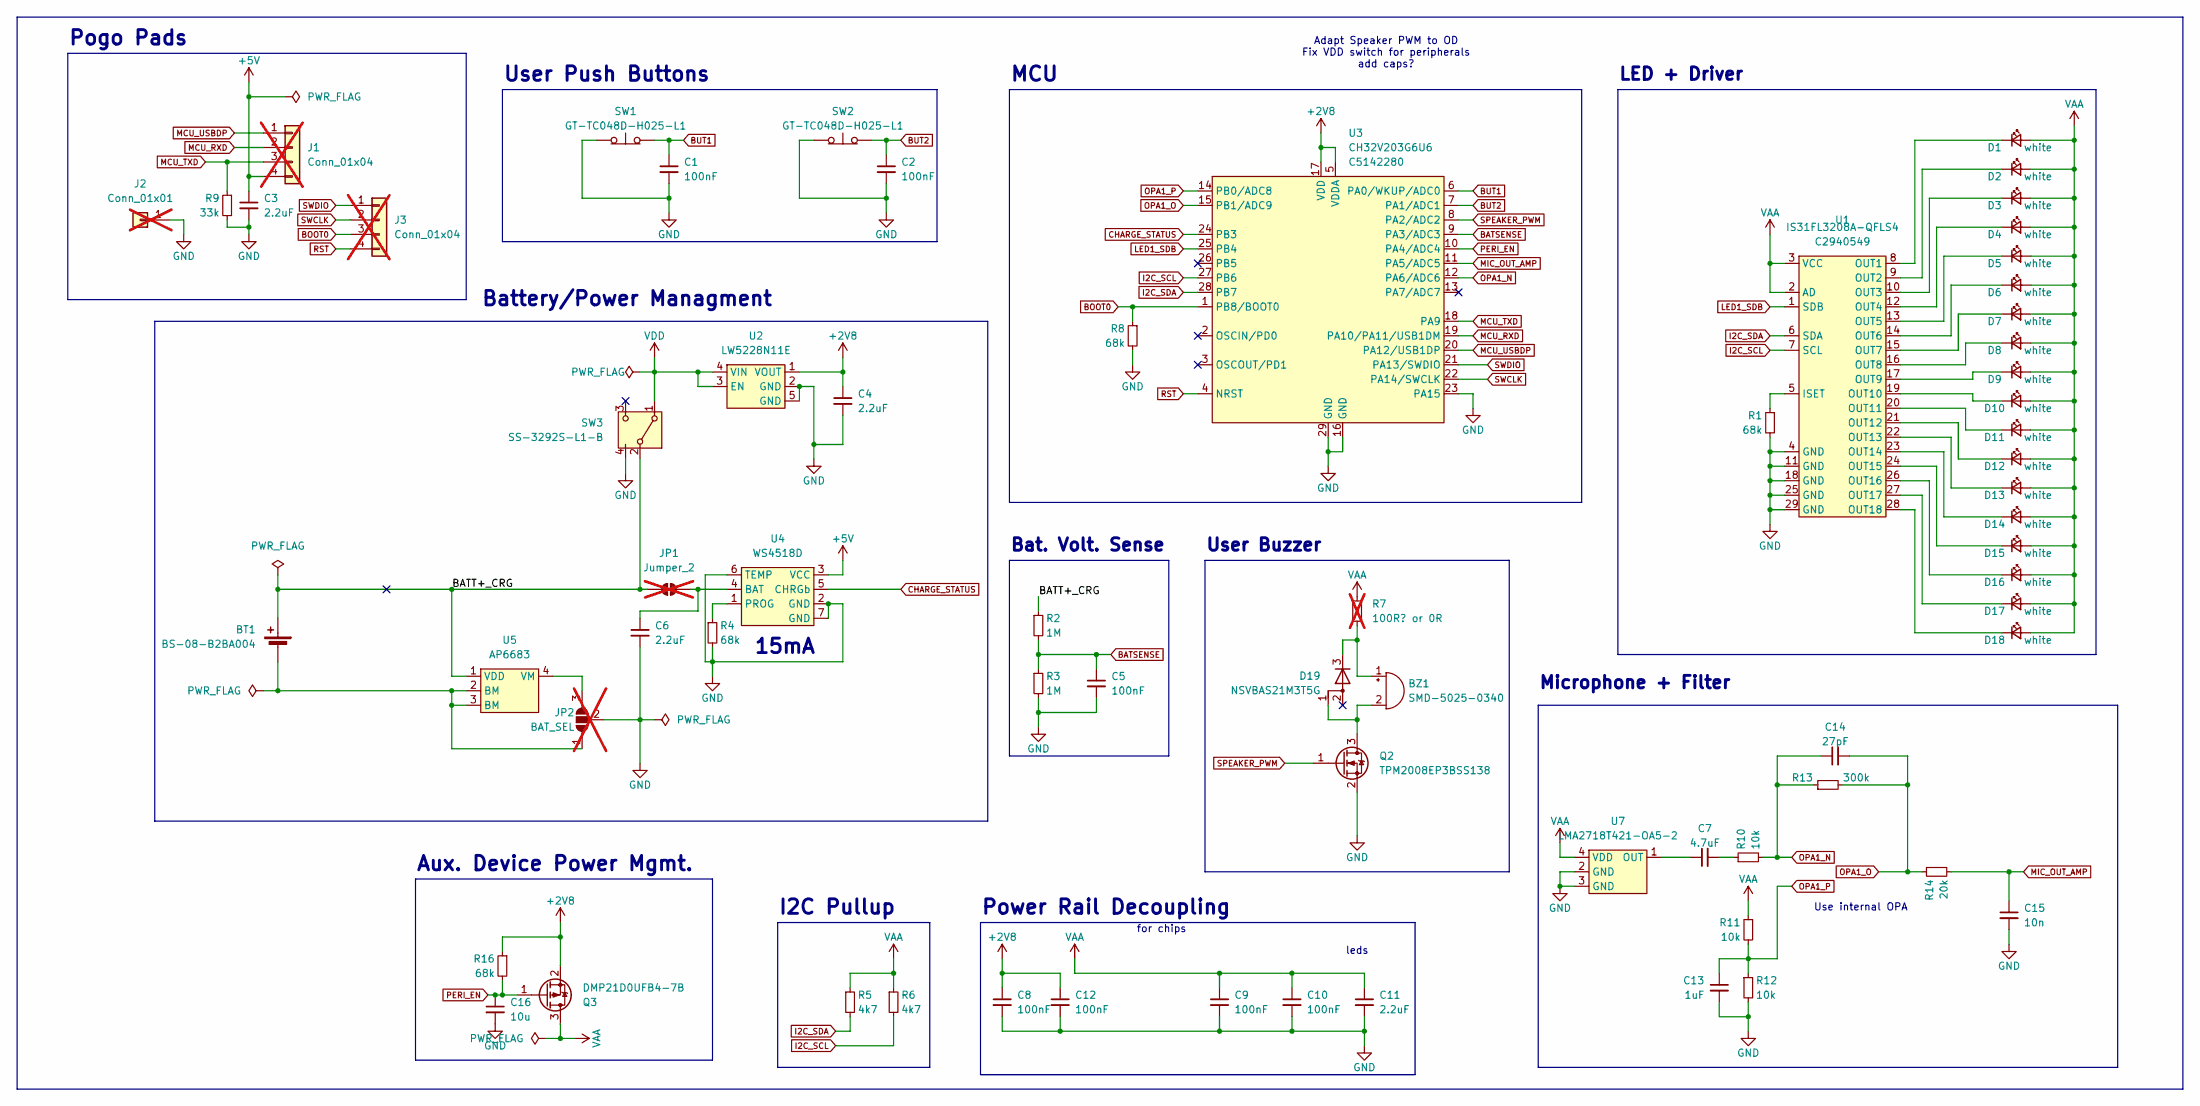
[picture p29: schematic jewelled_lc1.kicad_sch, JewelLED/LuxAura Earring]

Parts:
BT1: BS-08-B2BA004; LCSC C964780
BZ1: SMD-5025-0340
C1, C2, C5, C8, C9, C10, C12: 100nF; C_0402_1005Metric; LCSC C100072
C3, C4, C6, C11: 2.2uF; C_0402_1005Metric; LCSC C14445
C7: 4.7uF; C_0402_1005Metric
C13: 1uF; C_0402_1005Metric
C14: 27pF; C_0402_1005Metric
C15: 10n; C_0402_1005Metric
C16: 10u; C_0402_1005Metric; LCSC C14445
D1, D2, D3, D4, D5, D6, D7, D8, D9, D10, D11, D12, D13, D14, D15, D16, D17, D18: white; LED_0402_1005Metric; LCSC C20613596
D19: NSVBAS21M3T5G; SOT-723; LCSC C896450
J1, J3: Conn_01x04; pogo_conn_01x03_P2.0mm_angled; not fitted
J2: Conn_01x01; pogo_conn_01x01_P2.0mm; not fitted
JP1: Jumper_2; SolderJumper-2_P1.3mm_Open_RoundedPad1.0x1.5mm_NoSilk; not fitted
JP2: BAT_SEL; SolderJumper-3_P1.3mm_Open_RoundedPad1.0x1.5mm_NoSilk; not fitted
Q2: TPM2008EP3BSS138; DFN-3_1.0x0.6mm_P0.35mm; MPN C2682293
Q3: DMP21D0UFB4-7B; DFN-3_1.0x0.6mm_P0.35mm; LCSC C155329
R1, R4, R8, R16: 68k; R_0402_1005Metric
R2, R3: 1M; R_0402_1005Metric; LCSC C26083
R5, R6: 4k7; R_0402_1005Metric; LCSC C25940
R7: 100R? or 0R; R_0402_1005Metric; not fitted
R9: 33k; R_0402_1005Metric; MPN C25779; LCSC C25779
R10, R11, R12: 10k; R_0402_1005Metric
R13: 300k; R_0402_1005Metric
R14: 20k; R_0402_1005Metric
SW1, SW2: GT-TC048D-H025-L1; LCSC C843674
SW3: SS-3292S-L1-B; LCSC C2681570
U1: IS31FL3208A-QFLS4; QFN-28-1EP_4x4mm_P0.4mm_EP2.4x2.4mm; MPN C2940549; LCSC C2940551
U2: LW5228N11E; UDFN-4-1EP_1x1mm_P0.65mm_EP0.48x0.48mm; LCSC C20630428
U3: CH32V203G6U6; QFN-28-1EP_4x4mm_P0.4mm_EP2.6x2.6mm; MPN C5142280; LCSC C5142280
U4: WS4518D; DFN-6-1EP_2x2mm_P0.65mm_EP1x1.6mm; LCSC C910991
U5: AP6683; UDFN-4-1EP_1x1mm_P0.65mm_EP0.48x0.48mm; LCSC C2849565
U7: LMA2718T421-OA5-2; ZTS6117H; LCSC C2999748

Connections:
+2V8: C4.1, C8.1, C12.1, Q3.2 (S), R16.1, U2.1 (VOUT), U3.5 (VDDA), U3.17 (VDD)
+5V: C3.1, J1.4, U4.3 (VCC)
/BATT+_CRG: BT1.1 (+), JP1.1 (A), R2.1, SW3.2 (B), U5.1 (VDD)
BATSENSE: C5.1, R2.2, R3.1, U3.9 (PA3/ADC3)
BOOT0: J3.3, R8.1, U3.1 (PB8/BOOT0)
BUT1: C1.1, SW1.2 (B), U3.6 (PA0/WKUP/ADC0)
BUT2: C2.1, SW2.2 (B), U3.7 (PA1/ADC1)
CHARGE_STATUS: U3.24 (PB3), U4.5 (CHRGb)
GND: C1.2, C2.2, C3.2, C4.2, C5.2, C6.2, C8.2, C9.2, C10.2, C11.2, C12.2, C13.2, C15.2, C16.2, J2.1, JP2.2 (C), Q2.2 (S), R1.2, R3.2, R4.2, R8.2, R9.2, R12.2, SW1.1 (A), SW2.1 (A), SW3.4 (B), U1.4 (GND), U1.11 (GND), U1.18 (GND), U1.25 (GND), U1.29 (GND), U2.2 (GND), U2.5 (GND), U3.16 (GND), U3.23 (PA15), U3.29 (GND), U4.2 (GND), U4.6 (TEMP), U4.7 (GND), U7.2 (GND), U7.3 (GND)
I2C_SCL: R6.2, U1.7 (SCL), U3.27 (PB6)
I2C_SDA: R5.2, U1.6 (SDA), U3.28 (PB7)
LED1_SDB: U1.1 (SDB), U3.25 (PB4)
MCU_RXD: J1.2, U3.19 (PA10/PA11/USB1DM)
MCU_TXD: J1.3, R9.1, U3.18 (PA9)
MCU_USBDP: J1.1, U3.20 (PA12/USB1DP)
MIC_OUT_AMP: C15.1, R14.2, U3.11 (PA5/ADC5)
unnamed: BT1.2 (-), JP2.1 (A), U5.2 (BM), U5.3 (BM)
unnamed: BZ1.1 (+), D19.3 (K), R7.2
unnamed: BZ1.2 (-), D19.1 (A), Q2.3 (D)
unnamed: C7.2, R10.1
unnamed: D1.1 (K), U1.8 (OUT1)
unnamed: D2.1 (K), U1.9 (OUT2)
unnamed: D3.1 (K), U1.10 (OUT3)
unnamed: D4.1 (K), U1.12 (OUT4)
unnamed: D5.1 (K), U1.13 (OUT5)
unnamed: D6.1 (K), U1.14 (OUT6)
unnamed: D7.1 (K), U1.15 (OUT7)
unnamed: D8.1 (K), U1.16 (OUT8)
unnamed: D9.1 (K), U1.17 (OUT9)
unnamed: D10.1 (K), U1.19 (OUT10)
unnamed: D11.1 (K), U1.20 (OUT11)
unnamed: D12.1 (K), U1.21 (OUT12)
unnamed: D13.1 (K), U1.22 (OUT13)
unnamed: D14.1 (K), U1.23 (OUT14)
unnamed: D15.1 (K), U1.24 (OUT15)
unnamed: D16.1 (K), U1.26 (OUT16)
unnamed: D17.1 (K), U1.27 (OUT17)
unnamed: D18.1 (K), U1.28 (OUT18)
unnamed: C6.1, JP1.2 (B), U4.4 (BAT)
unnamed: JP2.3 (B), U5.4 (VM)
unnamed: R1.1, U1.5 (ISET)
unnamed: R4.1, U4.1 (PROG)
unnamed: C7.1, U7.1 (OUT)
OPA1_N: C14.1, R10.2, R13.1, U3.12 (PA6/ADC6)
OPA1_O: C14.2, R13.2, R14.1, U3.15 (PB1/ADC9)
OPA1_P: C13.1, R11.2, R12.1, U3.14 (PB0/ADC8)
PERI_EN: C16.1, Q3.1 (G), R16.2, U3.10 (PA4/ADC4)
RST: J3.4, U3.4 (NRST)
SPEAKER_PWM: Q2.1 (G), U3.8 (PA2/ADC2)
SWCLK: J3.2, U3.22 (PA14/SWCLK)
SWDIO: J3.1, U3.21 (PA13/SWDIO)
VAA: C9.1, C10.1, C11.1, D1.2 (A), D2.2 (A), D3.2 (A), D4.2 (A), D5.2 (A), D6.2 (A), D7.2 (A), D8.2 (A), D9.2 (A), D10.2 (A), D11.2 (A), D12.2 (A), D13.2 (A), D14.2 (A), D15.2 (A), D16.2 (A), D17.2 (A), D18.2 (A), Q3.3 (D), R5.1, R6.1, R7.1, R11.1, U1.2 (AD), U1.3 (VCC), U7.4 (VDD)
VDD: SW3.1 (A), U2.3 (EN), U2.4 (VIN)

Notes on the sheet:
leds
User Push Buttons
Use internal OPA
Microphone + Filter
MCU
User Buzzer
Pogo Pads
Battery/Power Managment
15mA
Adapt Speaker PWM to OD Fix VDD switch for peripherals add caps?
LED + Driver
Power Rail Decoupling
Aux. Device Power Mgmt.
I2C Pullup
for chips
Bat. Volt. Sense

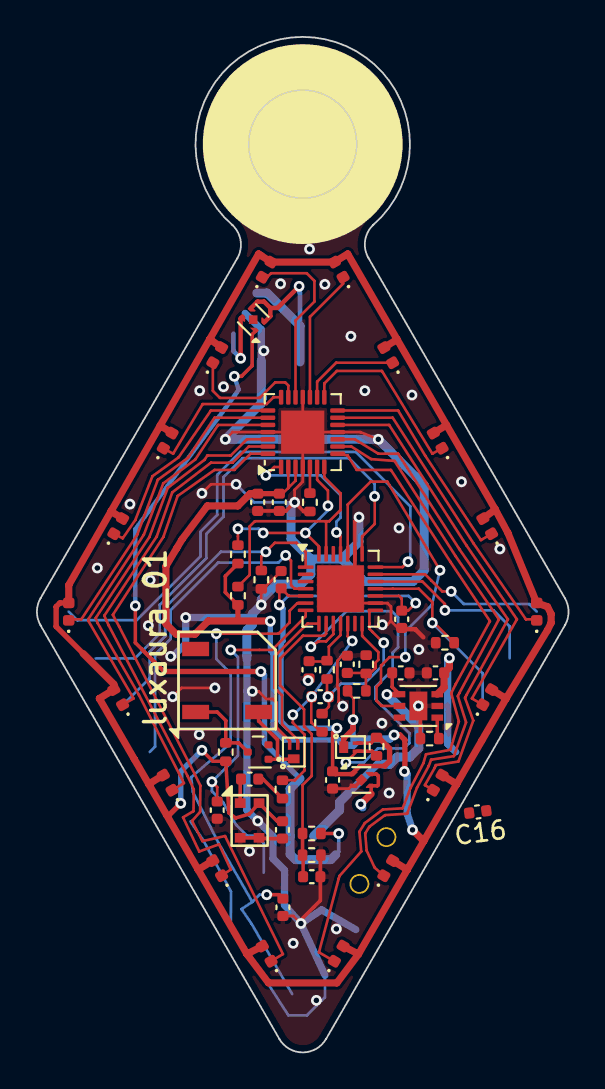
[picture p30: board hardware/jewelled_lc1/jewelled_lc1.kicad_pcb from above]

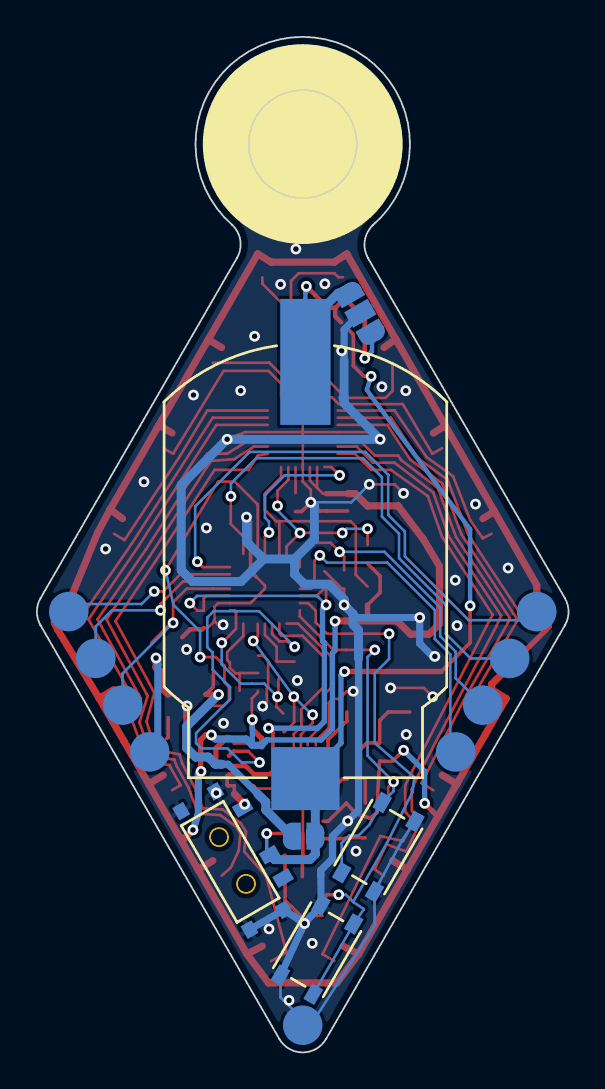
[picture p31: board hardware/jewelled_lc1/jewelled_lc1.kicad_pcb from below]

Board: 2 copper layers, 29.5 x 56.4 mm, 68 parts (9 on the bottom side), 53 nets.

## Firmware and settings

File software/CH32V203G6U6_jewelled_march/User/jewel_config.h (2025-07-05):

/*
 * config.h
 *
 *  Created on: 3 Mar 2025
 *      Author: matth
 */

#include "ch32v20x.h"
#include "ch32v20x_conf.h"

#ifndef USER_JEWEL_CONFIG_H_
#define USER_JEWEL_CONFIG_H_

/* Global define */
#define true 1
#define false 0

#define IO_OPA_P_PORT GPIOB
#define IO_OPA_P_PIN GPIO_Pin_0
#define IO_OPA_N_PORT GPIOA
#define IO_OPA_N_PIN GPIO_Pin_6
#define IO_OPA_O_PORT GPIOB
#define IO_OPA_O_PIN GPIO_Pin_1
#define IO_MICOUT_PORT GPIOA
#define IO_MICOUT_PIN GPIO_Pin_5

#define IO_BUT1_PORT GPIOA
#define IO_BUT1_PIN GPIO_Pin_0
#define IO_BUT2_PORT GPIOA
#define IO_BUT2_PIN GPIO_Pin_1
#define IO_PERI_PORT GPIOA
#define IO_PERI_PIN GPIO_Pin_4
#define IO_BUZZ_PORT GPIOA
#define IO_BUZZ_PIN GPIO_Pin_2
#define IO_BAT_PORT GPIOA
#define IO_BAT_PIN GPIO_Pin_3
#define IO_CHARGE_PORT GPIOB
#define IO_CHARGE_PIN GPIO_Pin_3

#define IO_BOOT0_PORT GPIOB
#define IO_BOOT0_PIN GPIO_Pin_8
#define IO_SCL_PORT GPIOB
#define IO_SCL_PIN GPIO_Pin_6
#define IO_SDA_PORT GPIOB
#define IO_SDA_PIN GPIO_Pin_7
#define IO_LED_SDB_PORT GPIOB
#define IO_LED_SDB_PIN GPIO_Pin_4
#define IO_TX_PORT GPIOA
#define IO_TX_PIN GPIO_Pin_9
#define IO_RX_PORT GPIOA
#define IO_RX_PIN GPIO_Pin_10
#define IO_USB_N_PORT GPIOA
#define IO_USB_N_PIN GPIO_Pin_11
#define IO_USB_P_PORT GPIOA
#define IO_USB_P_PIN GPIO_Pin_12

#define ADC_MICOUT_CH ADC_Channel_5
#define ADC_MICOUT_ADC ADC1
#define ADC_BAT_CH ADC_Channel_3
#define ADC_BAT_ADC ADC2

#define DEBUG_ENABLED 0
#define I2C_CLOCK_SPEED      400000      // 400kHz
#define LED_DRIVER_ADDR      0x60        // Example address, adjust as needed

#define LED_COUNT 18
#define LED_GLOBAL_CURRENT 0x13 // Imax * [0x10=1];[0x11=11/12];[0x12=9/12];[0x13=7/12]
#define LED_USEGAMMA64 // automatically scales 0-255 to 0-63
//#define LED_USEGAMMA32 // automatically scales 0-255 to 0-31
//#define LED_USENOGAMMA // range 0-255
#define LED_PWM_DIV_1 // divides (post-gamma) input in the driver by this int
//#define LED_PWM_DIV_2 // TODO: save ~1-2mA, maybe switch "dynamically" when battery drains?
//#define LED_PWM_DIV_4

#define ANIM_FPS 120
#define ANIM_DEFAULT_BPM 120
extern volatile uint16_t anim_bps;

#define RAND_A 1664525
#define RAND_C 1013904223
#define RAND_M 4294967296 // maybe 1 lower?


/* global variables */
extern volatile uint32_t system_ticks;

void init_rand(void);
uint32_t rand(void);

#endif /* USER_JEWEL_CONFIG_H_ */

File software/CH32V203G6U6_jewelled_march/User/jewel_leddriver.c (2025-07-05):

/*
 * jewel_leddriver.c
 *
 *  Created on: 4 Mar 2025
 *      Author: matth
 */

#include "jewel_leddriver.h"


const uint8_t gamma64 [64] = {
    0,1,2,3,4,5,6,7,8,10,12,14,16,18,20,22,24,26,29,32,35,38,41,44,47,50,53,57,61,65,69,73,77,81,85,89,94,99,104,109,114,119,124,129,134,140,146,152,158,164,170,176,182,188,195,202,209,216,223,230,237,244,251,255
};

const uint8_t gamma64_div2 [64] = {
        0,0,1,1,2,2,3,3,4,4,5,6,6,7,7,8,8,10,10,12,12,14,14,16,16,18,18,20,20,22,22,24,24,26,26,29,29,32,32,35,35,38,38,41,41,44,44,47,47,50,50,53,57,57,61,61,65,65,69,73,73
};

const uint8_t gamma64_div22 [64] = {
        0,0,1,1,2,2,3,3,4,5,6,7,8,9,10,11,12,13,24,16,17,19,20,22,23,25,26,28,30,32,34,36,38,40,42,44,47,49,52,54,57,59,62,64,67,70,73,76,79,82,85,88,91,94,74,101,104,108,111,115,118,122,125,127
};

const uint8_t gamma32 [32] = {
    0,1,2,4,6,10,13,18,22,28,33,39,46,53,61,69,78,86,96,106,116,126,138,149,161,173,186,199,212,226,240,255
};

void LEDDriver_Init_Config(void) {
    I2C_Init_Config();

    // Turn on Driver
    GPIO_WriteBit(IO_LED_SDB_PORT, IO_LED_SDB_PIN, Bit_SET);

    // Reset
    I2C_WriteReg(DRV_ADDR, DRV_REG_RESET, DRV_REGVAL_RESET);

    // Turn on Software shutdown
    I2C_WriteReg(DRV_ADDR, DRV_REG_SHUTDOWN, DRV_REGVAL_SSD_ON);

    //set pwm registers to 0 and global current
    for(uint8_t i = 0; i < LED_COUNT; i++) {
        I2C_WriteReg(DRV_ADDR, DRV_REG_PWM_BASE + i, 0);
        I2C_WriteReg(DRV_ADDR, DRV_REG_CURRENT + i, LED_GLOBAL_CURRENT);
    }

    // Turn off global led control
    I2C_WriteReg(DRV_ADDR, DRV_REG_GLOBAL, DRV_REGVAL_GLOBALLED_OFF);

    // set frequency
    I2C_WriteReg(DRV_ADDR, DRV_REG_FREQUENCY, DRV_REGVAL_FREQ_23K);

    //call driver update
    I2C_WriteReg(DRV_ADDR, DRV_REG_UPDATE, DRV_REGVAL_UPDATE);
}

// Call update to copy temp vals to live registers
void LEDDriver_Update(void) {
    I2C_WriteReg(DRV_ADDR, DRV_REG_UPDATE, DRV_REGVAL_UPDATE);
}

// Write LED values to temporary registers
void LEDDriver_UpdateLEDsTemp(uint8_t* vals) {
    for(uint8_t i = 0; i < LED_COUNT; i++) {
        LEDDriver_UpdateSingleLEDTemp(i, vals[i]);
    }
}

// Write LED values to temporary registers
void LEDDriver_UpdateSingleLEDTemp(uint8_t lednum, uint8_t val) {
#ifdef LED_USEGAMMA64
    #ifdef LED_PWM_DIV_1
            I2C_WriteReg(DRV_ADDR, DRV_REG_PWM_BASE + lednum, gamma64[(uint8_t)(val/4)]);
    #endif
    #ifdef LED_PWM_DIV_2
            I2C_WriteReg(DRV_ADDR, DRV_REG_PWM_BASE + lednum, gamma64_div2[(uint8_t)(val/4)]);
    #endif
    #ifdef LED_PWM_DIV_22
            I2C_WriteReg(DRV_ADDR, DRV_REG_PWM_BASE + lednum, gamma64_div22[(uint8_t)(val/4)]);
    #endif
#endif
#ifdef LED_USEGAMMA32
        I2C_WriteReg(DRV_ADDR, DRV_REG_PWM_BASE + lednum, gamma64[(uint8_t)(val/8)]/LED_PWM_DIV);
#endif
#ifdef LED_USENOGAMMA
        I2C_WriteReg(DRV_ADDR, DRV_REG_PWM_BASE + lednum, val/LED_PWM_DIV);
#endif
}

// Write LED values to temporary registers
void LEDDriver_UpdateAllTemp(uint8_t val) {
    for(uint8_t i = 0; i < LED_COUNT; i++) {
        LEDDriver_UpdateSingleLEDTemp(i, val);
    }
}

void LEDDriver_Sleep(void) {
    I2C_WriteReg(DRV_ADDR, DRV_REG_GLOBAL, DRV_REGVAL_GLOBALLED_OFF);
    I2C_WriteReg(DRV_ADDR, DRV_REG_SHUTDOWN, DRV_REGVAL_SSD_ON);
}

void LEDDriver_Wakeup(void) {
    I2C_WriteReg(DRV_ADDR, DRV_REG_SHUTDOWN, DRV_REGVAL_SSD_OFF);
    I2C_WriteReg(DRV_ADDR, DRV_REG_GLOBAL, DRV_REGVAL_GLOBALLED_ON);
}

void I2C_Init_Config(void) {
    I2C_InitTypeDef I2C_InitStructure;

    /* Enable I2C clock */
    RCC_APB1PeriphClockCmd(RCC_APB1Periph_I2C1, ENABLE);

    /* I2C configuration */
    I2C_InitStructure.I2C_ClockSpeed = I2C_CLOCK_SPEED;
    I2C_InitStructure.I2C_Mode = I2C_Mode_I2C;
    I2C_InitStructure.I2C_DutyCycle = I2C_DutyCycle_2;
    I2C_InitStructure.I2C_OwnAddress1 = 0x00;
    I2C_InitStructure.I2C_Ack = I2C_Ack_Enable;
    I2C_InitStructure.I2C_AcknowledgedAddress = I2C_AcknowledgedAddress_7bit;

    /* Initialize I2C */
    I2C_Init(I2C1, &I2C_InitStructure);
    I2C_Cmd(I2C1, ENABLE);

    if(DEBUG_ENABLED) {
        //UART_Printf("I2C Initialized at %dkHz\n", I2C_CLOCK_SPEED/1000);
    }
}

void I2C_DeInit_Config(void) {
    I2C_DeInit(I2C1);
}

void I2C_Write(uint8_t addr, uint8_t* data, uint8_t len) {
    /* Wait until I2C bus is free */
    while(I2C_GetFlagStatus(I2C1, I2C_FLAG_BUSY));

    /* Generate START condition */
    I2C_GenerateSTART(I2C1, ENABLE);
    while(!I2C_CheckEvent(I2C1, I2C_EVENT_MASTER_MODE_SELECT));

    /* Send slave address */
    I2C_Send7bitAddress(I2C1, addr << 1, I2C_Direction_Transmitter);
    while(!I2C_CheckEvent(I2C1, I2C_EVENT_MASTER_TRANSMITTER_MODE_SELECTED));

    /* Send data */
    for(uint16_t i = 0; i < len; i++) {
        I2C_SendData(I2C1, data[i]);
        while(!I2C_CheckEvent(I2C1, I2C_EVENT_MASTER_BYTE_TRANSMITTED));
    }

    /* Generate STOP condition */
    I2C_GenerateSTOP(I2C1, ENABLE);
}

void I2C_WriteReg(uint8_t addr, uint8_t reg, uint8_t value) {
    uint8_t data[2] = {reg, value};
    I2C_Write(addr, data, 2);
}

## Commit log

2025-07-05 added jewelled single version hardware
    [jewelled_lc1-B_Cu.gbr, jewelled_lc1-B_Fab.gbr, jewelled_lc1-B_Mask.gbr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]
2025-07-05 added jewelled dual version hardware
    [jewelled_lc1-B_Cu.gbr, jewelled_lc1-B_Fab.gbr, jewelled_lc1-B_Mask.gbr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]
2025-07-05 added jewelled charging board hardware
    [jewelled_lc1_chargerProgrammer.kicad_pcb, jewelled_lc1_chargerProgrammer.kicad_sch, jewelled_lc1_chargerProgrammer.step]
2025-07-05 added WIP Software/Firmware for charging board
